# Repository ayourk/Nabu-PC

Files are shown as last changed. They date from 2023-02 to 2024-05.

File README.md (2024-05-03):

# Nabu-PC
PCB Schematics for the Nabu PC

Using KiCAD 6.0.x for this project.  I will accept pull requests against this version only.
Work still needs to be done to route the traces and connect the nets as well as add all of the capacitors, resistors, etc.  The goal of the chip layout in the schematic is to have the chip location to be roughly where it is on the physical board. I've been associating Datasheets and Footprints with all of my Symbols.  For cases of where I need custom symbols, I've been putting them in the local Nabu-PC library.

Please note that the `Docs/Nabu_Computer_Technical_Manual_by_MJP-compressed.pdf` does contain a vague schematic starting on page 18 of the PDF.  The goal of this project is to improve upon that by giving specific IC pin numbers to the the various similar symbols' inputs and outputs.

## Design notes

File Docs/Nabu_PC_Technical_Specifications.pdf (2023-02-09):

u

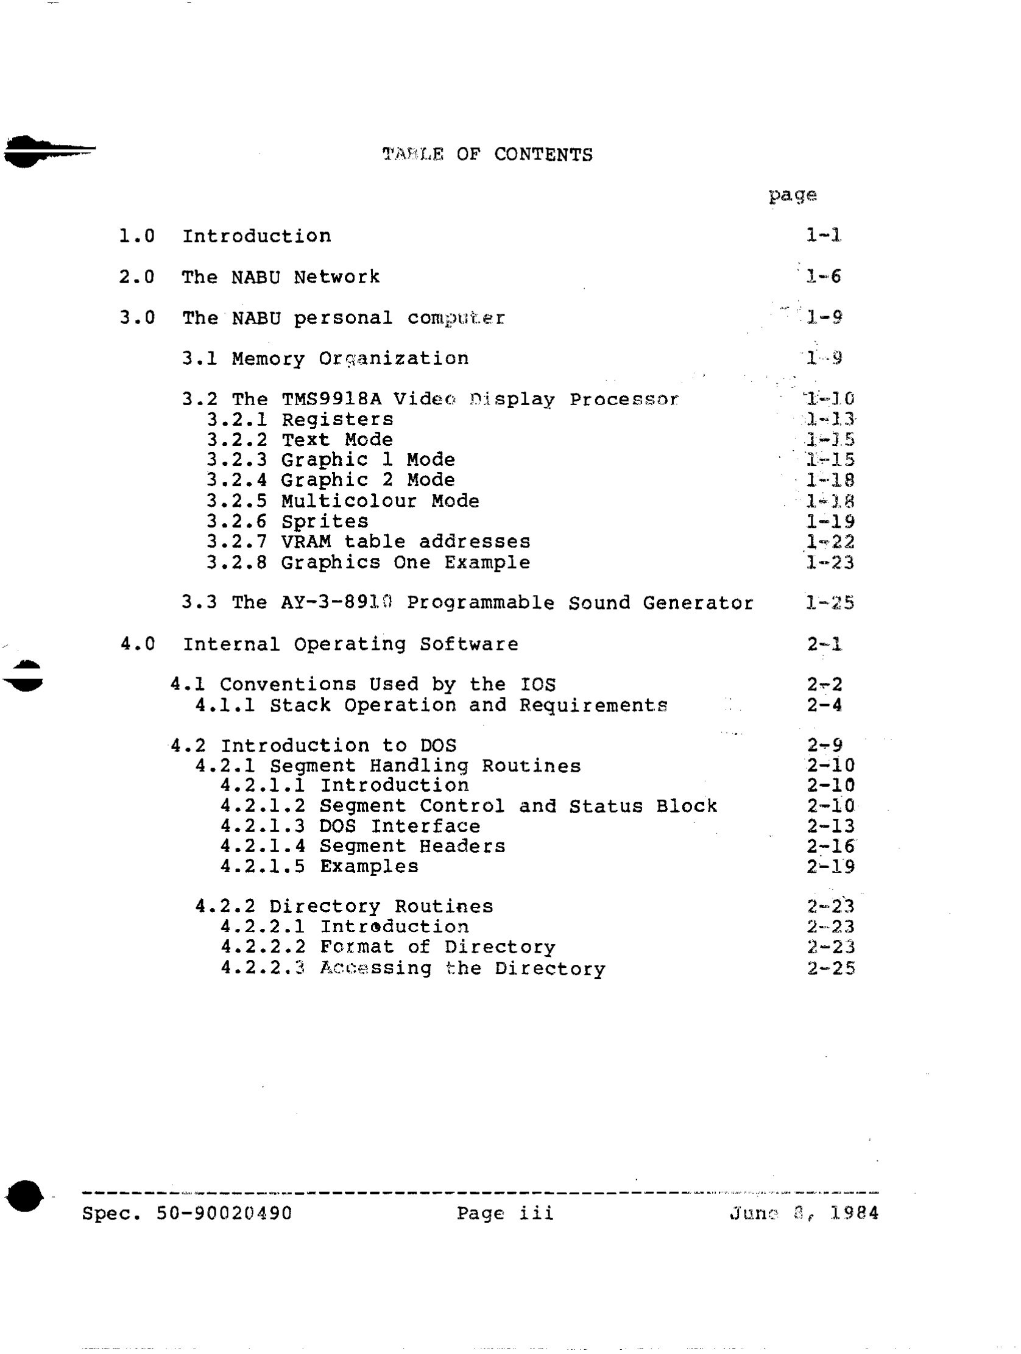
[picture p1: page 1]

n

•

'l'API,E OF CONTENTS

1.0 | Introduction
2.0 | The NABU Network
3.0 | The NABU personal computer:
| 3.1 Memory Orsanization 3.2 The TMS9918A Video n:lsplay Processor· 3.2.1 Registers
3. 2. 2 Text Mode
| 3.2.3 Graphic 1 Mode 3.2.4 Graphic 2 Mode 3.2.5 Multicolour Mode 3.2.6 Sprites 3.2.7 VRAM table addresses 3.2.8 Graphics One Example

page

1-1

l-6

1-9
·1-9

. "1··10
1-J:l
1-15
. 1~15
. 1-·18
1"'18
1-19
.1··22
1··23
3.3 The AY-3-8910 Programmable Sound Generator | 1-25
4.0 | Internal Operating Software
4.1 Conventions Used by the IOS
4.1.1 Stack Operation and Requirements
4.2 Introduction to DOS | 2-9
4.2.1 Segment Handling Routines | 2-10
4.2.1.1 Introduction | 2-10
4.2.1.2 Segment Control and Status Block | 2-10
4.2.1.3 DOS Interface | 2-13
4.2.1.4 Segment Headers | 2-16
4.2.1.5 Examples | 2:...19
4.2.2 Directory Routines | 2-23
4.2.2.1 Intr~duction | 2-23
4.2.2.2 Format of Directory | 2-23
4.2.2.3 Accessing the Directory | 2-25
Spec. 50-90020490 | Page iii | J·unc 8, 1984

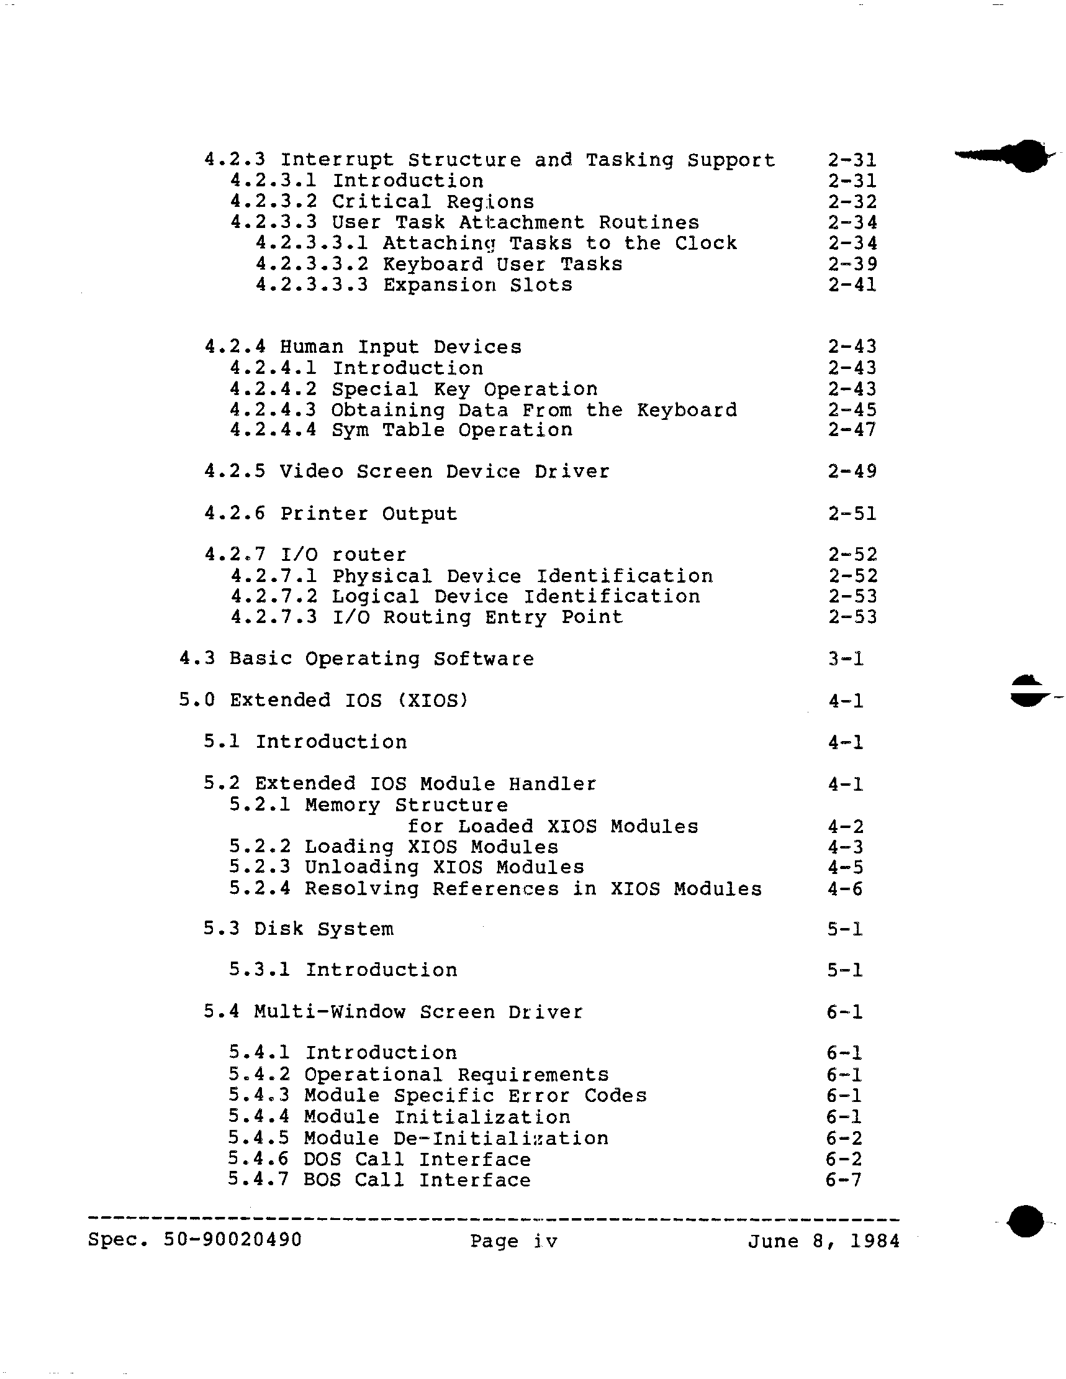
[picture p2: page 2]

4.2.3 Interrupt Structure and Tasking support 4.2.3.1 Introduction
4.2.3.2 Critical Regions
4.2.3.3 User Task Attachment Routines 4.2.3.3.1 Attachin~! Tasks to the Clock 4.2.3.3.2 Keyboard User Tasks 4.2.3.3.3 Expansion Slots

2-31
2-31
2-32
2-34
2-34
2-39
2-41
4.2.4 Human Input Devices | 2-43
4.2.4.1 Introduction | 2-43
4.2.4.2 Special Key Operation | 2-43
4.2.4.3 Obtaining Data From the Keyboard | 2-45
4.2.4.4 Sym Table Operation | 2-47

4.2.5 Video Screen Device Driver

4.2.6 Printer Output
4.2.7 I/O router
4.2.7.1 Physical Device Identification 4.2.7.2 Logical Device Identification 4.2.7.3 I/O Routing Entry Point

4.3 Basic Operating Software

5.0 Extended IOS (XIOSJ

5.1 Introduction

2-49

2-51
2-52
2-52
2-53
2-53

3-1

4-1

4-1
5.2 Extended IOS Module Handler | 4-1
5.2.1 Memory Structure
for Loaded XIOS Modules | 4-2
5. 2. 2 Loading XIOS Modules | 4-3
5.2.3 Unloading XIOS Modules | 4-5
5.2.4 Resolving References in XIOS Modules | 4-6
5.3 Disk System
5.3.1 Introduction

5.4 Multi-Window Screen Driver 5.4.1 Introduction
5.4.2 Operational Requirements 5.4.3 Module Specific Error Codes 5.4.4 Module Initialization
5.4.5 Module De-Initiali:~ation
5.4.6 DOS Call Interface
5.4.7 BOS Call Interface
Spec. 50-90020490 | Page j v

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
June a, 1984 | ••••

•

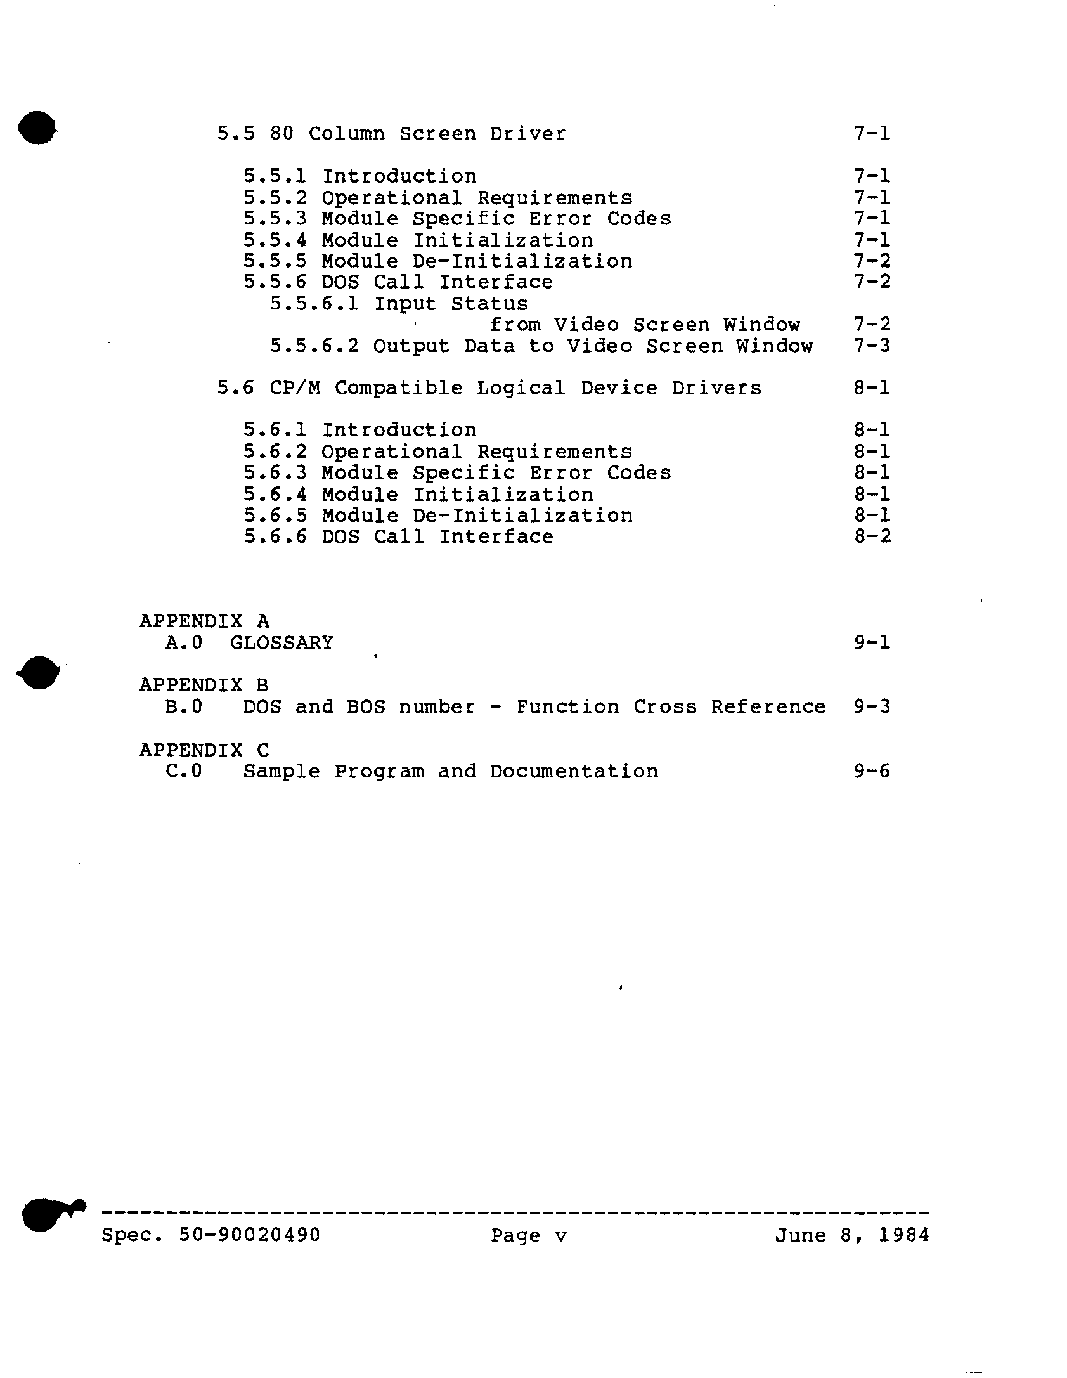
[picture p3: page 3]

•

5.5 80 Column Screen Driver | 7-1
5.5.1 Introduction | 7-1
5.5.2 Operational Requirements | 7-1
5.5.3 Module Specific Error Codes | 7-1
5.5.4 Module Initialization | 7-1
5.5.5 Module De-Initialization | 7-2
5.5.6 DOS Call Interface | 7-2
5.5.6.1 Input Status
from Video Screen Window | 7-2
5.5.6.2 Output Data to Video Screen Window | 7-3
5.6 CP/M Compatible Logical Device Drivers | 8-1
5.6.1 Introduction
5.6.2 Operational Requirements
5.6.3 Module Specific Error Codes
5.6.4 Module Initialization 5.6.5 Module De-Initialization 5.6.6 DOS Call Interface

APPENDIX A
A.O GLOSSARY
APPENDIX B

8-1
8-1
8-1
8-1
8-1
8-2

9-1

B.O DOS and BOS number - Function Cross Reference 9-3 APPENDIX C
C.O | Sample Program and Documentation | 9-6
Spec. 50-90020490 | Page v | June 8, 1984

•

THIS PAGE LEFT INTENTIONALLY BLANK
•
Spec. 50-90020490 | Page vi | June 8, 1984

•

•

INTRODUCTION

1.0 INTRODUCTION
This document is intended to provide the application programmer
the | necessary | information and reference material to write
application programs for the NABU personal computer. | Complete
programm~ng | information on the internal operating software (!OS)
as well as programming information of the Video display processor and the programmable sound generator are included.

One of the aims of this manual was to collect all the information that was previously found in several documents into just one. Although this has yielded a document of some 200 pages, each section discusses a single concept related to the programming
environment | at NABU. | Therefore the programmer need | only
investigate the portions of interest and not have to | read the
entire manual.
In order to put the IOS into perspective, | we include here a
section | from | the | !OS Specification which spells out | the
general functional requirements of IOS. | This will enable you to
judge | what to expect | from | the | Internal Operating System.
DESIGN REQUIREMENTS

Overview

This design | specification defines the | Internal Operating
Software (!OS) for the NABU Personal Computer (NPC), | a | low-
cost, | expandable personal computer. | It is unique because it
is capable of communicating on one-way, | hybrid and two-way
cable systems and telephone networks, as well as operating in a stand-alone mode, depending on which options are selected. When used in association with a CATV network the NABU P.C.'s prime function is to run software downline loaded from the cable head-end.
A versatile set of internal operating system and device handling software is required for the NABU P.C. to run appli-
cations software under control of a user. | For definition and
development purposes this software, | collectively referred to
as the Internal Operating Software (!OS) consists of:

o Applications program interfaces to !OS facilities
o All physical device control and I/0 handlers
o Basic task controlling and interrupt handling software o Communications Software
Spec. 50-90020490 | Page 1 - 1 | June 8, 1984

INTRODUCTION

The internal operating software does NOT include:
o Human Interface for Selection of Applications Programs
o Any ROM Software in the NPC
o Programming languages | (eg. | BASIC is not part of the
operating system.)
o Monitors <ie. examine and change memory, etc., etc. ,etc) o High-level <user oriented) utilities

Operating Environment

The | IOS must interact with four other functional | components
of the NABU P.c •. These are:
o The Basic NABU P.C. hardware
o Optional hardware and peripheral devices
o Communications with external systems,
including the keyboard and NABU Adaptor (NA)
o Applications Software
It | is | the | requirements and functions of these components
which essentially define the requirements for the IOS.

Internal Operating Software Requirements

The | fundamental | requirement of the | Internal | Operating
Software is to create an environment which supports the loading and execution of applications programs in a simple, efficient manner. The NPC hardware, its peripherals, communi-
cations and the IOS are really just necessary evils | required
to present content to an NPC user. | The IOS provides a stable
interface which allows applications access to the other | NPC
components while hiding the messy details of the hardware configuration and communications protocols, which are really of no interest to applications programs.

IOS Flexibility
In order | to be as flexible as possible, | the | IOS | resides
completely in RAM. | A separate program, | the MAIN MENU pro-
gram, | is | loaded in along with the IOS when the NABU P.C. is
"booted". | The MAIN MENU performs all human interface func-
tions required to load in an application.
Spec. 50-90020490 | Page 1 - 2 | June 8, 1984

•

•

•

•

•

INTRODUCTION

A number of expansion options will be offered for | the NPC •
These options may include: | standalone operation through use
of ROM readers and/or floppy disks, additional communications
options though the use of telephone dialers, | two-way | cable
moderns and other devices, | and the support of various other
peripherals via an I/O expansion bus. | The !OS must be | able
to operate in a configuration independent manner. | This
implies:
o The !OS must be able to sense the NPC configuration when "Booted"
o The IOS should protect the applications from becoming "configuration-dependent"
o Standard I/O handling procedures and I/O routing must be included in the !OS
o The IOS may be required to operate using different types of primary storage devices.

Applications Interfacing

As was mentioned earlier the NPC and IOS exist to run appli-
cations. | In this sense applications software is the highest
level of software and it is in control of the IOS. | Different
applications have different | requirements. | Animated video
games and other applications which require rich active human
interfaces will require fast, | efficient, unadorned access to
NPC devices. | At the other end of the scale are many of the
computation type applications which are willing to sacrifice speed for I/O independence and ease of use. Other software such as a screen-oriented word processor lies between the two extremes of support.
This implies:

o Applications must have as much control as possible over the !OS
o Applications should be able to access IOS features at a number of different levels
o | !OS support should be | designed to fit | applications
requirements and not vice versa

Real Time Requirements
Unlike many other microcomputer operating environments, | the
NPC will have time-critical tasks. | The most obvious of these
is communications on the CATV network. | However many of the
applications planned for the NPC have real-time components •
Spec. 50-90020490 | Page 1 - 3 | June 8, 1984

INTRODUCTION

This implies:

o The lower layers of the !OS must be as time-efficient as possible
o Interrupts must be well supported in the !OS
o Applications software has as much control as possible over the enabling of interrupts and the complexity of interrupt handling
o Some simple tasking constructs should be provided
o Attachment | of applications supplied code | to interrupt
handlers should be supported where possible
o Real-time counters {60Hz rate) should be supported by the !OS

Application Time-out Requirement

Due to the T.V. | screen being used for the basic output dev-
ice, | if no | keyboard input is received for long periods of
time {approx. | 20 to 30 minutes), | the T.V. screen will | go
blank {to prevent burning of the TV screen). | This assumes
that the clock interrupt is running, | inorder to do the tim-
ing. | The program execution must continue even though no-
thing is being displayed. | When any key on the keyboard is
activated, | the T.V. | screen will return back to its normal
display. | The keystroke which re-activates the screen is not
passed on to the application program. | {This time-out will
also be active if the NPC is in the "PAUSED" mode.} | ~he eftxy exee~~±eft | ~e | ~±me-e~~ | req~±remeft~ ±e ~he | eaee where ~he
N•P•€• ±e ±ft a ha%~ ⁴ me~e beea~ee ~he P~aSE key hae beeft ae~±va~e~. | ~he P~SSE f~fte~±eft eaHses ~he ~es ~e exee~~e ±ft a
very ~±gh~ %ee~T | Hft~±% P~SSE f~fte~±eft ±e ~eae~±va~ed• | ~h±e
~±gh~ | %ee~ | eeafte ~he keybeard fer ~he | ae~±va~±eft | e£ ~he
P~SSE7 ~~N~6T aftd S¥M keye.

Size Requirements

The total size of the !OS Kernel should not exceed lOK bytes and shall be kept to a minimum. In order to accommodate all the different !OS functions, the !OS will be divided into two
sections. | The first section will be called the Kernel. | This
will form a "bare bones" type !OS. | The remainder of the !OS
will form the second section which is called the Extended !OS
(XIOSl. | As applications require functions which are only
found in the XIOS, | the application will be able to load in
the necessary sections {modules) of the XIOS, | and then use
the functions. | When the functions are no longer necessary,
the XIOS module can be deleted, thus freeing up memory space.
Spec. 50-90020490 | Page 1 - 4 | June 8, 1984

•

•

•

•

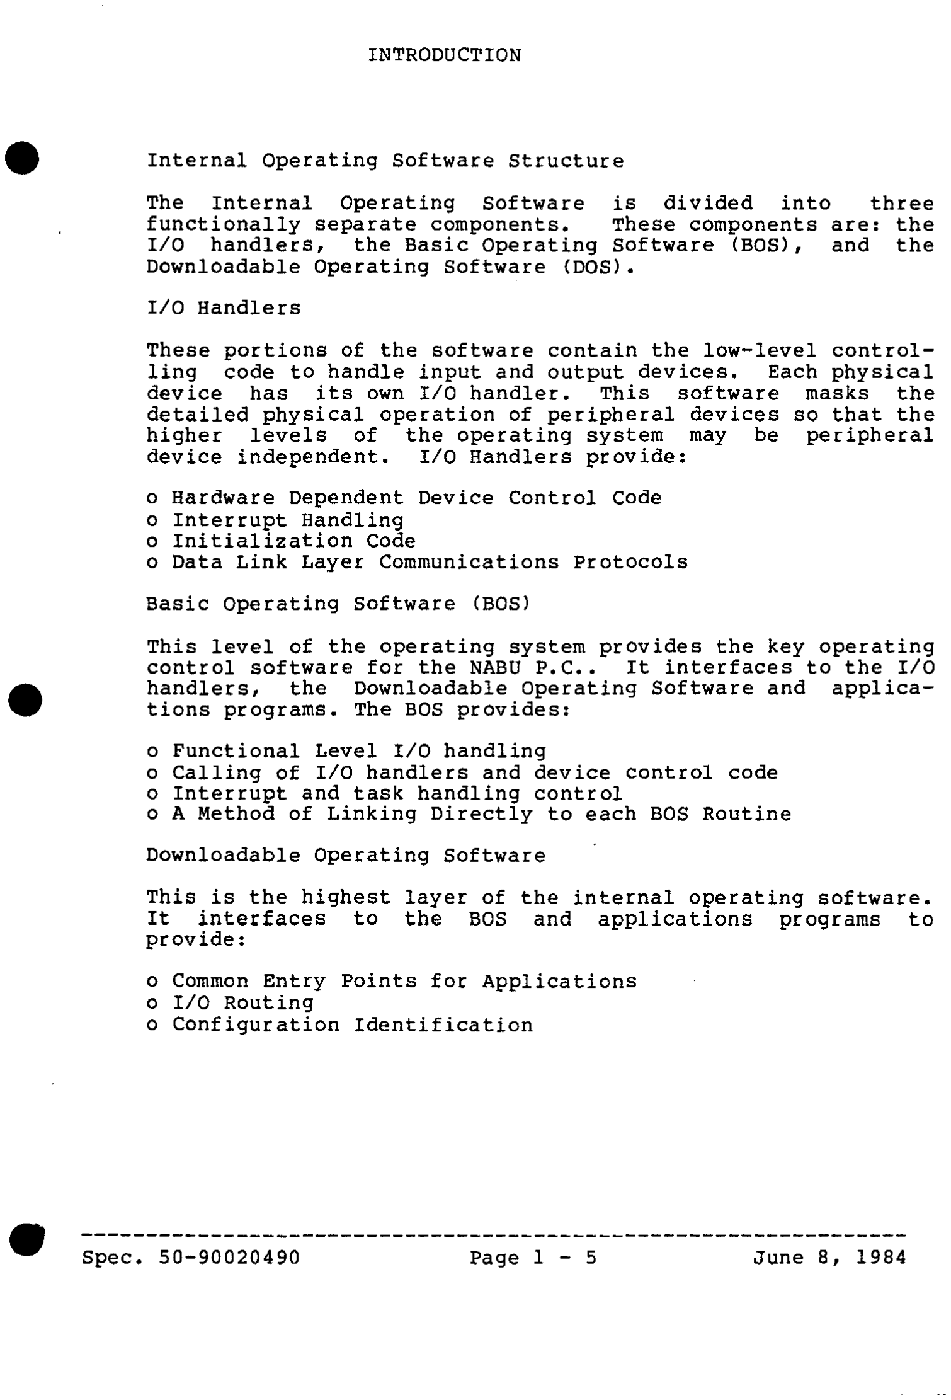
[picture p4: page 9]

•

•

INTRODUCTION

Internal Operating Software Structure

The | Internal Operating Software | is divided into | three
functionally separate components. | These components are: the
IIO handlers, | the Basic Operating Software (BOS), | and the
Downloadable Operating Software (DOS).
I/0 Handlers

These portions of the software contain the low-level control-
ling code to handle input and output devices. | Each physical
device | has | its own I/0 handler. | This | software masks | the
detailed physical operation of peripheral devices so that the
higher | levels of the operating system may be | peripheral
device independent. | I/O Handlers provide:
o Hardware Dependent Device Control Code
o Interrupt Handling
o Initialization Code
o Data Link Layer Communications Protocols
Basic Operating Software (BOSl

This level of the operating system provides the key operating
control software for the NABU P.C •• | It interfaces to the I/0
handlers, | the Downloadable Operating Software and applica-
tions programs. The BOS provides:
o Functional Level I/0 handling
o Calling of I/0 handlers and device control code
o Interrupt and task handling control
o A Method of Linking Directly to each BOS Routine Downloadable Operating Software
This is the highest
It interfaces to
provide:

layer of the internal operating software. the BOS and applications programs to

o Common Entry Points for Applications o IIO Routing
o Configuration Identification
Spec. 50-90020490 | Page 1 - 5 | June 8, 1984

NABU NETWORK

2.0 THE NABU NETWORK

The NABU Network was formed on the idea of linking a
microcomputer | to the cable network. | The union of these two
technologies has paved the way for | the introduction of a
microcomputer | complete with a large base of software into the
homes of the population at large.

This section will describe the various links in the chain of this Network with a view to giving a broad understanding of the pathway followed by an application program from the cable company
to the end user's RAM. | Refer to the diagram for | a pictorial
representation of this data flow.

The Head End

As the name suggests, | this is the originating node | in the
Network. | The Head End is actually a minicomputer and it is here
that all the programs and data to be broadcast on the cable are
found. | The Head End minicomputer is constantly outputing the
information in its database and it does so in a cyclic fashion - when all the information has been sent, | the mini starts at the
beginning and re-sends the database. | This cyclic nature of the
data flow enables one to envision the data as being written on the edge of a wheel which is read as it revolves.
Each | application | on | the | "wheel" | is tagged
identification number. | This number becomes important
other end of the NABU Network to select the proper user tion.

with an
at the
applica-

The Head End
database. Any
with in order to
as these changes

is also responsible for the maintenance of this additions or deletions must be carefully dealt ensure the overall integrity of the information will alter the "diameter" of the "wheel".

The RF Modulator

The information
digital in nature.
data signal must
this function.

Spec. 50-90020490

output by the Head End m~n~ | is of course
Before this can be put onto the cable, | the
be modulated. | The RF modulator will perform
Page 1 - 6 | June 8, 1984

•

•

•

NABU NETWORK

~ The Combiner

•

•

Since there are other services on the cable (eg. | TV, | radio),
there must be another piece of equipment that will merge the NABU programs with that information. The Combiner performs this task. The NABU information is now broadcast on a specific channel and sent into the cable for distribution.

The Adaptor

The Adaptor is a piece of hardware that acts as the interface between the cable coming into the home of the NABU user and the NABU Personal Computer.
Essentially, the Adaptor performs the reverse functions of the
Combiner and the RF Modulator. | It is tuned to listen to the NABU
channel, | de-modulate the signal and convert it into the digital
data that the NABU PC can understand.
On the cable side, the Adaptor is only capable of listening to the information coming down the cable - it cannot send commands
back to the Head End. | However, | on the PC side of the Adaptor
there is two-way communication. | The PC can tell the Adaptor what
it wishes from the cable and the Adaptor can inform the PC when that data is available to be read •
Thus, | when the user requests a particular application, the PC
sends a | Read | command and the identification number of the
application to the Adaptor. | The Adaptor then "listens" | to the
cable until | the appropriately identified data appears. | The
Adaptor fills its internal buffer and then informs the | PC that
the data is ready. | The PC obtains the data from | the Adaptor
putting it into the appropriate location in the RAM of the PC •
Spec. 50-90020490 | Page 1 - 7 | June 8, 1984

•

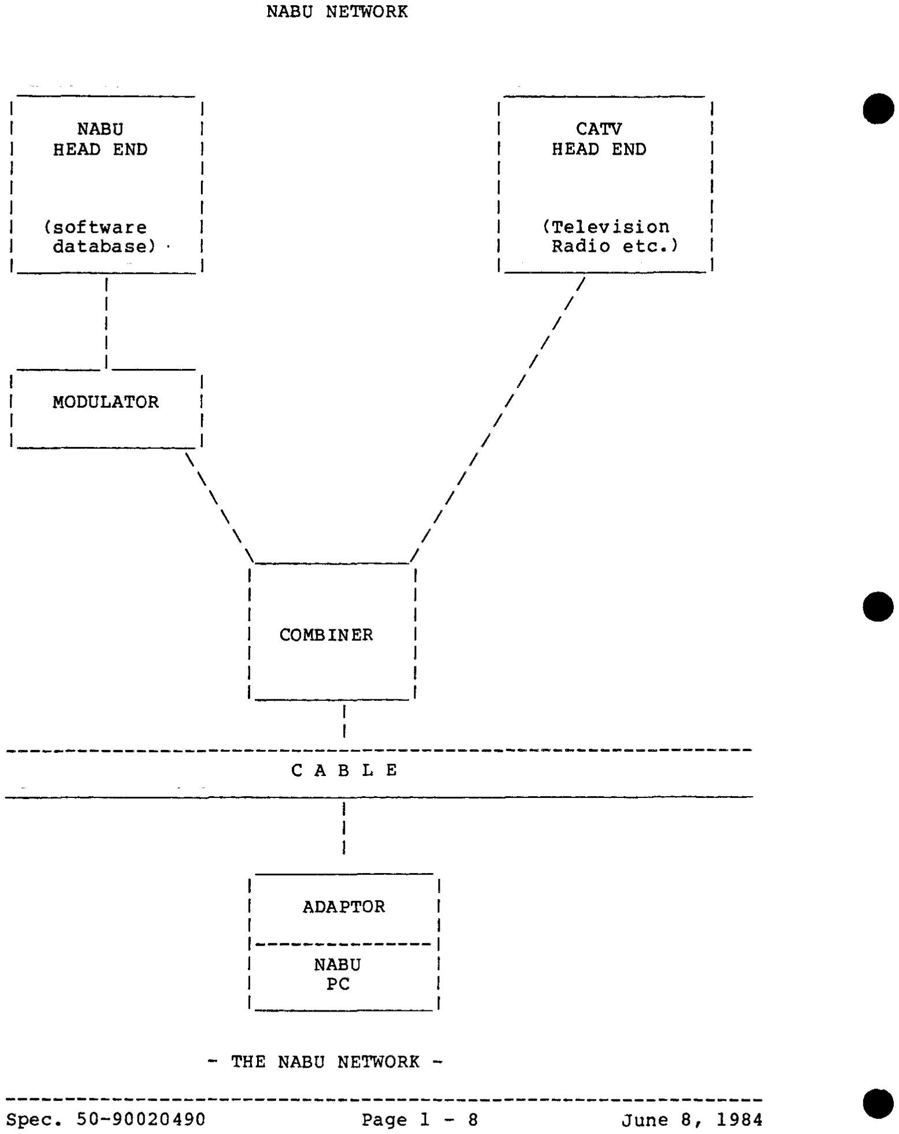
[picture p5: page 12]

NABU
HEAD END

(software
database)

NABU NETWORK

I | I
MODULATOR | I | I
I | I
------:-1 | I \ | I
\ | I
\ | I
\ | I
\ | I , ______ 1
I | I
I | I
I | I
I | COMBINER | I
I | I
I | I
I | I

C A B L E

I
I | ADAPTOR
I | | I 1---------------1
I | NABU | I
I | PC | I
I | | I
- THE NABU NETWORK -
Spec. 50-90020490 | Page 1 - 8

I

CATV
HEAD END

(Television
Radio etc.)

I

I
I
I

June 8, 1984

•

•

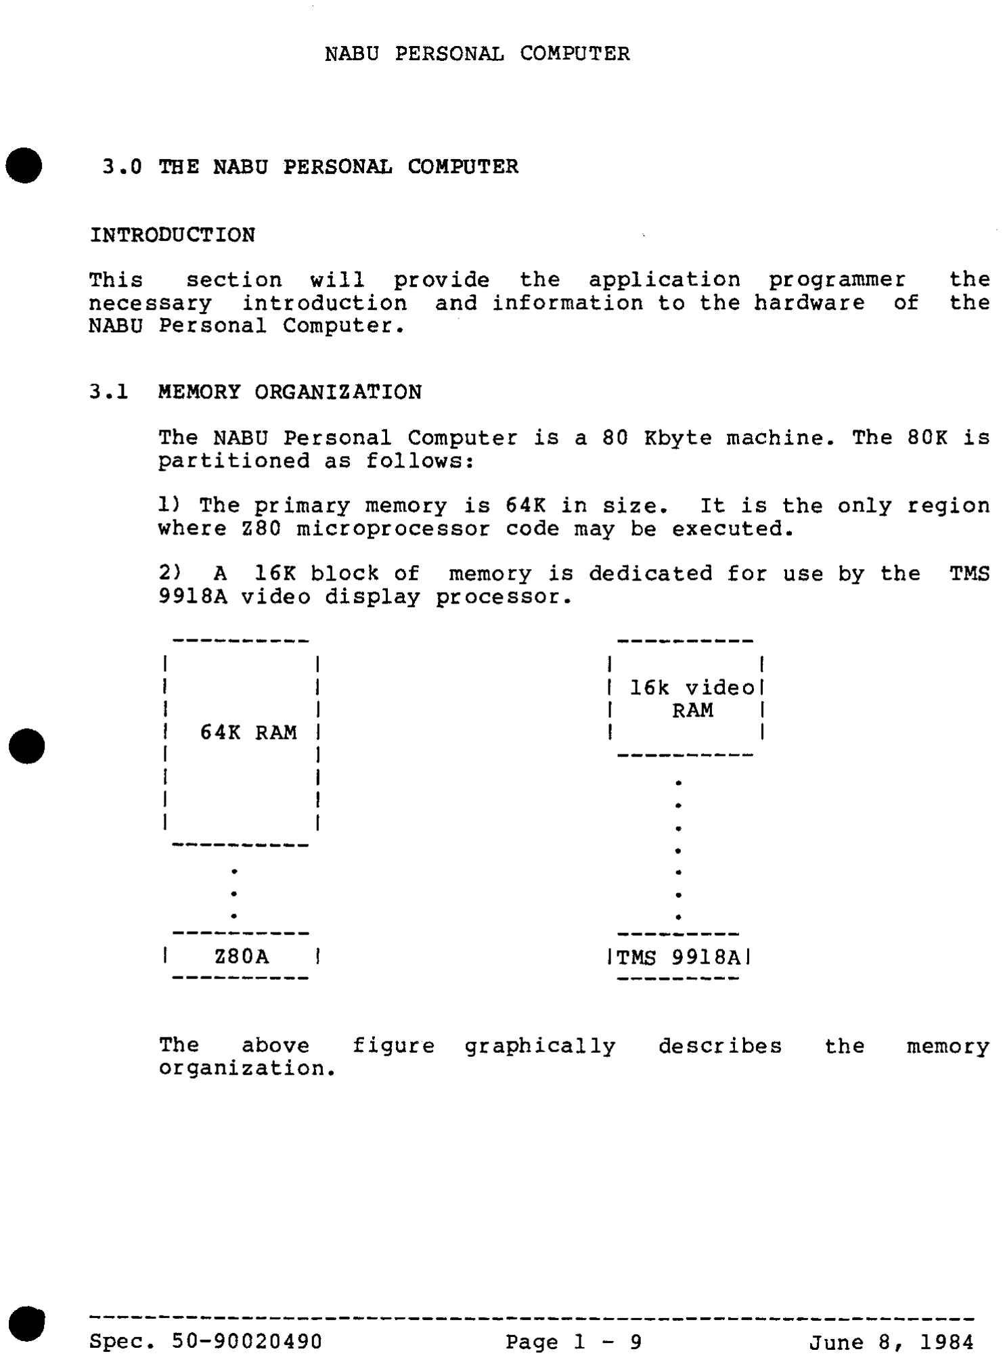
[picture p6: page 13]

NABU PERSONAL COMPUTER

- 3. 0 THE NABU PERSONAL COMPUTER

•

•

INTRODUCTION
This | section will provide | the application programmer | the
necessary | introduction and information to the hardware of | the
NABU Personal Computer.

3.1 MEMORY ORGANIZATION

The NABU Personal Computer is a 80 Kbyte machine. The 80K is
| partitioned as follows:
ll The primary memory is 64K in size. | It is the only region
where Z80 microprocessor code may be executed.

2l A 16K block of memory is dedicated for use by the TMS 9918A video display processor.

64K RAM

I
16k video!
RAM | I I
| Z80A | | ITMS 9918AI
The | above | figure | graphically
organization •
Spec. 50-90020490 | Page 1 - 9
describes | the | memory

June 8, 1984

VIDEO DISPLAY PROCESSOR

3.2 THE TMS 9918A VIDEO DISPLAY PROCESSOR

The TMS 9918A Video Display Processor (VDPJ is | responsible
for all video display for the NABU Personal Computer | (NPCJ.
It provides for text, | graphics | and animation. | Detailed
knowledge | of the control of the VDP is not required since
all functions of the VDP are accessed through | routines
provided | in the Internal Operating System (IOSJ of the NPC.
This section will outline the features of the VDP and the
use of IOS routines to generate T.V. | images for display on
the NPC. | Further | information may be found in the Texas
Instruments 9900 Data Manual | (TMS9918A/TMS9928A/ TMS9929A
Video Display Processors).

The VDP produces a T.V. image that can be envisioned as a series of display planes. Each plane has a display priority.
An image | on a plane of higher priority will overwrite an
overlapping image on a lower priority plane. | The display
planes in order of lowest to highest priority are BACKDROP,
PATTERN, | and SPRITE. Sprites are special animation objects.
The VDP provides 32 sprite planes, | with sprite plane 1
having the highest priority.

The lowest priority plane is the BACKDROP, which consists

•

of a single colour. | It can be set to any one of 15 colours. | •
The area | covered by the backdrop plane is larger that the
other planes, | and can form a border for the pattern plane.
With the T.V. | displays commonly used with the NPC, | the
border effect is generally limited to the top and bottom of the screen, while the side borders are cropped by the T.V. overscan. The colour of the backdrop is determined by write-only register 7 of the VDP (see 3.2.1 REGISTERS).
The image | displayed in the pattern plane is determined by
the contents of 16K of Video RAM (VRAMl provided for | the
VDP. | The | contents of the PATTERN NAME TABLE (Name Table),
PATTERN GENERATOR TABLE (Pattern Table), | and COLOUR TABLE
allocated in VRAM define the pattern plane image. | The mode
of the VDP determines the size and organization of the
tables and hence | the way in which VRAM is mapped to the
screen. | The VDP can operate in any one of four modes, Text,
Graphics I, Graphics II, and Multicolour.

The images displayed in the sprite planes are defined in the SPRITE ATTRIBUTE TABLE and SPRITE PATTERN GENERATOR TABLE.
These tables are also allocated in VRAM, and perform the
sprite equivalents of pattern plane tables.
Spec. 50-90020490 | Page 1 - 10 | June 8, 1984 | •

•

•

•

VIDEO DISPLAY PROCESSOR

The VDP produces a screen image with an absolute resolution of 256 X 192 pixels. The VDP divides the pattern plane into blocks of pixels called patterns. In Text mode, the patterns
are 6 | X 8 pixels, | yielding 40 text pattern per line. | In
Graphics modes the patterns are 8 X 8 pixels | (32 patterns
per line>. | There is a one byte entry in the Name Table for
each pattern position on the | screen. | For | example, | in
Graphics modes, | the Name Table | is 768 bytes long | (32
patterns per row X 24 rows of patterns). | In Text mode, | the
Name Table is 960 bytes long <40 X 24). There is a | one-to-
one mapping of entries in the Name Table and screen pattern
positions (see Figure 1 for example). | The screen origin | is
defined as the top left corner.

+---+---+ - I OJ 11

1---+---+ - I 321 331
1---+---+

1---+---+ - 170417051
1---+---+ - 173617371
+---+---+ -
- - - +---+---+
I 301 311 - - - - - +---+---1 I 621 631 - - - - +---+---1
- +---+---+
173417351 - - - +---+---1
176617671 - - - +---+---+

Fig. 1. Graphics I Name Table Mapping The figure illustrates the pattern positions on a T.V screen with the VDP in Graphics I mode. The number associated with each position maps to the entry
(offset> | within the Name Table. | The Oth entry | in
the Name Table maps to the pattern position occupying the top left corner of the screen.

The Pattern Table determines which pixels will be turned on
within a pattern. | Each entry in the Pattern Table is eight
bytes | long. | The first byte of an entry defines the pixel
arrangement of the top row of a pattern, the second byte the second row and so on. A '1' bit specifies a pixel that is on
and a '0' bit specifies a pixel that is off. | The offset of
an entry | into the Pattern Table (i.e. | the entry number)
forms the 'name' of the pattern. | A pattern can be displayed
on the screen in any pattern position by writing its name
(offset) | to the appropriate entry in the Name Table. | The
number of patterns available in the Pattern Table depends on the mode of the VDP •
Spec. 50-90020490 | Page 1 - 11 | June 8, 1984

VIDEO DISPLAY PROCESSOR

The VDP is | capable of producing fifteen colours | plus
transparent. | The Colour Table determines the colours of the
pixels defined in the Pattern Table. | The high order | nibble
of a byte in the Colour Table defines the colour of the '1'
bits in the associated byte of the Pattern Table. | The low
order | nibble | defines the colour | of the | '0' | bits. | The
resolution of the mapping from Colour Table to ~attern Table is dependent on the mode of the VDP. The colours associated with each 4 bit nibble are shown in Table 1.
The base addresses of the VRAM tables are derived from | the
values contained in the VDP's write-only registers, | and are
subject | to | restrictions dependent on the mode of the VDP.
The | base addresses are defined by calling the specific | IOS
routine for that table, | which will set the correct bits | in
the appropriate VDP register. | This process does not require
a knowledge of the register addressing scheme.

HEX VALUE

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
| 9 A B
c
| D E F

COLOUR
Transparent
Black
Medium Green
Light Green
Dark Blue
Light Blue
Dark Red
Cyan
Medium Red
Light Red
Dark Yellow
Light Yellow
Dark Green
Magenta
Gray
White
Table 1. Colour Assignments
The 4 bit hex values in the first column produce the colour in the second column
Spec. 50-90020490 | Page l - 12 | June 8, 1984

•

•

•

VIDEO DISPLAY PROCESSOR

~ 3.2.1 REGISTERS

~

•

The VDP is equipped with eight write-only registers and a
single read-only status register. | The write-only | registers
are | used to define the mode of the VDP, | table addresses in
VRAM, and the backdrop colour. All access to these registers is by way of calls to routines in the IOS. Descriptions of these routines can be found in the section on BOS calls.
The write-only registers may be loaded with the IOS | routine
VREGWR. | Specialized routines are provided for | specifying
VRAM table addresses. | In the NPC environment a RAM image of
the write-only registers is maintained, allowing examination of register contents. The registers may be 'read' by calling VREGRD, or with specialized routines (see IOS document).

REGISTER 0
REGISTER 1
These | two | registers contain VDP option control | bits. | In
practise, | they are not written to directly with VREGWR, but
rather are accessed through specialized routines. | VSETXT is
called to set the appropriate bits to place the VDP in TEXT
mode. | Other | routines are VSETGl (Graphics I) and | VSETG2
(Graphics II).
The VDP also has a 'vertical blanking' option | (the video
screen is "blacked out"> which is selected in | register 1.
The screen may be blanked with no effect on VRAM by calling the IOS routine VBLKON. The screen is restored with VBLKOFF. Other bits in register 1 determine the size and magnification of sprites (see 3.2.6 SPRITES).
REGISTER 2
Register | 2 defines the base address of the Name Table. | The
address is set by calling VNAMEST.
REGISTER 3

Register 3 defines the base address of the Colour Table. The address is set by calling VCOLRST.
REGISTER 4

Register 4 defines the base address of the Pattern Generator Table. The address is set by calling VPTRNST •
---------------------------------------------------------------- Spec. 50-90020490 | Page 1 - 13 | June 8, 1984

VIDEO DISPLAY PROCESSOR

REGISTER 5 | ~

Register 5 defines the base address of the Sprite Attribute
Table. The address is set by calling VATRIST.

REGISTER 6

Register 6 defines the base address of the Sprite Pattern Generator Table. The address is set by calling VSPRIST. REGISTER 7

The high order 4 bits of register 7 define the colour | code
of | '1' pixels in Text mode. | The low order bits define the
colour | code for '0' pixels in Text mode and the backdrop
colour | in all modes. | Register 7 is | loaded | by calling
VREGWR.

STATUS REGISTER

The status register contains the following flags.
F | - The | Interrupt Flag is set at the end of the raster
scan of the last line of the display. It is reset to 0 after the VDP Status Register is read or the VDP is reset.
c | The | Coincidence | Flag | flag | is
sprites have | '1' bits at the same
(see 3.2.6 SPRITES).
set | whenever | two
screen location.

5S The Fifth Sprite Flag is set whenever more than four sprites are displayed on the same horizontal line. The number of the fifth sprite is also loaded into the VDP status Register. (see 3.2.6 SPRITES).

Spec. 50-90020490 | Page 1 - 14 | June 8, 1984

~

~

VIDEO DISPLAY PROCESSOR

~ 3.2.2 TEXT MODE

~

~

As is | implied by the name, | Text mode | is primarily for
textual applications. | The Name Table and Pattern Table are
used to define the appearance of the screen. | The Colour
Table is not used. | Patterns are 6 X 8 pixels, | which allows
for an increase to 40 characters per line. The Name Table is
960 (40 X 24) bytes. | The Pattern Table contains the library
of text | patterns to be displayed. | It is 2048 bytes long,
consisting of 256 | eight byte entries. | Since each text
position is only 6 pixels wide, | the two least significant
bits of each row of the pattern are ignored. | There can only
be two colours for the entire screen, | one colour for all of
the '1' bits, | and a second colour for all of the '0' | bits.
The colours are defined in VDP register 7 | (see 3.2.1
REGISTERS).

Typically, text patterns are loaded into the Pattern Table, such that the entry number corresponds to the ASCII code for
the letter. | For example, | the ASCII code for the letter 'A'
is 65 <decimal>. | With the eight byte pattern fot tbe letter
'A' | occupying pattern number 65 in the Pattern Table, | the
letter can be written to screen pattern position 3 by writing 65 to the third entry in the Name Table (Figure 2).
Text mode | allows for | 40 characters per line on a | T.V
display. | However, | because of T.V. | overscan, | characters
should not | be written to columns 0,1,38 | or 39. | This
effectively reduces the display to 36 characters per line.

3.2.3 GRAPHICS I MODE

### The VRAM tables that are used to generate the screen imaqa

for Graphics I mode are the PATTERN NAME TABLE (Name Table), PATTERN GENERATOR TABLE (Pattern Table) and COLOUR TABLE. The Name Table determines the screen position for a pattern. T~e Pattern Table determines which pixels within a pattern Wlll be turned on. The Colour Table determines the colour of a pixel.

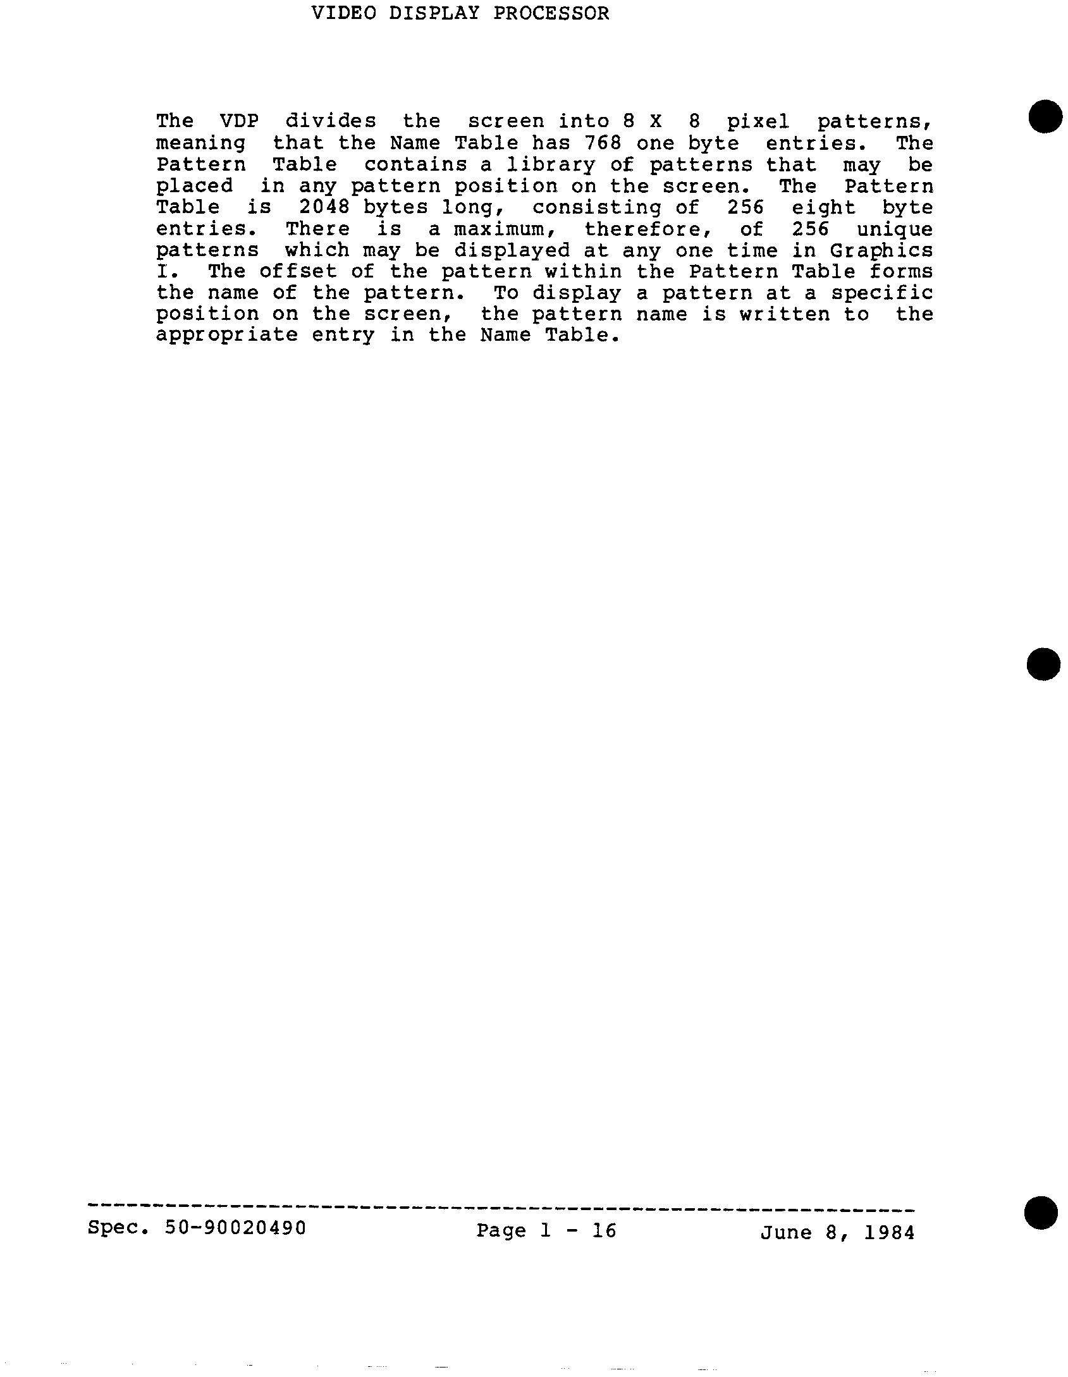
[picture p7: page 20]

VIDEO DISPLAY PROCESSOR

The VDP divides the screen into 8 X 8 pixel patterns, | ~ meaning that the Name Table has 768 one byte entries. | The

Pattern Table contains a library of patterns that may be
placed in any pattern position on the screen. | The | Pattern
Table is 2048 bytes long, | consisting of 256 eight byte
entries. | There is a maximum, | therefore, | of 256 unique
patterns which may be displayed at any one time in Graphics
I. The offset of the pattern within the Pattern Table forms
the name of the pattern. | To display a pattern at a specific
position on the screen, | the pattern name is written to the
appropriate entry in the Name Table.
---------------------------------------------------------------- Spec. 50-90020490 | Page 1 - 16 | June 8, 1984

~

~

•

## +--------+ <-- ENTRY 0

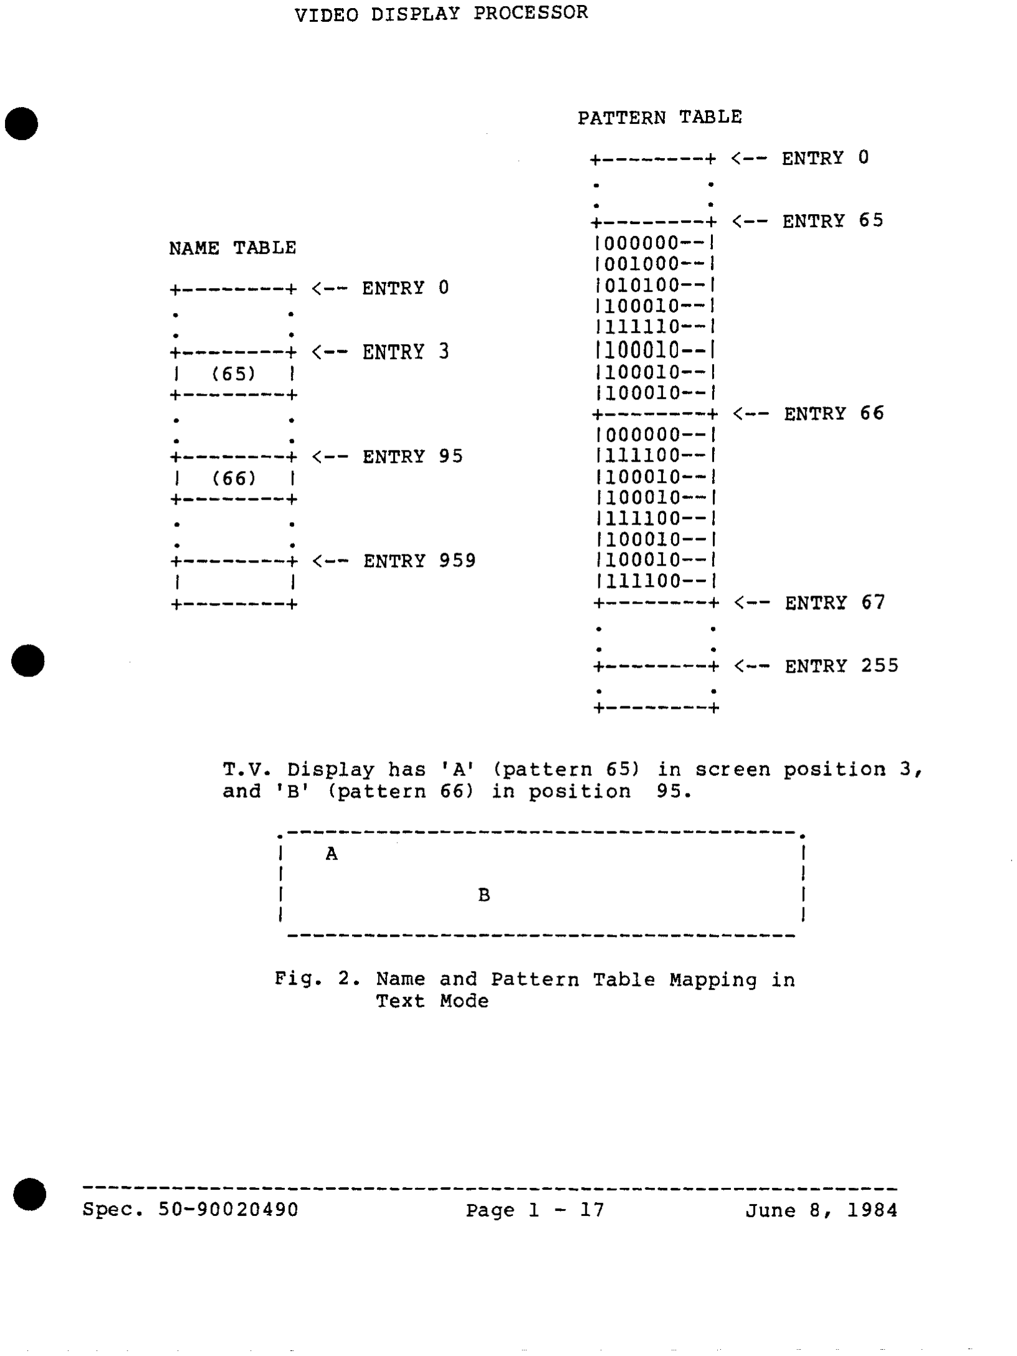
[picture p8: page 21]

•

•

VIDEO DISPLAY PROCESSOR

PATTERN TABLE

NAME TABLE

## +--------+ <-- ENTRY 3

I | < 6 5 l | I
+--------+

## +--------+ <-- ENTRY 95

I | < 66) | I
+--------+

## +--------+ <-- ENTRY 959

I | | I
+--------+

## +--------+ <-- ENTRY 0

## +--------+ <-- ENTRY 65

1000000--1
1001000--1
1010100--1
1100010--1
1111110--1
1100010--1
1100010--1
1100010--1

## +--------+ <-- ENTRY 66

1000000--1
1111100--1
1100010--1
1100010--1
1111100--1
1100010--1
1100010--1
1111100--1

## +--------+ <-- ENTRY 67

## +--------+ <-- ENTRY 255

+--------+

T.V. Display has 'A' (pattern 65) in screen position 3, and 'B' <pattern 66) in position 95.

A

B

Fig. 2. Name and Pattern Table Mapping in Text Mode

Spec. 50-90020490 | Page 1 - 17 | June 8, 1984

VIDEO DISPLAY PROCESSOR

The colours of pixels are specified in the Colour Table. The | •
colour | table contains 32 one byte entries. | Each entry
defines two colours, | the high order nibble of each entry
defines the colour of the '1' bits, and the low order nibble
defines the colour of the '0' bits. | The first entry in the
Colour | Table defines the colours for patterns 0 - 7, | the
second entry for patterns 8 - 15 and so on. | This | scheme
imposes the following colour | restrictions: | 1) | any one
pattern can only display two colours and 2) | changing the
colours for one pattern implies a colour change | for | the
seven other patterns within the colour group.

3.2.4 GRAPHICS II MODE

Graphics II mode is similar to Graphics I mode except that the Pattern and Colour Tables are longer.

The Pattern Table is expanded to 6144 bytes, | allowing | for
768 | unique patterns, | one for each pattern position on the
screen. | Since the one byte entries in the Name Table allow
for | a maximum of 256 unique entries, | Graphics II | segments
the Name Table into three blocks of 256 names each such that the first block maps pattern names to the upper third of the screen. The second and third blocks map pattern names to the
middle | and lower thirds of the screen respectively. | The
Pattern Table is similarily segmented. | Entries in the first
third of the Name Table map to patterns in the first | third
(2048 bytes, 256 patterns) of the Pattern Table.
The Colour Table is also expanded to 6144 bytes. | There are
768 eight byte entries. | Thus, there is one eight byte entry
in the Colour Table for each eight byte entry in the Pattern Table. The high order nibble of each byte defines the colour
of the | '1' bits in the corresponding byte of the Pattern
Table. | The colour | of the '0' bits is defined by the low
order nibble. | Thus in Graphics II mode, | two colours may be
defined for each row (byte) of a pattern. | The Colour | Table
is | segmented into three equal parts in the same manner | as
the Pattern Table.

3.2.5 MULTICOLOUR MODE

The VRAM tables that need to be allocated for Multicolour mode are the Name Table and Pattern Tables. The Colour Table
is not used, | colours are derived from the Pattern Table. As
Multicolour mode is rarely used, | a complete description is
not provided in this document. | Further information may be
found in the Texas Instruments 9900 Data Manual.
---------------------------------------------------------------- Spec. 50-90020490 | Page 1 - 18 | June 8, 1984

•

•

•

•

•

VIDEO DISPLAY PROCESSOR

The pattern plane is divided into blocks of 4 X 4 pixels (64 X 48 blocks). The colour of each block can be any one of the fifteen video display colours plus transparent. The backdrop and sprite planes are active.
The Name Table consists of 768 one byte entries. The name points to an 8 byte segment of VRAM in the Pattern Generator
Table. | The colour | to be displayed is determined by the
information contained in the Pattern Table.

3.2.6 SPRITES
Sprites are special animation patterns. Up to 32 sprites are available, one for each of the sprite planes. Sprites may be used in Multicolour and Graphics modes, but not in Text mode. Each of the sprites can cover an 8 X 8, 16 X 16, or 32
X 32 | pixel area on its plane. | Any part of the plane not
covered by the sprite is automatically transparent. | All or
part of each sprite can also be | transparent. | The highest
priority sprite is 0, | the lowest priority is sprite 31. All
sprites are of higher priority than the pattern and backdrop
planes. | The location of a sprite is defined by | the top
leftcorner of the sprite pattern. | The sprite can be | easily
moved pixel-by-pixel | by redefining the sprite origin | (!OS
call SPMOVE) •

The sprite Attribute Table and the Sprite Generator Table
are | allocated in VRAM. | These tables are the sprite
equivalents of the Pattern Name Table and Pattern Generator
Tables. | Each entry | in the Attribute Table is four | bytes
long, | with one entry for each of the 32 available sprites.
The first byte of an entry defines the vertical position of the sprite from the top of the screen in pixels. Values between -32 and 0 allow a sprite to bleed in from the top
edge of the backdrop. | A value of -1 causes the sprite to be
positioned at the top of the screen, | touching the backdrop
area. The second byte defines the horizontal position of the
sprite from the left edge of the display, A value of 0 positio~s | the spri~e against the left edge of the backdrop.
The th~rd byte ~ef~nes the name of the sprite. | This name
maps to the Spr~te Generator Table in the same way patterns are mapped from the Name Table to the Pattern Table. The low
order four bits of the fourth byte contain the colour | code
for | the | '1' | pixels of | the sprite | ('0' | pixels | are
transparent). The most significant bit of the fourth byte is
the_ Ear~y Cl~ck Bit. | When set to 'l', | the position of the
spr7te ~s sh~ft7d to the left by 32 pixels, | allowing the spr~te to bleed ~n from the left edge of the display •
---------------------------------------------------------------- Spec. 50-90020490 | Page 1 - 19 | June 8, 1984

VIDEO DISPLAY PROCESSOR

The Sprite Generator Table has up to 256 eight byte entries, | ~ for | a maximum of 2048 bytes long, | and is equivalent in
function | to the Pattern Generator Table. | The | lOS | routine
VSETSP | is | used to set the size and magnification of the
sprites. | Sprite size can be either 8 X 8 or 16 X 16 pixels.
With 8 X 8 pixel sprites, | the Generator Table uses eight
bytes to define the sprite. | When 16 X 16 sprites are used,
the Generator Table requires 32 bytes. | A 16 X 16 sprite is
effectively divided in to four equal quadrants, | with the
bytes in the Generator Table being mapped to the screen as
shown in Figure 3. | The sprites can also be magnified one or
two times. | With a magnifaction factor of two, | each bit in
the Generator Table | is mapped into 2 X 2 pixels on the
screen display.
There is a limit of four sprites on any horizontal line. | If
more sprites are positioned to the same line, | the four
highest priority sprites are displayed normally. | The fifth
and subsequent sprites are not displayed on that line. | The
fifth | sprite flag is set and the number of the fifth sprite
is loaded into the VDP Status Register.
A value | of DO Chexl in the vertical position field of an
entry | in the Sprite Generator Table terminates sprite pro-
cessing. This allows programmers to blank part or all of the
sprites. | The lOS routine SPMARK will write DO (hexl to any
sprite, | and marks the end of the active sprites in the
Attribute Table.

Whenever two active sprites have '1' bits at the same screen location, the coincidence flag in the VDP Status register is set.

Spec. 50-90020490 | Page 1 - 20 | June 8, 1984

•

•

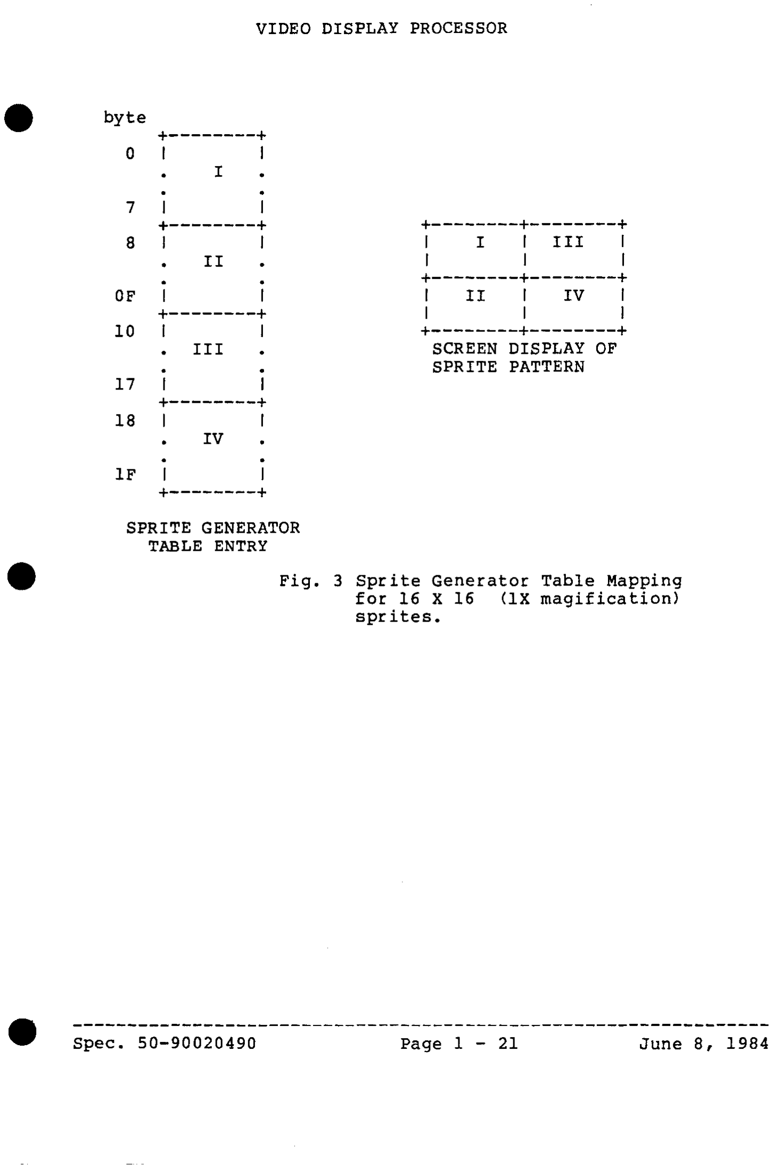
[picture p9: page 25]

•

•

VIDEO DISPLAY PROCESSOR

SPRITE GENERATOR
TABLE ENTRY

Spec. 50-90020490

Fig. 3 Sprite Generator Table Mapping for 16 X 16 (lX magification) sprites •

Page 1 - 21 | June 8, 1984

VIDEO DISPLAY PROCESSOR

3.2.7 VRAM TABLE ADDRESSES
There are certain restrictions on where tables may be
located in VRAM, | dependent on the mode of the VDP. For
example, | in Text mode, the Pattern Table is 2048 bytes
long, and must start on a 2 Kilobyte boundary in VRAM.
VDP MODE | TABLE | LENGTH (max) | VRAM BOUNDARY
Text | Name | 960 | lK
| Pattern | 2048 | 2K
Graphics I | Name | 768 | lK
| Pattern | 2048 | 2K
| Colour | 32 | 64-byte
Sprite Attribute | 128 | 128-byte
Sprite Generator | 2048 | 2K
Graphics II | Name | 768 | lK
| Pattern | 6144 | 8K
| Colour | 6144 | 8K
Sprite Attribute | 128 | 128-byte
Sprite Generator | 2048 | 2K

The conventions for the NPC environment are that the Pattern Table always starts at VRAM address o. The Name
Table is placed at the next available boundary. | In
Graphics II mode, | the Pattern Table is located at VRAM
address O, and the Colour Table at 8192.
Note that in Text and Graphics I modes several screens
may be defined in VRAM with multiple Name Tables. | Each
Name Table starts on a lK boundary. | To display a
particular screen, | the address of the desired Name
Table is written to VDP register 2 with the IOS routine
VNAMEST. | This is particularly useful for setting | up
several screens of text.
---------------------------------------------------------------- Spec. 50-90020490 | Page 1 - 22 | June 8, 1984

•

•

•

VIDEO DISPLAY PROCESSOR

4lt | 3.2.8 GRAPHICS I EXAMPLE

4lt

•

It is desired to place the following pattern at screen pattern position 255 (hex FF) in Graphics I mode using pattern number 8 in the Pattern Table. The pattern is to be black on a grey background.

* | * * | * * * ** | each * represents one pixel on the screen
** * * * | * * | *

PATTERN TABLE
entry 00 --> +--------+
I | | I

entry 08 --> +--------+
I | 81 | I
I | 42 | I
I | 24 | I
I | 18 | I
I | 18 | I
I | 24 | I
I | 42 | I
I | 81 | I
+--------+

NAME TABLE
entry 0 --> +--------+
I | | I
+--------+

entry FF --> +--------+
I | 08 | I
+--------+

(BIT MAP)
(10000001)
(01000010)
(00100100)
(00011000)
(00011000)
(00100100)
(01000010)
(10000001)

COLOUR TABLE
entry 0 --> +--------+
I | I
entry 1 --> +--------+
I | 10 | I
+--------+
---------------------------------------------------------------- Spec. 50-90020490 | Page 1 - 23 | June 8, 1984

•

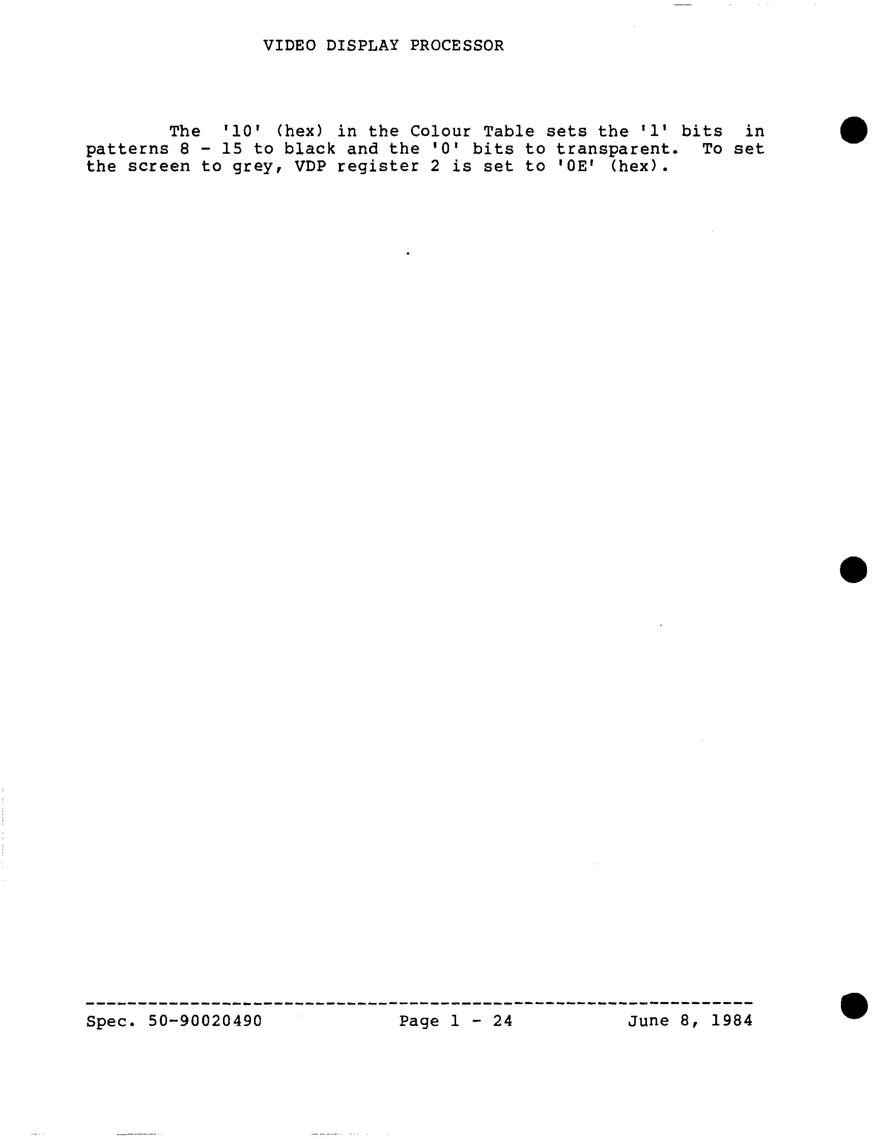
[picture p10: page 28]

VIDEO DISPLAY PROCESSOR

The | '10' (hex) in the Colour Table sets the '1' bits
patterns 8 - 15 to black and the '0' bits to transparent. | To
the screen to grey, VDP register 2 is set to 'OE' (hex).

in
set
Spec. 50-90020490 | Page 1 - 24 | June 8, 1984

•

•

THE SOUND GENERATOR

~ 3.3 The Programmable Sound Generator

•

•

As previously mentioned, | all sounds produced by
under | the control of the AY-3-8910 programmable
erator | (PSG). | This device uses 14 registers to
variety | of complex sounds. | The PSG has | three
channels to produce the sound effects.

the NPC are
sound gen-generate a
individual

Producing sounds using the audio generator may be divided into several sound generating blocks. They are:
1) tone generators
2) noise generator
3) amplitude control
4) envelope control
The | registers of the PSG are used to enable/disable each of
these blocks and to select the parameters of the channel | in
the PSG To read or write to the registers of the sound chip,
the | IOS BOS | routines AUDWR and AUDRD MUST be | used. | See
section 4.3
Register 0 and register 1 provide the period or frequency of
the tone to be produced by channel A of the PSG. | All 8 bits
of register 0 is used but only the lower 4 bits of | register
1 are used. | This provides a tone frequency resolution of 12
bits with register 1 containing the most significant 4 bits
and | register 0 providing the remaining 8 least | significant
bits.
Register 2 and register 3 provide the
the tone to be produced by channel B.
is provided with register 3 providing bits.

period of frequency of
Twelve bit resolution
the most significant 4

Similarily Register 4 and register 5 provide the tone period for channel C with register 4 providing the most significant 4 bits of the twelve bits .

Spec. 50-90020490 | Page 1 - 25 | June 8, 1984

THE SOUND GENERATOR

The following diagram should clarify the above information. coarse reg
I 31 21 11 0 I
reg 1,3,5
I
I

fine reg
I 71 61 51 41 31 21 11 01
reg 0,2,4
I
I
I
I
I
1111101 91 81 71 61 51 41 31 21 11 01 tone value of the channel

There are two formulae that relate output tone frequency to the value in the twelve bit register. They are:

and

Where

f= 223.750
tp

tp= 256ct + ft

f = the frequency of the sound to be generated tp= the tone period to be written to the registers ct= the coarse tune register (registers 1,3,5) ft= the fine tune register (registers 0,2,4)

Register 6
generated.
register 6
frequency.

provides the tone period of the noise to be It uses only the least significant 5 bits of and is the only register controlling the noise

Similarily, | the freqency of the output tone may be | related
to the noise period by the following formula:
f= 223750
np
Where f = the frequency of the noise to be generated np = the noise period to be written to register 6
Spec. 50-90020490 | Page 1 - 26 | June 8, 1984

•

•

•

•

•

•

THE SOUND GENERATOR

Register 7 enables and disables each of the three channels. Register 7 uses inverted logic therefore, a 1 indicates that the channel is disabled.

channel
function
I C | B | A I C | B | A I
I | NOISE | I | TONE | I

I 7 I 6 I 5 I 4 I 3 I 2 I 1 I 0 I -register 7

Bits 7 and 6 are not used for generating sounds.

Register 8, 9 and 10 controls the amplitude for channels A, B, and C respectively as well as the envelope pattern.
If bit 4 is zero then the least significant 4 bits provide the amplitude <volume) of the channel's sound. This provides 16 levels of amplitude with 15 being the greatest and 0 producing no sound.
If | bit 4 is 1 then envelopes
each channel | is determined
defined by the lower four bits

are enabled and amplitude
by the envelope pattern
of the register.

of
as
The | rema1n1ng | registers 11, 12 and 13 provide envelope
control. | There are two ways of controlling envelopes. First
is | to vary the frequency of the envelope using registers 11
and 12, | the | second way is to vary the shape and cycle
pattern of the envelope.
The envelope period may be resolved to 16 bits by combining
registers | 11 and 12. | Register 12 provides the most
significant 8 bits and register 11 provides the least
significant 8 bits. | As before, | 2 formulae may be used to
relate the envelope period to the output envelope frequency. They are:

f= 13984
ep

and
ep= 256ct + ft

Where
f =the desired envelope frequency ep =the envelope period
ct =the coarse tune register (reg 12) ft =the fine tuning register (reg lll
Spec. 50-90020490 | Page 1 - 27 | June 8, 1984

THE SOUND GENERATOR

Register 14 controls the envelope shape or cycle. Only the | 4lt
lower four bits of the register are used. | Each bit has an
individual function.
I 71 61 51 41 31 21 11 01 | register 14

----- hold -------- alternate ----------- attack

-------------- continue ----------------- not used -------------------- not used ----------------------- not used -------------------------- not used

If hold is set to 1 the envelope is limited to one cycle and holds the current state of the envelope counter.
If alternate is set to 1 the envelope reverses the direction after each cycle.
If attack is set to 1, the envelope will count up.
If attack is set to 0, the envelope will count down.
If countinue is set to one the cycle pattern will be defined by the hold bit otherwise the envelope counter will reset to zero and then hold.
---------------------------------------------------------------- Spec. 50-90020490 | Page 1 - 28 | June 8, 1984

4lt

•

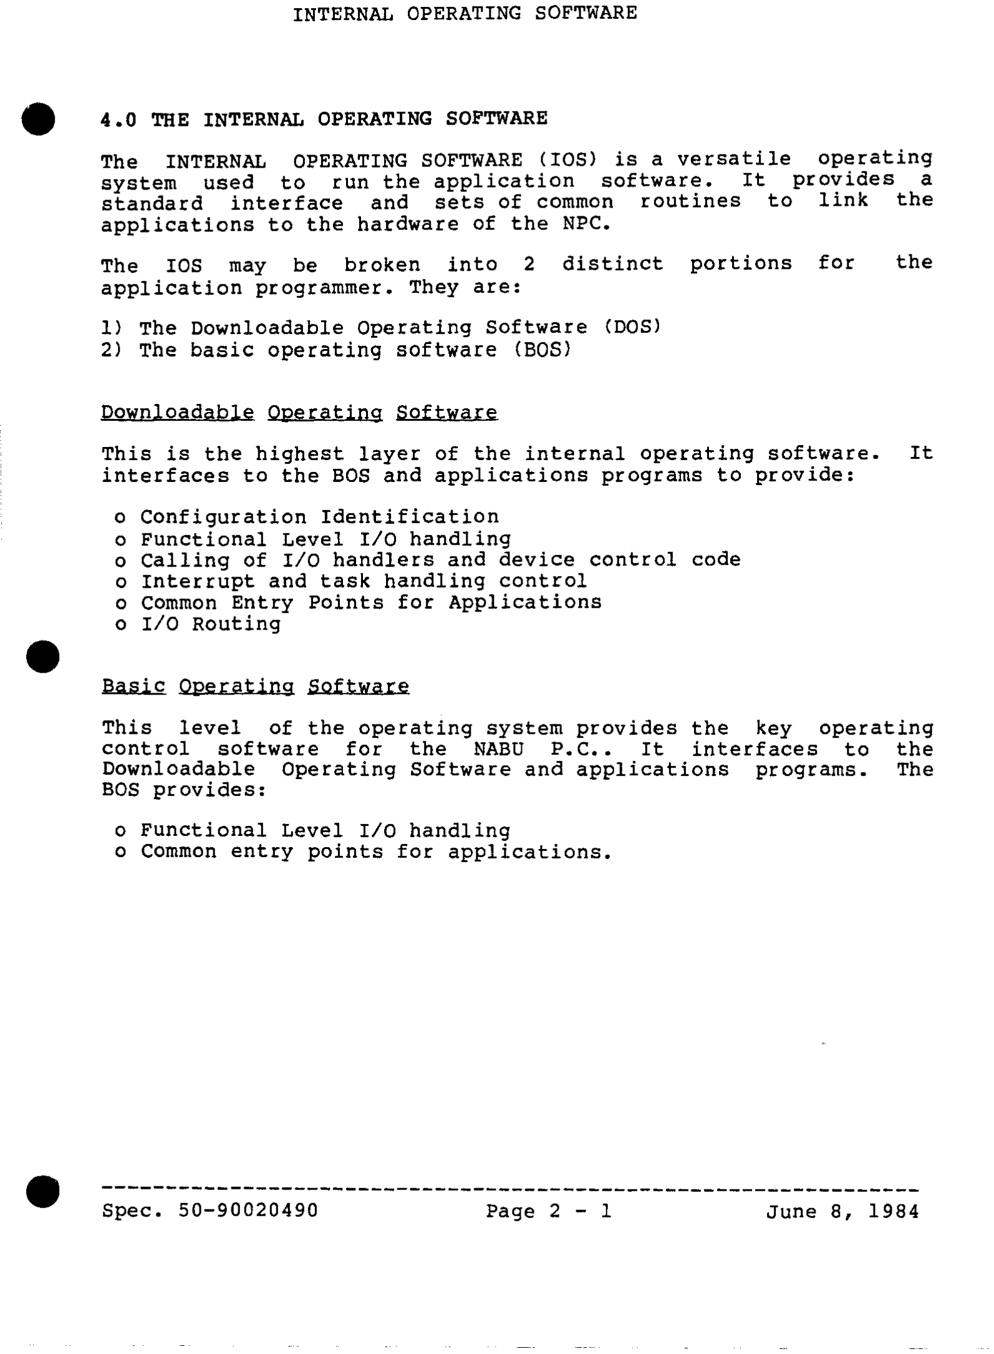
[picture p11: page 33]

INTERNAL OPERATING SOFTWARE

- 4.0 THE INTERNAL OPERATING SOFTWARE

•

•

The | INTERNAL OPERATING SOFTWARE (IOS) is a versatile operating
system used to run the application software. | It provides a
standard interface | and sets of common routines to link | the
applications to the hardware of the NPC.
The | IOS may be | broken into 2 distinct portions for | the
application programmer. They are:
1) The Downloadable Operating Software (DOS)
2) The basic operating software (BOS)

Downloadable Operating Software
This is the highest layer of the internal operating software. It interfaces to the BOS and applications programs to provide:

o Configuration Identification
o Functional Level I/0 handling
o Calling of I/O handlers and device control code
o Interrupt and task handling control
o common Entry Points for Applications
o I/O Routing

Basic Operating Software

This level | of the operating system provides the | key operating
control | software for | the NABU P.C •• | It | interfaces to | the
Downloadable Operating Software and applications programs. | The
BOS provides:
o Functional Level I/O handling
o Common entry points for applications •
---------------------------------------------------------------- Spec. 50-90020490 | Page 2 - 1 | June 8, 1984

CONVENTIONS

4.1 CONVENTIONS USED BY THE INTERNAL OPERATING SOFTWARE
The | IOS memory map structure is similar | to that of Digital
Research's CP/M operating system. | Thus, | any CP/M system may be
used as a development system for the NABU P.C. | Programs written
in a high level language compatable with CP/M will run under the
IOS. | However there are differences between CP/M and IOS. Not all
CP/M calls are implemented in the basic | IOS and the | stack
requirements are different.
The memory map below IOS is layed out as follows:

BASE to FFFFH

BASE-l
0100 hex:

DOFF hex:
OOOB hex:

OOOA hex:
0008 hex:
0007 hex:
0005 hex:

0004 hex:
0003 hex:
0002 hex:
0000 hex:
reserved for | IOS | I ---------------------------1
Applications Program | I
Area+ StackCsl | I ---------------------------1
Reserved Area for IOS | I
I ---------------------------1

I
Jump to DOS IOS calls | I ---------------------------1
Jump to BASE | I

# I (the jump to DOS CPM calls) I 1---------------------------1

I | reserved for IOS | I
I | I 1---------------------------1
I Jump to IOS warm start | I
(Note that there is a data area within IOS that is reserved for | I
the use of applications. | This area is unique in that the memory
contents remain intact across resets and warm starts. | This can
be | useful | for "chaining" programs. | This area is at locations
FF80 (HEX) through FFDF (HEX) inclusive.)
Applications programs | interface to the IOS through three entry
points only. | These are locations OOOOH, | 0005H and 0008H. | A
discussion of each | location now follows. | (Note also that
applications may also enter IOS routines through BOS calls. | See
section on BOS Calls elsewhere in this manual.)
Spec. 50-90020490 | Page 2 - 2 | June 8, 1984

•

•

•

CONVENTIONS

- ~ .t.Q LOCATION .Q.QQQ. ~

•

J
•

An application program that CALLs or JUMPs to location 0 will
cause a warm start of the IOS. | This CALL is | used when an
application program is finished running and wishes to return to
whatever | human interface program invoked it. | In order to be
compatable with CP/M, | this entry point jumps to the WARMBOOT
entry in a jump table which is identical to CP/M's BIOS Jump
Table. | It is | recommended that applications programmers avoid
attempting to use the BIOS Jump Table. The IOS is structured this way to be compatable with CP/M applications programs and to provide support expansion to the IOS.

~ .t.Q Location 0005 IWI_

Location 0005 Hex is the same as the standard CP/M entry point. Details on this entry point are found in the section on CP/M
Compatible Calls. | Note that locations 6 and 7 contain a pointer
to BASE, | the first location used by the IOS. This allows applic-
ations programs to determine how much memory is available. | BASE
may vary between different versions of the !OS •

.cALL_ .t.Q Location m lim~.

Location 0008 Hex | is the entry point into the DOS | IOS Calls.
These calls are detailed in the section on DOS Calls. | This entry
point has the same calling conventions as the entry point at
location 0005, | except it is used for non-CP/M compatable operat-
ing system calls. | Note that locations 9 and A do NOT point to
BASE.

When the MAIN MENU starts executing it will find the following initial conditions have been set:

o The Stack Pointer is set to BASE
(the first PUSH will write to BASE-l and BASE-2) o All other Z-80 registers are undefined

o All clock processing turned on
-Flashing Cursors Enabled
-Clock User Task Handling Enabled -Real Time Clock Incrementing Enabled o The Video Chip is set to text mode •
---------------------------------------------------------------- Spec. 50-90020490 | Page 2 - 3 | June 8, 1984

I

CONVENTIONS

o Logical to Physical I/O Routing Set up to emulate Standard CP/M assignments:
-Video Device Location 1 set to:
38 wide by 24 deep window with underline flashing cursor
-Console Output Routed to Video
Device Location 1 (see window above) -Console Input Routed to Human Interface Device Location 1 (Keyboard}
-List Routed to Printer
-Reader Routed to Human Interface Device Location 1 (Keyboard}
-Punch Routed to Video
Device Location 1 (see window above}

After the MAIN MENU program gains control, it has the ability to alter the initial conditions for the application program which is
to be loaded. | For a complete list of the initial conditions as
set up by the MAIN MENU program, | please consult the Master
Directory and Main Menu Specification 02-90020480.

### 4.1.1 Stack Operation and Requirements

The | !OS only supports a single stack which is used by both the
!OS and applications programs. | This is different from CP/M which
has two or more stacks, | one or more used by CP/M and one for the
application. | Note that the !OS initializes the stack pointer | to
BASE so the | stack will start at the highest available memory
location and build down. The number of bytes of stack required by
!OS depends on the number of peripheral devices attached. | For
the basic | IOS, | up to 64 bytes may be used | by the operating
software. | This means an application program must be | sure to
allow for a stack size 64 bytes larger than what the application requires. The addition of peripherals to the NPC may increase the minimum stack requirement.
Spec. 50-90020490 | Page 2 - 4 | June 8, 1984

•

•

•

•

CP/M COMPATIBLE CALLS

~he ~es e~~~ef~S a nHmeef ef ee~~e wh±eh &fe e±m±~ar ~e e~endard €PfM nen-die~ ~e ea~~e~ Ne die~ erien~ed ea~~e are e~~~er~ed~ ~he €PfM eem~a~ib~e ea~~e ~he~ ere ~revieee ere £er reee~~±n~ ~he

eye~em7 end fer ~er£erm±n~ %9 rrem ~he iegieel eeviees €9NS9nE7
RE~BBR7 PSN€H end n~s~~
~he ~es ees €PfM eem~a~ee~e ~fe feei~i~iee eeai eniy wi~h ~egieai
deviees7 ~e~g~ €8NS8nE7 nfS~7 RE~BER7 PSN€H~~ | ~he ~eS ~fe
Hend~ere epere~e wi~h s~eeifie ~hye~eai devieee~ | f~be f9S ne~~aeheen | ~he | ~e~ieai deviees ~e ~he | ~hys~ea~ | deviees~ | Per e~am~~e7 ~his a~~ews an ~S€ff eharaeeer ~e be sen~ ~e ~he iegiea~

deviee end i~ ends ~P a~ ~he ~hysiea! eeviee~f

~he £e~~ewing ~e~iea! deviees ere defined~

RE¥B9AAB~
S€REEN~
:o~s~~
RE~BBR~
PSN€H~

~inp~~ per~±en ef €9NS9f>E~ ~e~~~~~ ~er~ien ef €9NS9nB~ ~e~ep~~~
~in~~~ deviee~
~e~~p~~ deviee~

HeM~ ~N~ERP~€E - RB¥P~B-:

if9¥S~f€R ~-:
if9¥S~~€R i!-:-
S€RBEN WfNBeW f~-:
PRfN~ER~

H ~inp~H
9i! Hn~~H
93 Hn~~H
~i ~e~~p~e~
i!~ ~e~~~~H

e
i
~
3
4
~se±~nmen~s | ef physieai eeviees ~e ~egieai eev±ees are perfermee
ey Hein~ | ehe ~~9 ReHeer Enery Peine~ | When a ~regram | begins e~eeHeien ebe fei~ewing ~egiea~ ee ~hysiea~ eeeeebmen~s ere made~

n9EH€~
RB¥B9AAB
SERE EN flfS~

RE~BBR
P6N€H

PH¥Sf€~
RE¥B9AAB
S€RBEN WfNB9W fi
S€REEN WfNB9W fi
S€RBEN WfNB9W fi
S€REEN W~NB9W f~
Ne~e | ehe~ | S€REEN WfNB9W fi is defined by ~he | eye~em | end is evei~eeie | ~e ~be e~p%iea~ien when ie s~ar~s~
~he | €PfM eem~e~ie%e ee~%e ~revieee in ~he ~es ~hreHgh ~eea~ien 5
!ire ee £eiiewe~

# ---------------------------------------------------------------- Spee~ 59-9992!9499

CP/M COMPATIBLE CALLS

S¥S~SM=RSSS~ | ~e~ii ft~mee~ 88H~
-~e~£e~ms some £~fte~~eft es e j~m~ ~e ~eee~~eft 8888 Hex

-eft~~y ~~~eme~e~s~
€ Reg~s~e~~ SS Hex
-±s ftO~ ~e-eft~~eft~
€6NS6bB-~NP5~ . | ~e~i~ ft~mee~ SiH~
-~;ads ~he fte~~ ehe~eeee~ £~em ~he ~egie~~ eeftee~e wi~h eehe ~he e~ii does fte~ ~e~~~ft ~"~*~ e ehe~ee~e~ ~s ~eedy~
i~h~e | e~%% | w±%~ | eftry eeee~~ | €PfM eem~ee~ere | ~se~~
ehe~ee~e~s~ | ~£ ~he »¥ssn ~ey is hi~T e »¥» ±e ~e~~~fted~ ~£
~he »Ne» ~ey ie hi~ e »N» ie ~e~~~fted~ | ~rr ethe~ ~ey eedes
eeeve ~PH e~e igfte~ed~+
-eft~~y ~~~emete~e~
€ Regie~e~~ S~ He~
-Re~~~fted V~r~es~
~ Reg~ste~~ €hereeee~ ~"~~~
-ie fte~ ~e-efterefte
eeNSens=ee~Pe~ | ~e~r~ "~eer S2H~
-e~~~~~e e ehe~eeee~ ~e ~he ~eg±ee% eefteere
tS±ftee the de£a~r~ ~hye~e~r eefteere d~iver ~e aes e~ir e~2 eftd S~3 eefts~%~ ~he s~ee±£ie~~~eft £er BaS eeir ~3H £e~ eeft~rer eharaeee~ ifteer~~eea~~eH~+
-eft~~y ~~~emete~s~
€ Reg~ste~~ S2 He~
B Regisee~~ €ha~ee~e~ ee ee e~ep~e
RB~BSR=~NPB~ | ~e~rr ft~meer 83H~
-ge~ | e ey~e £~em ~he reg±e~r ~~PE
ftee ~e~~~" te ~he e~rriftg ~~eg~em

reede~ eeft~rer wi~r
~Heir ehe eharaeee~
hee eeeft ~eed~
t~hie | e~ir | w~r~ | eftiy ehe~ae~e~s~ | ~£ ehe »¥esn
ehe »Ne» ~ey ie hi~ e nN»
eeeve ~PH e~e ignored~+
-en~ry ~~~ame~e~e~
€ Reg±e~e~~ S3 He~
-~e~~~fted v~r~e~
| | | aeee~~ | €PfM ~ey is hie, e

±e ~e~~~ned~

~ Reg±e~e~~ eha~ae~e~ reed -ie ftee re-en~~afte

P8N€H=68~P8~ | ~e~rr ft~mbe~ S4H+ -e~~~~e e ey~e ee ehe regie~% ~~PE ~~neh
eem~a~iere | ~S€%~
»¥n ±s ~e~~rned~ ~£
~ir e~he~ ~ey eedes

tS±ftee ehe de£e~re ~hys±e~r eenseie drive~ is aes e~ir e~2 eftd S~3 eefts~re ehe s~ee±£±e~e±eft £er aes e~r~ ~3H £e~ een~~er eharaeee~ ±nee~~~e~aeieH•+
-en~ry ~~~eme~e~e~
€ Reg±s~er~ S4 He~
B Reg±e~e~~ ehe~ae~e~ ee ee e~e~~~
S~ee~ 5S-98S2S49S | P~ge 2 - 6

•

•

•

•

•

•

CP/M COMPATIBLE CALLS

MS'l'=91:f'l'Pl:J'i' | -feaH nt1111Bet' 95Ht
-eu~~t:l~ a ehat'ae~et' ~e ~he ie~iea% iie~ de~±ee
-en~t'Y ~arame~ers~
€ Re~ie~er~ 95 He~
£ Re~ie~er~ eharae~er ~e be eu~~t:l~

BfRE€'l'-€9NS9nB-f9 .fea:l:i nt1111ber 95Ht
-~re~±des- unadorned fr9 £t'e111f~e ~he :l:eg±ea% eense:l:e
l:J~en en~t'Y7 ~he B re~±s~er e±~her een~a±ns an 9PP He~7 dene~±ng a eenseie ±n~t:l~ requee~7 or a eharae~er ee be
eu~~u~~ f£ | ~he | ±n~ue | vart:le ±£ 9PP He~; | ~hen | ~he
£t:lnee±ens re~urne w±~h ~he A reg±s~er ee~ ee 99 ±£ ne
eharae~er ±e ready a~ ~he ie~±eai | e~herw±ee | ~he | A
re~±e~er ±e se~ ~e ~he eharae~er vart:le ±n~t:l~ £re111 | ~he
:l:e~±ea% eense:l:e~
i'l'h±e | ea%:1: | w±:l:i en:l:y eeee~~ | €PrM eel!l~a~±b:l:e | AS€ff eheree~ere~ | f£ ~he ~¥BS~ ~ey ±e h±~7 a ~¥⁴ ±s re~t:lrned~ f£
ehe ~Ne~ ~ey ±e h±~ a ~N~ ±e re~urned~ | A:l:i e~her ~ey eedee
abe~e ~PH ere ±~nered~t
iS±nee ehe de£at:1%e ~hye±ear eense:l:e driver ±e ees ear%
9A% and 9A3 eensHre ~he e~ee±£±ea~±en £er ees eeri A3H
£er een~rer ehareeeer ±n~erpre~e~±en~t
-en~ry ~arallle~ere~
€ Regie~er~ 95 He~
£ Reg±s~er~ PP He~ f±n~u~t er
eharaeeer ~e be et:l~~u~
-re~Hrned va:l:t:le~
A Re~ie~er~ eharee~er e£ 99 He~ f±n~t:l~t ne~h±ng ±£ et:l~~t:l~
-±e ne~ re-en~ren~
PRfN'l'=S'l'RfN6 | fear% nt:lmber 99Ht
-~r±n~ a e~r±ng ~e ~he reg±ea% eensere 'l'he eharae~er s~r±n~ eeered ±n memery ~ein~ed ~e by ~he BB reg±e~er ±e sen~ eense%e~ A ~.~ ±e Heed ee a de%±111±~er
e~r±ng~

## frem a

ee ehe
ee ehe
ee end

### bt1tfer

:l:eea~ien
re~±ea%
ehe ~rin~
iSinee ~he de£et:1re physiea% eense:l:e driver ±s ees ea%:1: 9A% and 9A3 eenst:lre ehe s~ee±£±eae±en £er ess ear% A3H £er een~re% eheraeeer ±n~er~reee~ien~t
-en~ry ~era111e~ers~
€ Regie~er~ 99 He~
BB Reg±eeer~ ~ein~er ~e serin~
S~ee~ 59-99929499

CP/M COMPATIBLE CALLS

R£~B-€9NS9bB-B6PPBR ~ee%% n~mbef SAM~
--feed a-fine ef ed±~±ed xeg±eei eonsoxe ±n~~~ ~e d b~ffer
~he inp~~ is s~ofed in ~he memefy bttffef pein~ef ~e by ~he BE fe~is~ef~ ~f ~he b~ffef eveffrews eense%e ±np~~

ie ~efmine~ed~ ~he £ofma~ e£ ~he bttffef is~

MME=BBP=S'H!£~ | B¥'1'£-:- N6MB£R=9P=€H~RA€~BRS=RB~B~ ·B¥~E-t
€H~R~€~ER=EBPPER~ | ~RR~¥f%~~MA*=BBP=S~SEf B¥~E7

~he 4694 ~ey ~SB Hex~ ef €N~Rn ~ ~a~ Hex~ w±ii ~efmina~e
~he inp~~ r±ne~ | ~he BEnE~£ ~ey w±xi fieie~e ~he | ~Pe¥±es%1
~yped ehafae~ef~
f~h±s | ear% | w±ii en%y ehafae~efe• | ~£ ~he 4¥BS4
~he 4N94 ~ey ±e hi~ e 4N4
above ~PH afe i~nefed~f
-en~ry pafame~efs~
€ Re~is~ef~ 9~ Hex

eeee~~ €PfM

### ~ey ±!! h±h e

ie fe~ttrnech

eempa~ibie ~S€tt
4¥4 ±s peeHPftee• ~~
~xi o~nef ~ey eedes

BE Re~is~ef~ Pein~er ~e M~*=EBP=S~SE ~MA*=BBP=S~SE mtts~ be se~ as we%%~ -re~~rned ve%~es~
€onsofe €hafaeeefe ±n Btt££ef N6MBER=9P=€HAR~€~£RS=R£~B ee~

-±s no~ fe-en~fan~

6£~=€9NS9nE=S~~~BS ~eeri nttmbef 9BH~
-ehee~ ~o !!lee i£ eheree~ef has been ~ypee a~ ie~iear eeneere -en~fY pefeme~ers~

€ Re~ie~ef~ 9B Hex -re~ttrned va%tte~

~ Re~is~ef~ 99 Hex -Ne ehafee~er feady
PP Hex -€hafae~ef is feedy and wei~in~ -±e no~ fe-en~ran~
~fe=Ree~ER~ ~~~~eH | ~eeri nttmber 8AH~
-e~~aehee e per~ie~%ar phys±ee% deviee ~o a io~±ee% dev±ee -en~ry pereme~ers~

e Regie~er~ 811 Hex
£ Regie~er~ PH¥Sf€t'tb=BEV~€E
B Re~is~er• b96f€i'lb-BEV%€E
Whe:e b96f€t'lb=BEVf€E is ~he by~e veitte o£ a io~iee% dev~ee | ee | ±den~i£ied *" ~he eee~ien | above | and PH~Sf€Ab=BEV~€E is ~he by~e ve%~e o£ e phys±ee% ceviee~ :h~~ ee%% wir% eettse a%% ettbseqtten~ ff9 ~o ~he rogiee%

~:::ee ~;e.be pe:termee.by ~he phys±eei ceviee a~~eehee~ eexr ~8 eve~iebie ~n ~he Bes~

Spe~~-~~=;~~2~~;~----------------------------------------------- Page 2 - a | June 8, 1984

•

•

•

## ros for

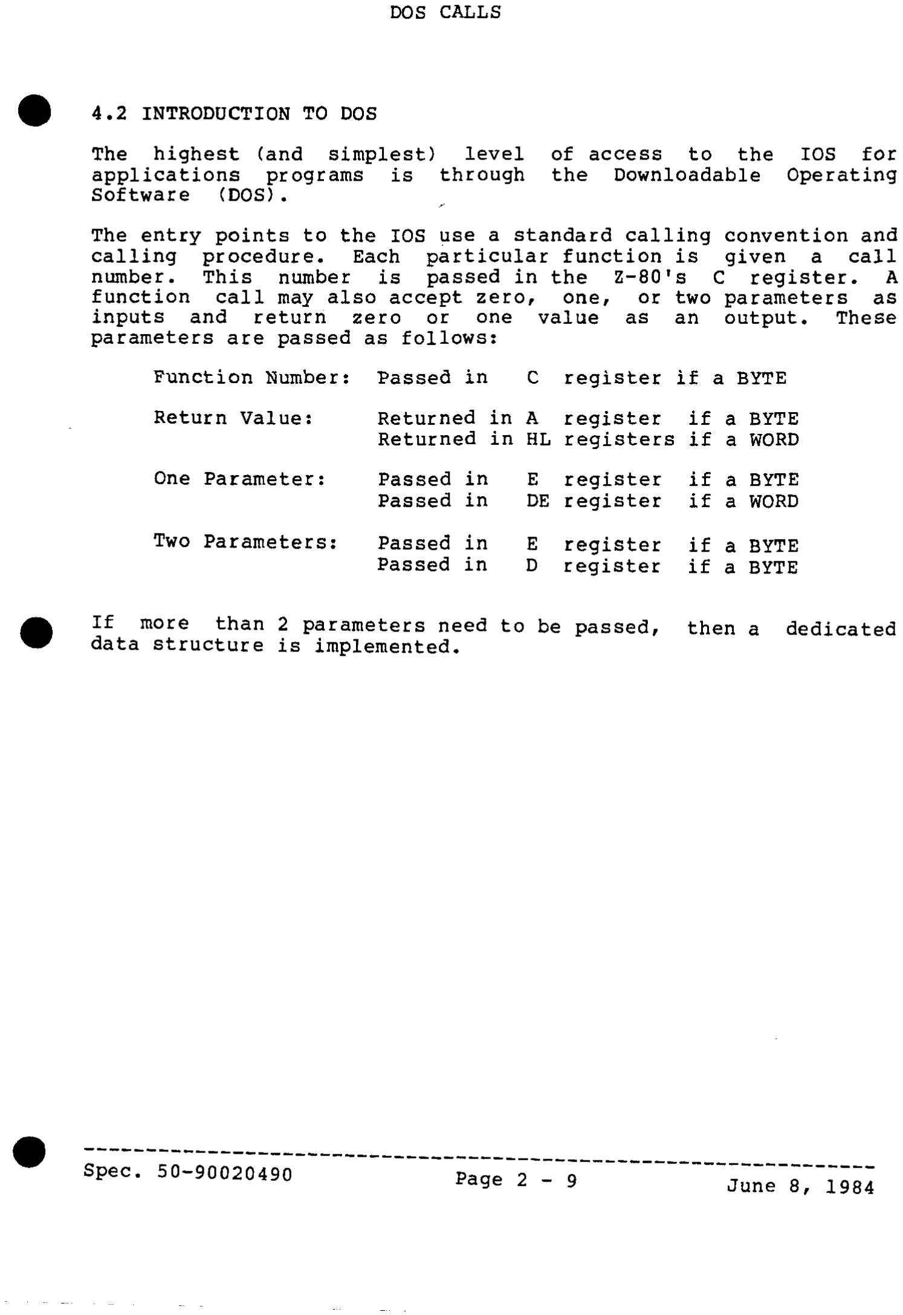
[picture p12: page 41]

DOS CALLS

~ 4.2 INTRODUCTION TO DOS

~

~

The highest (and simplest) | level
applications programs | is through
Software | (DOS).

of access to the
the Downloadable

Operating

The entry points to the IOS use a standard calling convention and
calling procedure. | Each particular function is given a | call
number. | This number | is passed in the | Z-80's | C register. | A
function call may also accept zero, | one, | or two parameters as
inputs and return zero or | one value as an output. | These
parameters are passed as follows:
Function Number: | Passed in | c register if a BYTE
Return Value: | Returned in A | register if a BYTE
Returned in HL registers if a WORD
One Parameter: | Passed in | E register | if a BYTE
Passed in | DE register if a WORD
Two Parameters: | Passed in | E register | if a BYTE
Passed in | D register | if a BYTE
If | more than 2 parameters need to be passed, | then a | dedicated
data structure is implemented.

4.2.1

4.2.1.1

DOS CALLS - SEGMENT HANDLING

SEGMENT HANDLING ROUTINES

INTRODUCTION

The | IOS provides the mechanism for interfacing with the data and
programs that are found on the broadcast cycle. | All data or code
(program> which can be loaded at one time forms what is called a
segment. | Segment loads can be of varying size ~rom a few bytes
up to the NPC's available free RAM space. | (By usLng segment load
offsets, | the | application can manipulate data segments of much
larger size.>
The | interface | that IOS provides is composed of two components.
The | first | is | that we provide DOS entry points which perform
different segment handling functions. | The second is that the IOS
contains a | data | structure called the segment | control/status
block. | This block of data is the place where data is passed to
the | segment handler and where data is received from the segment
handler.
The | following section will describe the theory or | specification
that | the segment handler obeys. | Following that are examples of
how a programmer could use the segment handling functions.
4.2.1.2 | SEGMENT CONTROL AND STATUS BLOCK
The | IOS contains a data structure called segment | control/status
block. | This | block is used to pass information to and from | the
segment handler. | This block resides inside the IOS and not in
the application work space.

The programmer gains access to address of this block using DOS call 87H. By using a template of the control block as described below, the block can be modified as needed.

---------------------------------------------------------------- Spec. 50-90020490 | Page 2 - 10 | June 8, 1984

•

•

•

•

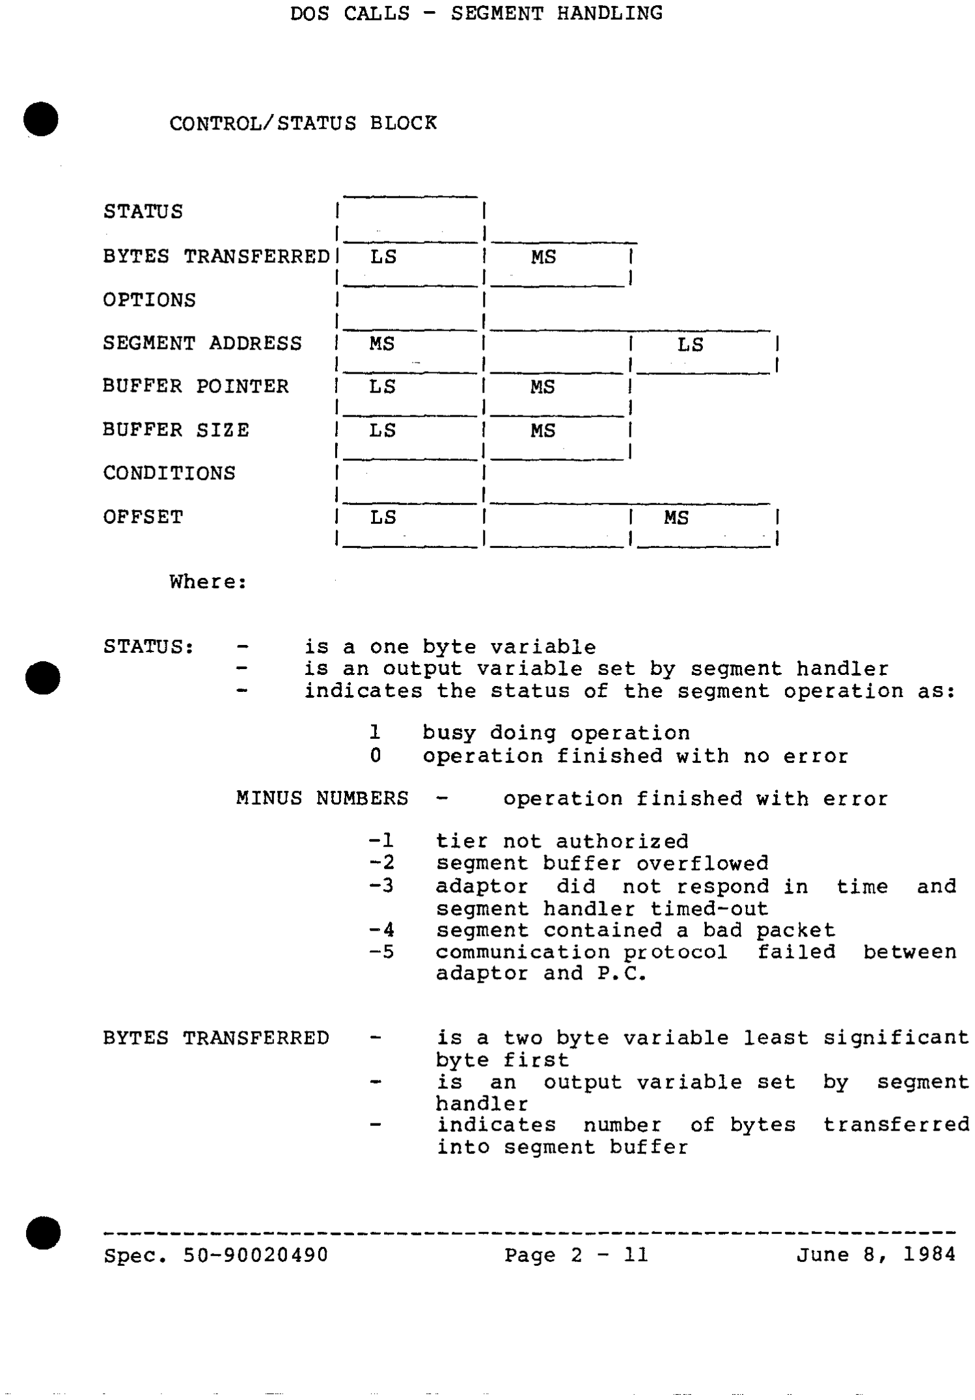
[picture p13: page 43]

•

•

DOS CALLS - SEGMENT HANDLING

CONTROL/STATUS BLOCK

STATUS | I '---------- BYTES TRANSFERRED! | LS | MS

I
OPTIONS | ~------
1 SEGMENT ADDRESS | 1-~M~S----- ---------~--L-S ____ __
I ________ --------- ------ BUFFER POINTER | I LS | MS
I ______ ------
BUFFER SIZE | I LS | MS
I _________ ------
CONDITIONS | I
I ________ -------~~~---- OFFSET | I | LS | MS | I

Where:

STATUS:

| I | | | · I

is a one byte variable
is an output variable set by segment handler indicates the status of the segment operation as:
1 | busy doing operation
0 | operation finished with no error
MINUS NUMBERS | operation finished with error

BYTES TRANSFERRED

Spec. 50-90020490

-1 | tier not authorized
-2 | segment buffer overflowed
-3 | adaptor | did not respond in | time | and
segment handler timed-out
-4 | segment contained a bad packet
-5 | communication protocol | failed | between
adaptor and P.C.

is a two byte variable least significant byte first
is an output variable set by segment
| handler
indicates number | of bytes transferred
into segment buffer
Page 2 - 11 | June 8, 1984

•

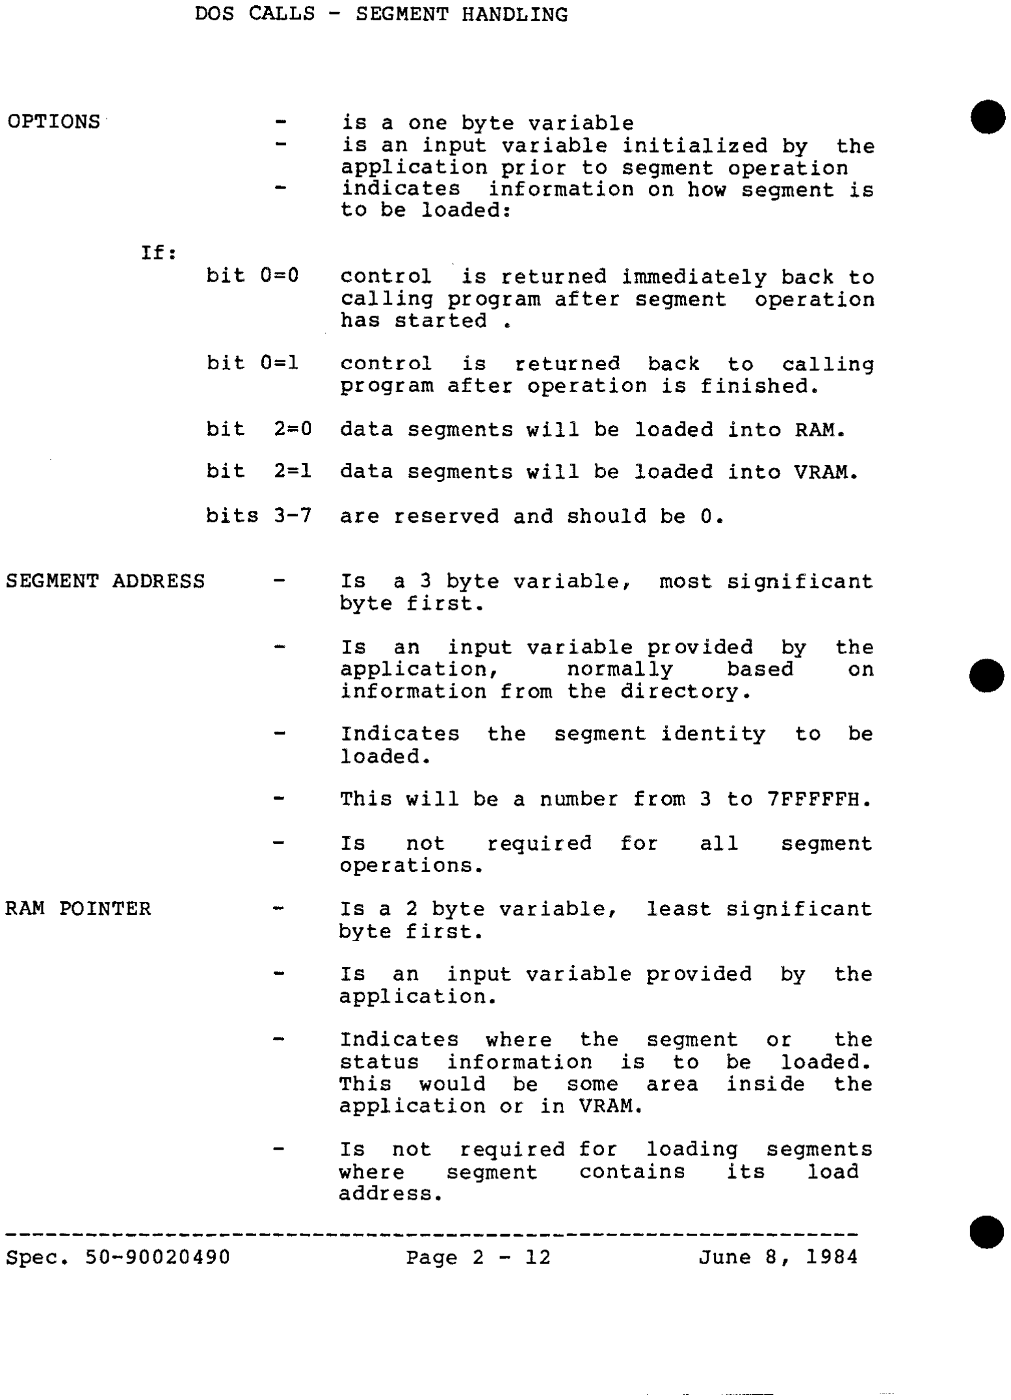
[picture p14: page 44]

DOS CALLS - SEGMENT HANDLING

OPTIONS

If:

SEGMENT ADDRESS

RAM POINTER

bit 0=0

bit 0=1

bit | 2=0
bit | 2=1

bits 3-7

Spec. 50-90020490

is a one byte variable
is an input variable initialized by the application prior to segment operation indicates information on how segment is to be loaded:

control is returned immediately back to calling program after segment operation has started •
control | is | returned back to calling
program after operation is finished.

data segments will be loaded into RAM. data segments will be loaded into VRAM.

are reserved and should be 0.

Is a 3 byte variable, most significant
byte first.

Is an input variable provided by the
application, | normally | based | on | •
information from the directory.
Indicates the segment identity to be loaded.
This will be a number from 3 to 7FFFFFH.
Is | not | required | for
operations.
all | segment
Is a 2 byte variable, | least significant
byte first.
Is an input variable provided by the application.
Indicates where the segment or | the
status | information is to be | loaded.
This would be | some area inside | the
application or in VRAM.
Is not | required for | loading segments
where | segment | contains | its | load
address.
Page 2 - 12 | June 8, 1984 | •

•

•

•

RAM SIZE

CONDITIONS

DOS CALLS - SEGMENT HANDLING

Is a 2 byte variable, least significant byte first.
Is an input variable provided by the application.
Indicates size of buffer in | bytes: | as
pointed to by buffer pointer.
Only required if buffer pointer is required.
Returned. | Can be ignored.
OFFSET | This value (3 bytes) represents the num-
ber of bytes, from the besinnins of the data segment, to ignore when loading the segment <an offset to the first loadable byte). Ensure that this is zeroed if you do not wish an offset.)
4.2.1.3 | DOS INTERFACE
The | segment handler performs operations
control block being correctly initialized, to a DOS entry point.

based on the segment
and a call being made
*** NOTE *** In order for the segment loader IOS | to properly
interface with the Adaptor, | the application
program must NOT be within an interrupt protected area of code when making segment handler requests. Interrupts must be enabled and this implies that the call to the segment handler does not occur inside of a CRBEG - CREND code block.
C See "Interrupt Structure and Tasking Support"
for | more | information on CRBEG, | CREND and
"Critical Regions". J
Spec. 50-90020490 | Page 2 - 13 | June 8, 1984

DOS CALLS - SEGMENT HANDLING

The DOS call is made by initializing
location s. | The following | calls
applications.

register C and "calling"
will be the ones used

IF
| REG c = SOH | Segment handler is reset
| REG c = 84H | Segment is loaded and
| | interpreted if necessary
| REG c = S7H | Base address of control

### block is read

All parameters passed and returned are made through SEGCST.

SEGMENT HANDLER IS RESET | Call Number SOH

to
by

When this operation is invoked, any pending segment operation is ignored and the adaptor is reset to a known state. The segment control/status block does not have to be initialized because it is not used by this operation.
SEGMENT IS LOADED AND INTERPRETED IF NECESSARY. | Call Number S4H
This operation attempts to load in a segment as | indicated | by

•

segment address in the control block. | If the segment is loaded, | •
the | segment header may be interpreted to help with the | load
address and the location where execution of code is to begin or
continue. | If the load is unsuccessful, | error information is
returned in the status byte.
LOADING A DIRECTORY-ONLY SEGMENT

The control block requires that:
Options = 01 or 00
Segment address contains the number of a directory segment Ram pointer and Ram size are not used
The | segment will be loaded into the directory area inside | IOS.
The previous | directory will be overwritten and the IOS will | be
notified that a new directory is present. | The code-to-load field
in the segment header will have been 000000 indicating that | this
directory has no code associated with it. | After the directory
has been loaded in, control is returned to the calling program.
Spec. 50-90020490 | Page 2 - 14 | June S, 19S4 | •

DOS CALLS - SEGMENT HANDLING

... LOADING A CODE SEGMENT:
I

•

•

The control block requires that:
Options = 01 {or 00}
Segment address contains the number code sesment
Buffer pointer and buffer size are not used
The | segment is loaded. | The segment header contains the load
address where | the code is to be loaded. | It also contains the
start address where execution begins in the code after | it has
successfully loaded. | Just prior to execution beginning | in the
newly loaded code, | initialization occurs. | The stack pointer is
set to just below IOS, | all attached tasks are removed, | and the
keyboard and clock interrupts are enabled.

LOADING A DIRECTORY WITH CODE-TQ-LOAD
The control block requires that
Options = 01
Segment address contains the number of the directory segment Ram pointer and Ram size are not used
The directory portion of the segment is loaded into the | IOS
directory area. | Then the code-to-load field in the | segment
header is checked. | If the value is FFFFFFH, then a code segment
complete with header will immediately follow the directory | in
this same segment. | If the value is not 0 and not FFFFFFH, | then
the code segment specified by the value is loaded in.

LOADING IN A DATA SEGMENT

The control block requires that:
Options = 01 or 00
Segment address contains the number of the data segment Ram pointer contains the pointer to the area where the data is to be written
Ram size contains the size of the area where data is to be written
Offset is set to the number of bytes to ignore in the segment before loading (usually OJ.

The data is loaded into the buffer as specified. After the data has been loaded control is passed to the calling program .

Spec. 50-90020490 | Page 2 - 15 | June 8, 1984

I

DOS CALLS - SEGMENT HANDLING

LOADING IN A OVERLAY SEGMENT:

The control block requires that:
Options = 1 or 00
Segment address contains the number of the overlay segment Ram pointer and Ram size are not used

The overlay is loaded in at the load address specified by the
segment header. | After the segment has been loaded, | control is
returned to the calling program.

BASE ADDRESS OF SEGMENT CONTROL/STATUS BLOCK IS READ.
Call Number 87H
The application is returned to the base address of the control block in the HL register pair. This will allow the programmer to place a template of the control block at that address in order to initialize the block as required.
4.2.1.4 | SEGMENT HEADERS
Each | segment requires some overhead to describe what the segment

•

contains. The extra data is called a segment header. | •
Segment headers have differing lengths. | The minimum size of a
header is 2 bytes long and the maximum size is 255 bytes.

The first byte of each header always contains the length of the header (2-255) in number of bytes.

The second byte of each header always contains the segment type. Four types of segments are currently defined:
Type 0
Type 1
Type 2
Type 3

= Directory segment with or without = Code segment
= Data segment
= overlay segment

code-to-load

---------------------------------------------------------------- Spec. 50-90020490 | Page 2 - 16 | June 8, 1984 | •

•

•

•

DOS CALLS - SEGMENT HANDLING

DIRECTORY SEGMENT HEADER

LENGTH | I

I
TYPE | 00 | I

I
ENTRY WIDTH | I

I
NUMBER OF ENTRIES | I

I
CODE-TO-LOAD | MS | I | LS

I
NAAE LENGTH | I
. I
NAME | I

I

Entry width | is the width of the directory entries. | Each
directory entry has the same width. | The width has a minimum size
of 10 and maximum size of 255. | (See section on directory calls.)
Number of Entries is the number of directory entries. | This value
could have a minimum of one and maximum of 255. | However | since
the maximum directory is 1000 bytes, | the product of entry width
and number of entries must not exceed 1000.
Code-to-load is the field which indicates if code | is to be
loaded, | and where this code can be found. | If this value | is
FFFFFFH, | then code follows the directory. | All other values
indicate the segment number of the code segment.
Name length | is the number of characters in the name of this
directory segment. | The minimum is 1 byte and maximum is
255 bytes.

Name is the actual ASCII name of this directory segment •

---------------------------------------------------------------- Spec. 50-90020490 | Page 2 - 17 | June 8, 1984

•

DOS CALLS - SEGMENT HANDLING

CODE SEGMENT HEADER

LENGTH | 8
TYPE | 1
LOAD ADDRESS | MS | LS
START ADDRESS | MS | LS
Load Address is a 3 byte variable, | most significant byte first,
which tells the segment handler where to place | the code.
currently the first byte is always 0.

Start Address is a 3 byte variable, most significant byte first, which indicates where execution begins. Currently the first byte is always 0.

DATA SEGMENT HEADER

LENGTH | 2
TYPE | 2
This header is the shortest one. | Its purpose is to notify the
segment loader that it is a data segment.

OVERLAY SEGMENT HEADER

LENGTH | 5
TYPE | 3
LOAD ADDRESS | MS | LS

Load Address is the address at which this overlay is to be
loaded. | It is a 3 byte variable, | most significant byte first.
Currently the first byte is always 0.
Spec. 50-90020490 | Page 2 - 18 | June 8, 1984

•

•

•

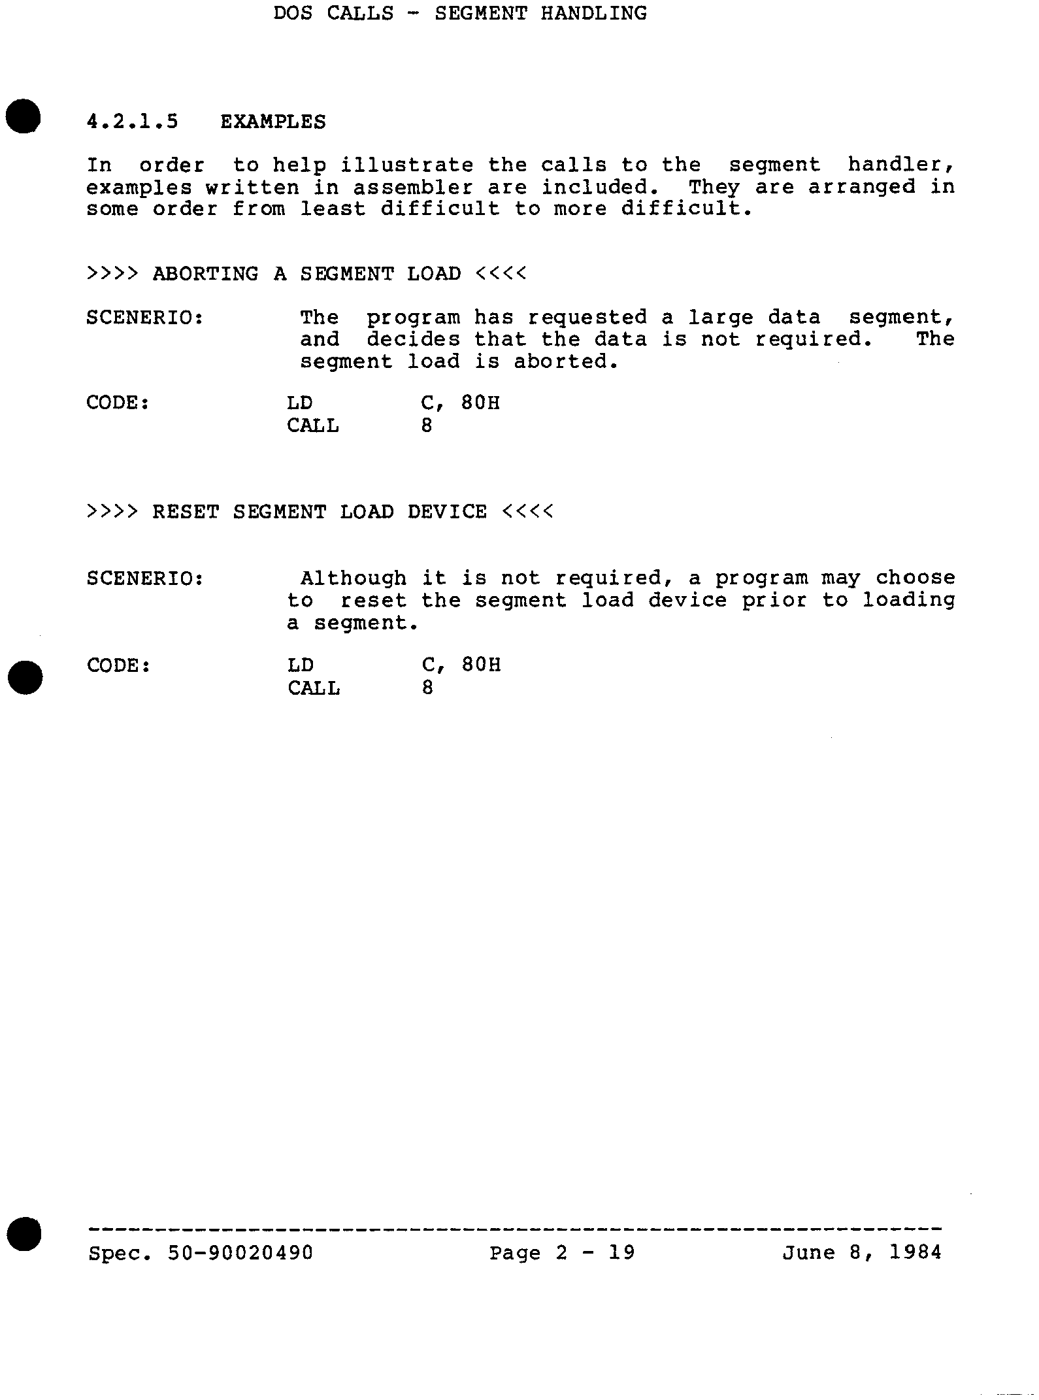
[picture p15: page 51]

•

•

DOS CALLS - SEGMENT HANDLING

4.2.1.5 | EXAMPLES
In order | to help illustrate the calls to the | segment handler,
examples written in assembler are included. | They are arranged in
some order from least difficult to more difficult.

>>>> ABORTING A SEGMENT LOAD <<<<

SCENERIO:

CODE:

The program has requested a large data | segment,
and decides that the data is not required. | The
| segment load is aborted. LD CALL C, SOH

s

>>>> RESET SEGMENT LOAD DEVICE <<<<

SCENERIO:

CODE:

Although it is not required, a program may choose to reset the segment load device prior to loading a segment.
LD CALL | C, SOH
s
Spec. 50-90020490 | Page 2 - 19 | June S, 19S4

•

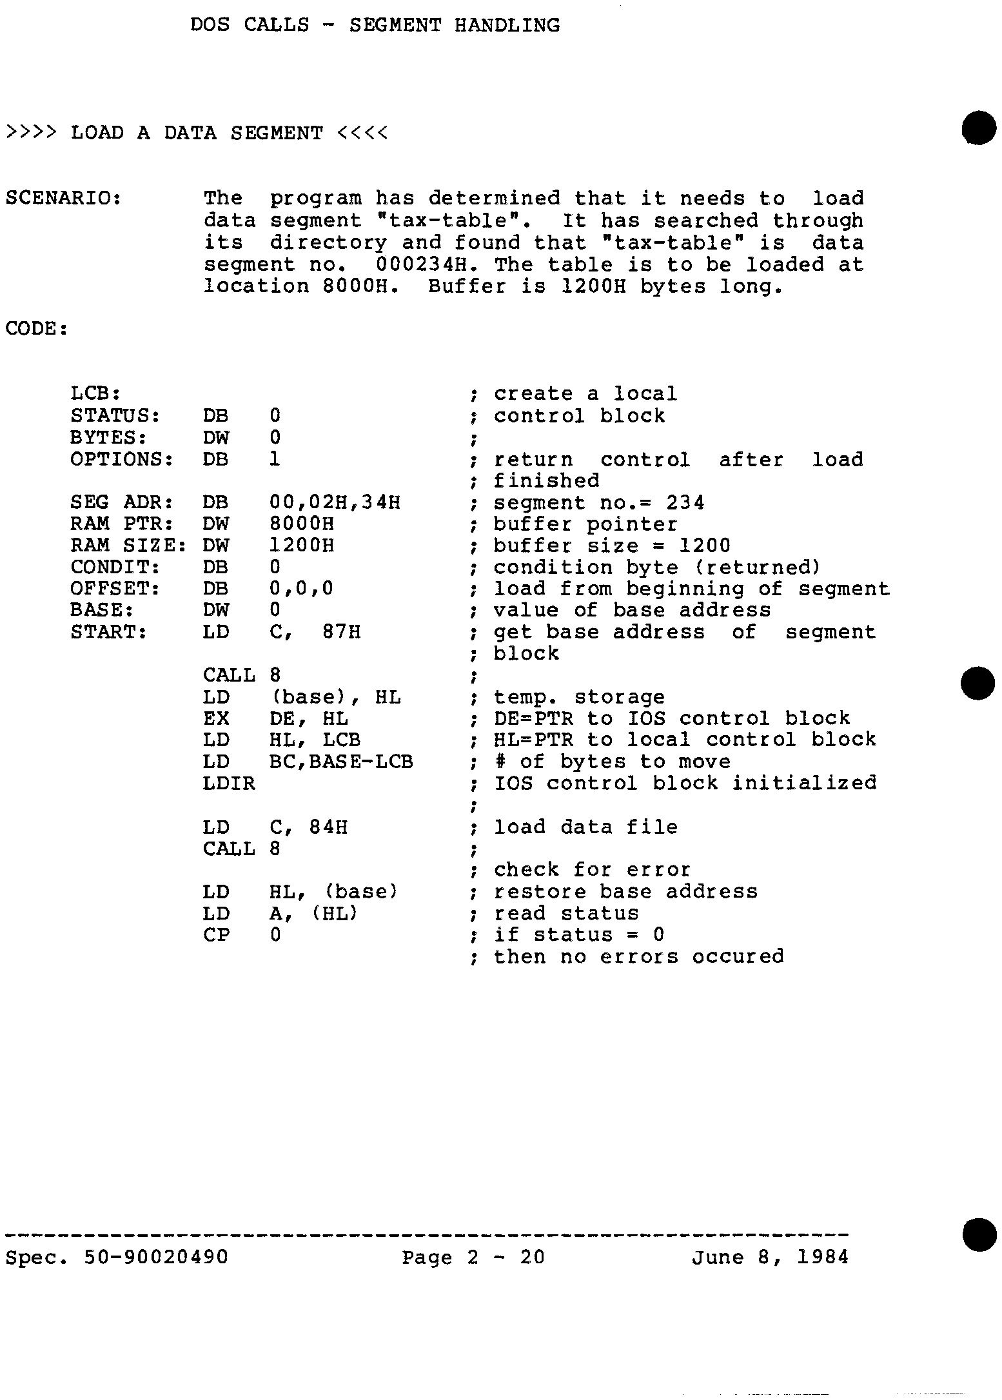
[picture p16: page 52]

DOS CALLS - SEGMENT HANDLING

>>>> LOAD A DATA SEGMENT <<<<

SCENARIO:

CODE:

LCB:
STATUS:
BYTES:
OPTIONS:
SEG ADR:
RAM PTR:
RAM SIZE:
CONDIT:
OFFSET:
BASE:
START:
The program has determined that it needs to | load
data segment "tax-table". | It has searched through
its directory and found that "tax-table" is data
segment no. | 000234H. The table is to be loaded at
location 8000H. | Buffer is 1200H bytes long.
DB | 0
ow 0
DB | 1
DB | 00,02H,34H
ow 8000H
ow 1200H
DB | 0
DB | 0,0,0
ow 0
LD | C, | 87H

CALL 8
LD | (basel, HL
EX | DE, HL
LD | HL, LCB
LD | BC,BASE-LCB
LDIR
LD c, 84H
CALL 8
LD | HL, (basel
LD | A, (HL)
CP | 0

create a local
control block
; return control | after | load
; finished
segment no.= 234
; buffer pointer
buffer size = 1200
; condition byte (returned) load from beginning of segment value of base address
; get base address of segment block

temp. storage
DE=PTR to IOS control block HL=PTR to local control block ; t of bytes to move
,

. IOS control block initialized

load data file
check for error
restore base address
read status
if status = 0
then no errors occured
Spec. 50-90020490 | Page 2 - 20 | June 8, 1984

•

•

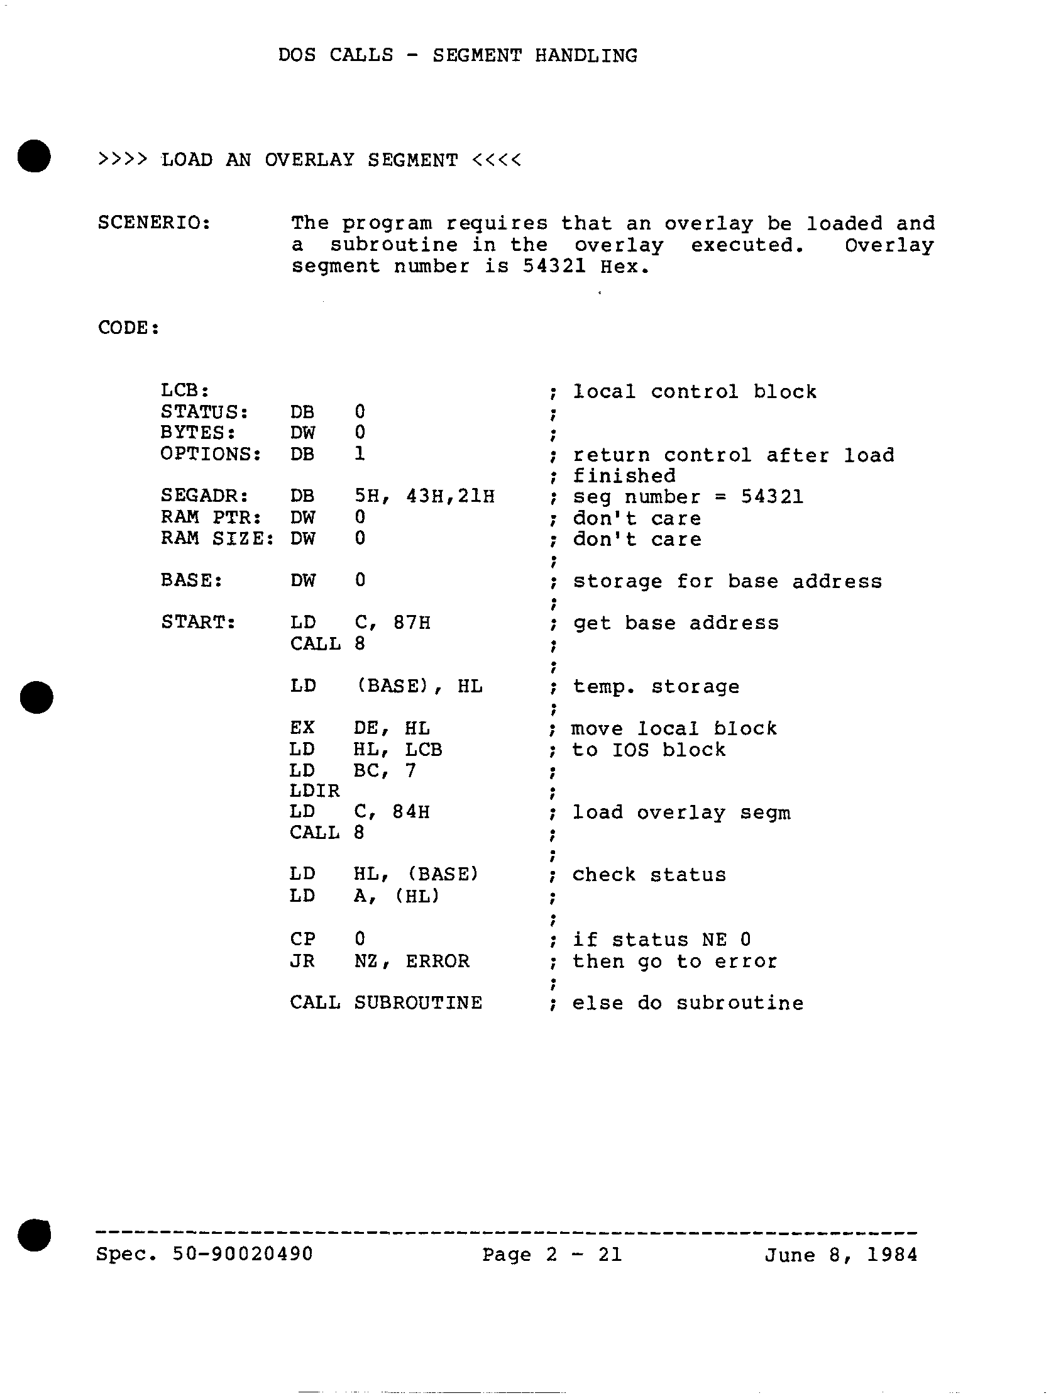
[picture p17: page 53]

DOS CALLS - SEGMENT HANDLING

- »» LOAD AN OVERLAY SEGMENT <«<

•

•

SCENERIO:

CODE:

LCB:
STATUS:
BYTES:
OPTIONS:
SEGADR:
RAM PTR:
RAM SIZE:
BASE:

START:

The program requires that an overlay be loaded and
a | subroutine in the | overlay executed. | Overlay
segment number is 54321 Hex.

local control block
DB | 0
DW | 0
DB | 1 | return control after load
| | finished
DB | 5H, 43H,21H | seg number = 54321
DW | 0 | ; don't care
DW | 0 | ; don't care
DW | 0 | storage for base address
LD | C, 87H | . get base address ' CALL 8
LD | (BASEl, HL | ; temp • storage
EX | DE, HL | ; move local block
LD | HL, LCB | to IOS block
LD | BC, 7
LDIR
LD | c, 84H | ; load overlay segm
CALL 8
LD | HL, (BASEl | check status
LD | A, (HL)
CP | 0 | if status NE 0
JR | NZ, ERROR | then go to error
CALL SUBROUTINE | else do subroutine
Spec. 50-90020490 | Page 2 - 21 | June 8, 1984

•

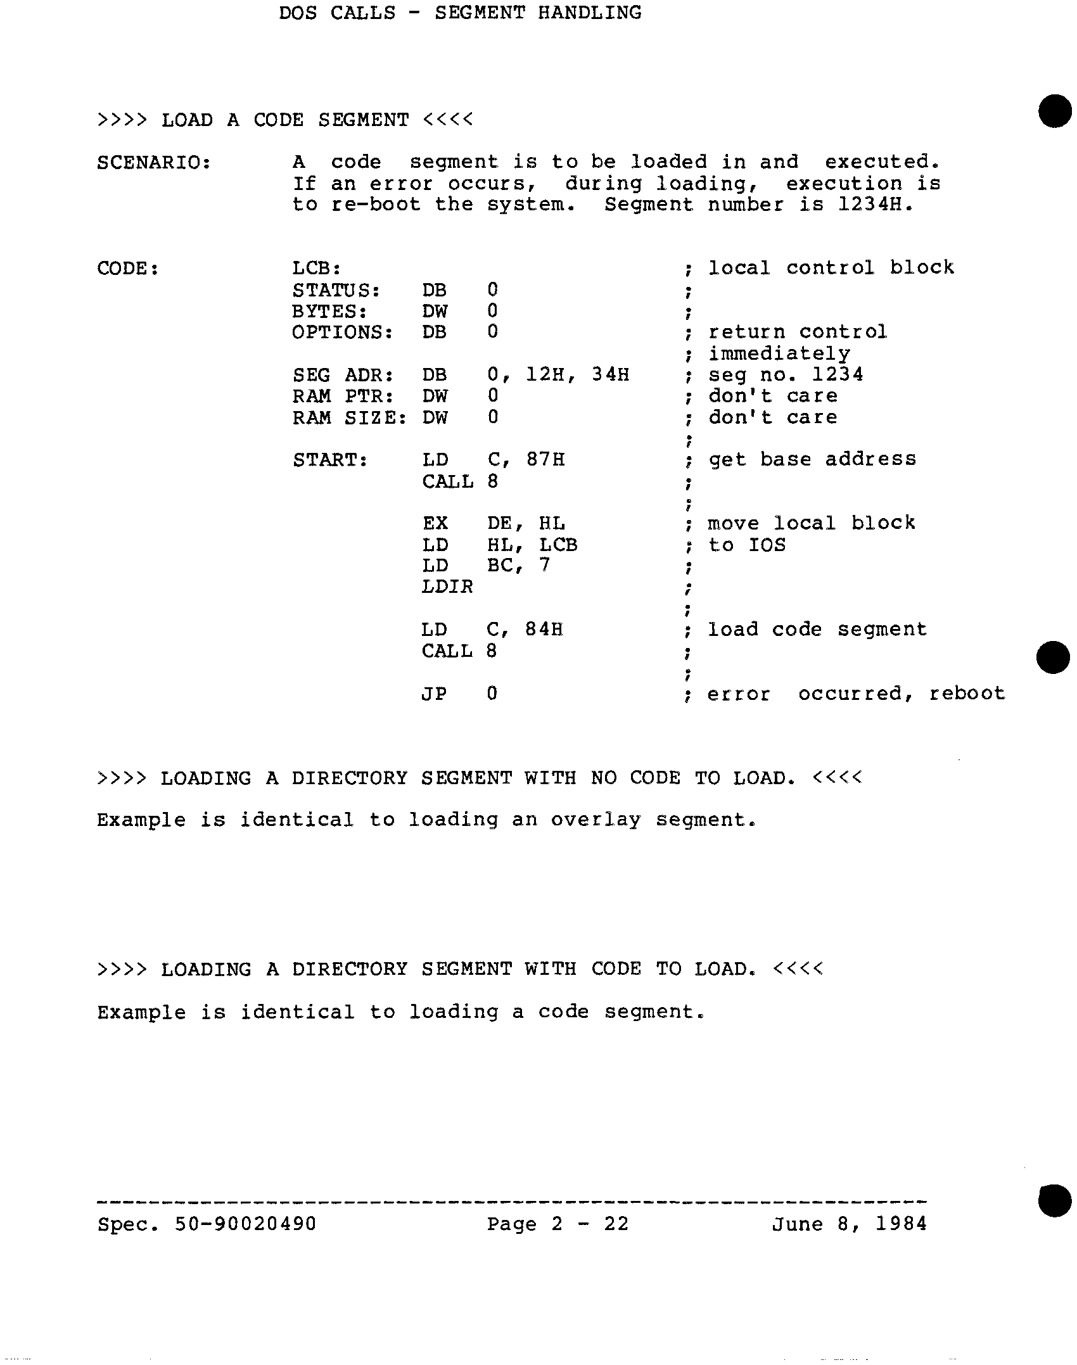
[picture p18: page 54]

DOS CALLS - SEGMENT HANDLING

>>>> LOAD A CODE SEGMENT <<<<

SCENARIO: | A code | segment is to be loaded in and executed.
If an error occurs, | during loading, | execution is
to re-boot the system. | Segment number is 1234H.
CODE: | LCB: | local control block
STATUS: | DB | 0
BYTES: | DW | 0
OPTIONS: | DB | 0 | return control
immediately
SEG ADR: | DB | 0, 12H, 34H | seg no. 1234
RAM PTR: | DW | 0 | don't care
RAM SIZE: DW | 0 | don't care
START: | LD | c, 87H | ; get base address
CALL 8
EX | DE, HL | move local block
LD | HL, LCB | to IOS
LD | BC, 7
LDIR | ;
LD | C, 84H | load code segment
CALL 8
JP | 0 | ; error | occurred, reboot

>>>> LOADING A DIRECTORY SEGMENT WITH NO CODE TO LOAD. <<<<

Example is identical to loading an overlay segment.

>>>> LOADING A DIRECTORY SEGMENT WITH CODE TO LOAD. <<<<

Example is identical to loading a code segment.

Spec. 50-90020490 | Page 2 - 22 | June 8, 1984

•

•

•

•

•

4.2.2

4.2.2.1

DOS CALLS - DIRECTORY ROUTINES

DIRECTORY ROUTINES

INTRODUCTION
Each application which requires segments off the cable will have
a | segment directory loaded into memory. | The segment directory
will be stored as a lK buffer as part of the IOS. | Each entry of
the directory will contain information about one segment being transmitted on the cable.
This section describes the format of the directory in memory, and the method that applications use to access information in the directory.
4.2.2.2 | FORMAT OF DIRECTORY
The segment directory is stored in a lK buffer in the IOS. | The
format of the information in the buffer is as follows:

I
DIRECTORY | I
SEGMENT | I
I | HEADER | I 1---------------1
I | ENTRY 1 | I 1---------------1
I | ENTRY 2 | I 1------------- I

1---------------1
I | ENTRY n | I
The DIRECTORY SEGMENT HEADER is the standard segment header | as
described in section 4.2.1.2.3. | Following the header, | are a
number of entries, one entry per segment in the directory •
Spec. 50-90020490 | Page 2 - 23 | June 8, 1984

DOS CALLS - DIRECTORY ROUTINES

Each directory entry has the following format:
I | TIPE 1-------------------
1 | ~NU 1-------------------
r

I
I

TIER LEVEL

SEGMENT ADDRESS

NAME
1-------------------

1
I RESERVED
I I ________________ _

1 BYTE

1 BYTE

4 BYTES

3 BYTES

18 BYTES

4 BYTES

TYPE and OWNER are each one byte values that are currently
undefined in the NABU NETWORK. | TIER LEVEL is a four byte value
which gives the tier access information of the segment, | each bit
corresponding to a different tier level. | The SEGMENT ADDRESS is
a | three byte value which gives the address number of the segment
on the cable. | This three byte value is the number that must be
put | into the SEGMENT ADDRESS of the SEGMENT CONTROL AND STATUS
BLOCK when a request is made to load the segment off the cable (see section 4.2.1).

The NAME of the segment is given by the applications programmer
when submitting the | segment to the APS. | It can be up to 18
characters long. | In the directory entry the name | is | left
justified and right padded with blanks. | In most cases the
application will know the name of the segment to be loaded, | and
search through the directory to find the segment address in order to request the segment off the cable.
The last four | bytes of each directory entry are | reserved for
system use and should not be used by the application.
Spec. 50-90020490 | Page 2 - 24 | June 8, 1984

•

•

•

•

•

•

DOS CALLS - DIRECTORY ROUTINES

4.2.2.3 ACCESSING THE DIRECTORY

Multi-Segment applications require a means of loading overlays or
data. | The segment loader | requires that a segment number or
address be present in the segment control | block. | The user
directory contains the information which links the segment name
with the segment address. | This directory is loaded into an IOS
directory area. | This is an internal lK buffer.
An application has one DOS calls available | for | accessing the
directory: | the | routine to search through the directory for | a
particular entry.

DIRECTORY SEARCH
PURPOSE: To search
PARAMETERS PASSED:
| | DOS CALL 88H for a particular entry in the directory. c Register - 88H DE Register - Address of a Directory Search Block (see below).

PARAMETERS RETURNED: All information returned is done so in the Directory Search Block as described
| | below.
DATA STRUCTURES: | The Directory Search Block is a | data
structure declared by the application and passed to the IOS when the directory search call is made. the Directory search Block has the following format:
---------------------------------------------------------------- Spec. 50-90020490 | Page 2 - 25 | June 8, 1984

I MATCH PATTERN | I 1 BYTE 1-----------------1
(-----------------( TYPE | I 1 BYTE -----------------1

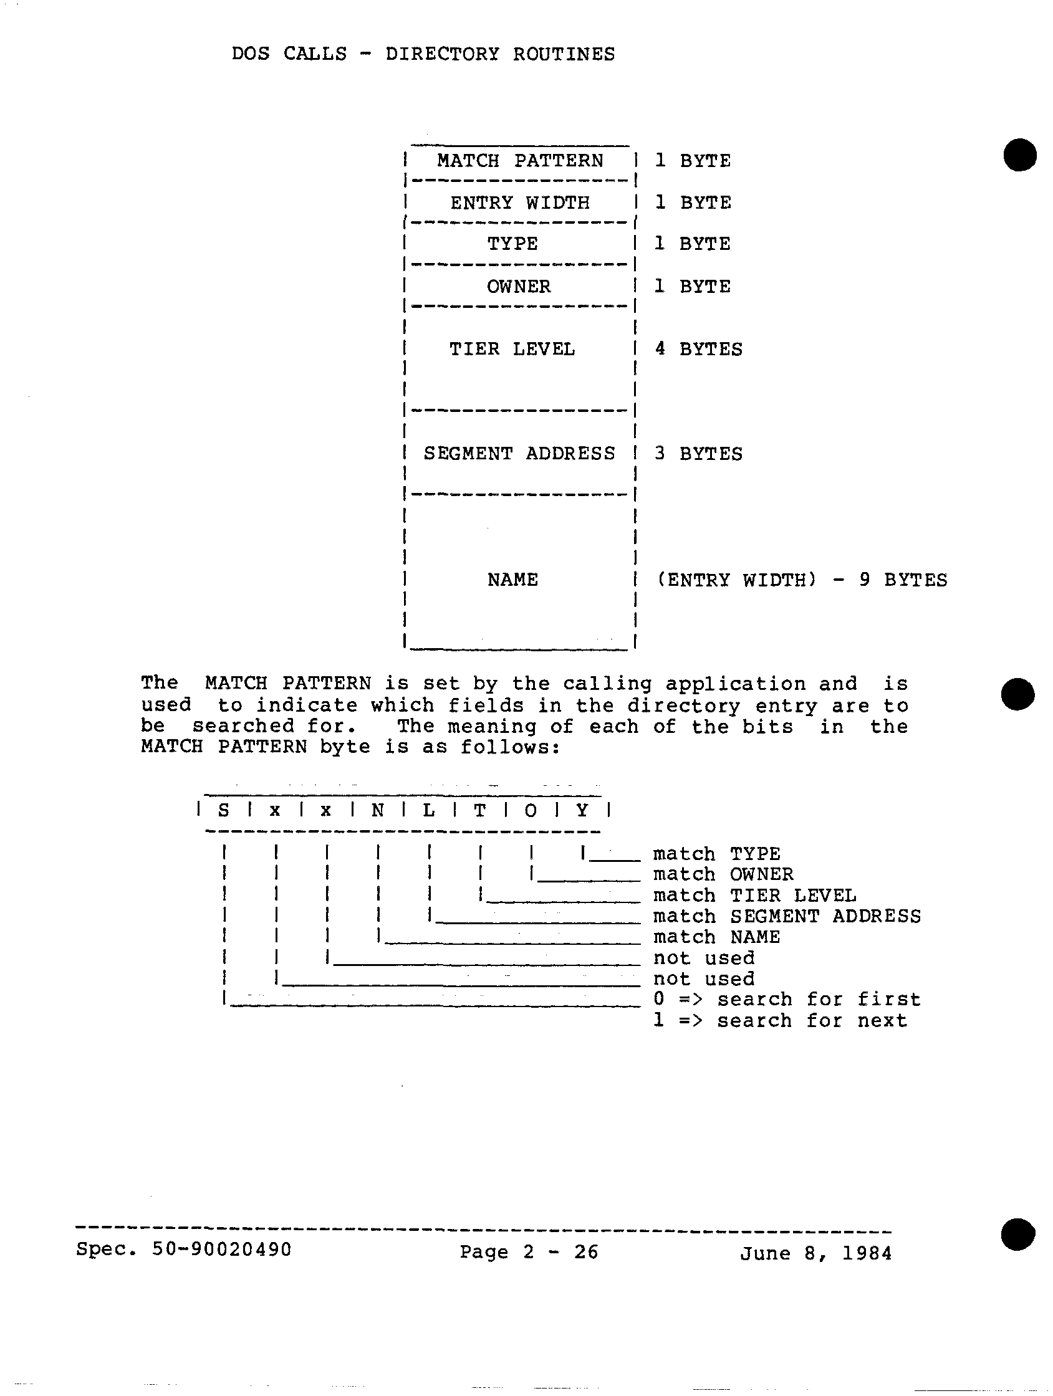
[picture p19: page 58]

DOS CALLS - DIRECTORY ROUTINES
I | ENTRY WIDTH | I 1 BYTE | •
OWNER | I 1 BYTE
----------------- TIER LEVEL | 4 BYTES
SEGMENT ADDRESS | 3 BYTES
NAME | (ENTRY WIDTH) - 9 BYTES
The MATCH PATTERN is set by the calling application and is | •
used to indicate which fields in the directory entry are to
be | searched for. | The meaning of each of the bits in the
MATCH PATTERN byte is as follows:

### S I x I x I N I L I T I 0 I Y I

| | I __ match TYPE match OWNER match TIER LEVEL match SEGMENT ADDRESS match NAME not used not used 0 => search for first 1 => search for next

Spec. 50-90020490 | Page 2 - 26 | June 8, 1984 | •

•

•

•

DOS CALLS - DIRECTORY ROUTINES

If the N, | L, | T, | 0 or Y bits are set in the SEARCH BLOCK,
this | indicates that the corresponding fields of the search
block are to be matched with the directory | entry. | For
example, | if the application wished to search for a segment
with the name COSMOS, | it would set the N bit, and reset the
L, | T, | o, | and Y bits. | If the application wished to search
for | a segment with the name COSMOS ang with owner 33, | it
would set the N and 0 bits, and reset the L, T, and Y bits.
The S bit of the match pattern indicates whether to | search
for | the first directory entry which matches, | or the next
directory entry after the last search.
The ENTRY WIDTH gives the number of bytes in
block following the ENTRY WIDTH byte. It is
compute the number of characters in the NAME.

the search
required to
The fields TYPE, | OWNER, | TIER LEVEL, and NAME correspond to
the fields in the directory entry. | The application will set
these fields | if it wishes to search the directory | for a
corresponding entry. | For example, if the application wished
to search for a segment with owner 33, it would set OWNER to 33; if it wished to search for a segment called NEUTRON BOMB it would set NAME to 'NEUTRON BOMB'.
When matching on NAME the application can use | "wildcard"
features. | A '?' with the high bit set (i.e., | OBFHl | will
match any single character in the corresponding position. For example if NAME is two bytes long and is set to 41H, OBFH, the directory search routine will match Al, A2, AN, or
any other segment whose name starts with A. | A '*' with the
high bit set (i.e., | OAAHl will match any string in the
corresponding position. | For example if NAME is two bytes
long and is set to 41H, | OAAH, | the directory search routine
will match on A, | AA, | Al, | Al2, | Al23, | AAASSSDDD, | or any
segment name beginning with 'A'.

The matching of the tier level fields is done in the same
manner as the tier authorization match in the Adaptor. | That
is the two fields are ANDed together. | If the result is non-
zero then there is a match •
Spec. 50-90020490 | Page 2 - 27 | June 8, 1984

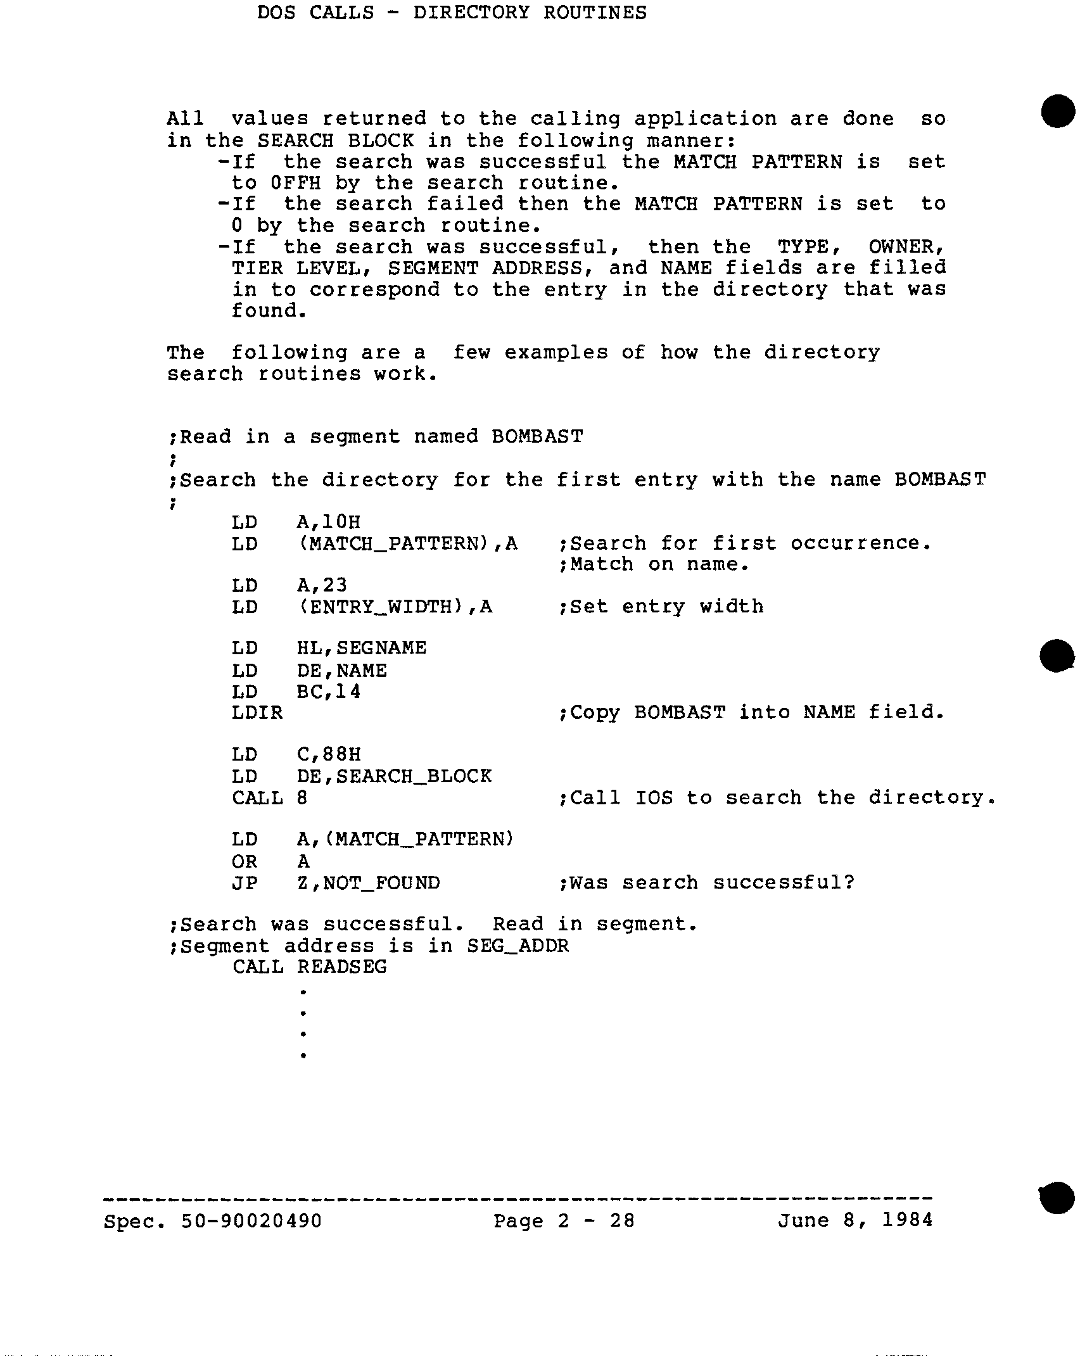
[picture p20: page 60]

DOS CALLS - DIRECTORY ROUTINES

All values returned to the calling application are done | so | ...
in the SEARCH BLOCK in the following manner:
-If the search was successful the MATCH PATTERN is set
to OFFH by the search routine.
-If the search failed then the MATCH PATTERN is set to 0 by the search routine.
-If the search was successful, | then the TYPE, | OWNER,
TIER LEVEL, SEGMENT ADDRESS, and NAME fields are filled in to correspond to the entry in the directory that was found.
The following are a few examples of how the directory search routines work.

:Read in a segment named BOMBAST
:
;Search the directory for the first entry with the name BOMBAST
LD | A,lOH
LD | (MATCH_PATTERNJ,A
LD | A,23
LD | (ENTRY_WIDTH) ,A
LD | HL,SEGNAME
LD | DE,NAME
LD | BC,l4
LDIR
LD | C,88H
LD | DE,SEARCH_BLOCK
CALL 8
LD | A,(MATCH_PATTERN)
OR | A
JP | Z,NOT_FOUND

:Search for first occurrence. :Match on name.
:Set entry width

:Copy BOMBAST into NAME field.

;Call IOS to search the directory.

:was search successful?
:Search was successful. Read in segment. :segment address is in SEG_ADDR
CALL READSEG
Spec. 50-90020490 | Page 2 - 28 | June 8, 1984

•

•

•

•

•

DOS CALLS - DIRECTORY ROUTINES

;Read in second segment in directory which begins with the ;letter 'A' and is owned by 69. This will require doing two ;directory searches; one for the first occurence; and one ;for the next occurence.
LD | A,l2H
LD | (MATCH_PATTERN),A
LD | A,23
LD | (ENTRY_WIDTH) ,A
LD | A, I A'
LD | (NAME) , A
LD | A, OAAH
LD | (NAME + 1) ,A
LD | B,l2
LD | A, I | I
LD | HL,NAME + 2

BLANK: LD (HL) , A
INC HL
DJNZ BLANK
LD | C,88H
LD | DE,SEARCH_BLOCK
CALL 8

;Find first occurence.
;NAME and OWNER.

;Set ENTRY_WIDTH to 23

Match on

;First character of NAME is 'A'.

;Wildcard feature

;Blank out remainder of NAME

;Call directory search

;Search for first is done. | If successful then search for next.
LD | A,(MATCH_PATTERN)
CP | 0
JR | z,NOT_FOUND | ;Was search successful
LD
LD

LD
LD
LD
LD
LD

A,92H
(MATCH_PATTERN),A

A,OAAH
(NAME + 1) ,A

B,l2
A, I I
HL,NAME + 2

;Search for next occurence of ;NAME and OWNER

;Wildcard feature

---------------------------------------------------------------- Spec. 50-90020490 | Page 2 - 29 | June 8, 1984

•

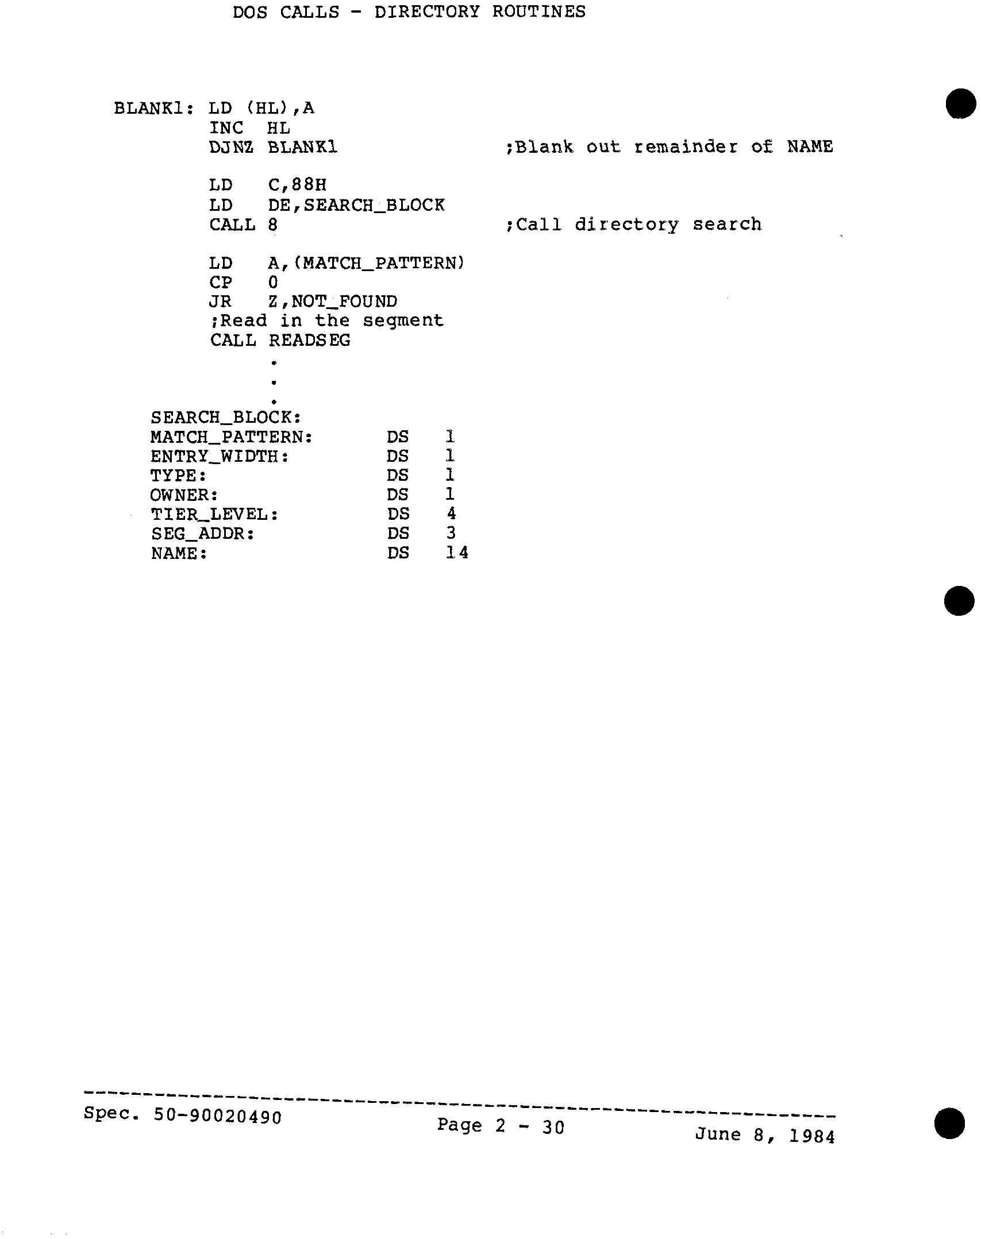
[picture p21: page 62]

DOS CALLS - DIRECTORY ROUTINES

BLANKl: LD (HLl,A
INC HL
DJNZ BLANKl
LD | C,88H
LD | DE,SEARCH_BLOCK
CALL 8
LD | A,(MATCH_PATTERNl
CP | 0
JR | Z,NOT_FOUND
;Read in the segment
CALL READSEG

SEARCH_BLOCK:
MATCH_PATTERN:
ENTRY_WIDTH:
TYPE:
OWNER:
TIER_LEVEL:
SEG_ADDR:
NAME:
| DS
| DS
| DS
| DS
| DS
| OS
| OS
| 1
| 1
| 1
| 1
| 4
| 3
| 14

;Blank out remainder of NAME

;Call directory search

------------ Spec. 50-900;~~;~----------------------------------------------- Page 2 - 30 | June 8, 1984

•

•

•

•

•

DOS CALLS - INTERRUPTS AND TASKING

4.2.3 The Interrupt Structure and Tasking Support

4.2.3.1 Introduction
Because of the Real-Time requirements of the NABU P.C., some sort of real time operating support is required. Because of the overhead involved in context switching and maintaining
task | descriptors | and | the | questionable | utility | to
applications programs, | full multi-tasking is not supported.
Instead, a modified forground/background tasking approach is
used. | The application program runs as the foreground task,
and is | in complete control of the NPC. | The application
program may also call | IOS routines which | run | in the
foreground, | and may also start other tasks running in the
background. | The application program may also use | IOS
routines | to start applications tasks | running in | the
background.

The background tasks are always started by the occurance of
interrupts and must "run to completion". | The NPC supports
eight vectored, | maskable, | nestable, | priority interrupts.
Each interrupt has an interrupt service routine or | "system
task" | associated with it. | Some of the interrupts may also
have one or more "user tasks" associated with it. | These
"user tasks" will start after the system task for the given
interrupt has completed. | The NPC interrupts in order | of
priority are:
1. NNI Receive
-activated when a character is received from
| the NNI
-system task for packet/segment reception handling attached to this interrupt
-No user tasks may be attached
2. NNI Send
-activated when a character has been sent from the NPC to the NNI (Transmitter Buffer Empty) -System task for packet/segment reception handling attached to this interrupt
-No user tasks may be attached
3. Human Interface Input
-activated when a character has been received from the remote keyboard
---------------------------------------------------------------- Spec. 50-90020490 | Page 2 - 31 | June 8, 1984

4.

s.
6.
7.
a.

DOS CALLS - INTERRUPTS AND TASKING

Video Frame Sync (60 Hz Clock)
-activated every 1/60 sec by start of
vertical retrace on the TMS 9918A Video Disp~ay -System task to: flash cursors, update real t~me
clock, etc. etc attached to this interrupt
-System task to timeout on NNI response attached to this interrupt
-Any number of user tasks may be attached.

Option card Interrupt from Slot No. 0
Option Card Interrupt from Slot No. 1 Option Card Interrupt from Slot No. 2 Option Card Interrupt from Slot No. 3

Option card Interrupts
-activated by option cards
-one system task per card may be attached as required
-one user task per card may be attached

4.2.3.2 Critical Regions
For the purposes of the IOS, a critical region is defined as
a section of executable code, or data structure which may be

•

accessed by only one concurrently executing task at a | time. | •
Critical | regions are bound to exist in any system which
supports more than one concurrently executing task.
Two IOS BOS calls are used to protect critical regions in
the | IOS and in applications programs. | When entring a
critical region, | an application task must call the | routine
"CRITICAL REGION BEGIN". | This | is call number 02 in the IOS
BOS and Its assembly language name is CRBEG. | It takes no
parameters. | When leaving the critical region the | routine
"CRITICAL_REGION_END" must be called. This is call number 03
in the !OS BOS and its assembly language name is | CREND. | No
registers are destroyed by these calls.
Critical regions are nested by CRBEG and CREND. This nesting
is analogous to opening a left bracket for each CRBEG | that
is performed and closing the critical region with a | ri~ht
bracket ~ach ~ime a CREND is performed. | In this way it is
easy ~o.v~sual~~e that one may have a critical region within
a | cr~t1ca~ reg1~n and that interrupts will only be | enabled
whe~ the f1na1 r1ght bracket (CRENDl is reached. | It is also
obv1ous. that there must be as many CRENDs as there are CRBEGs 1n order to keep the interrupt control in order.
•

•

## *** NOTE ***

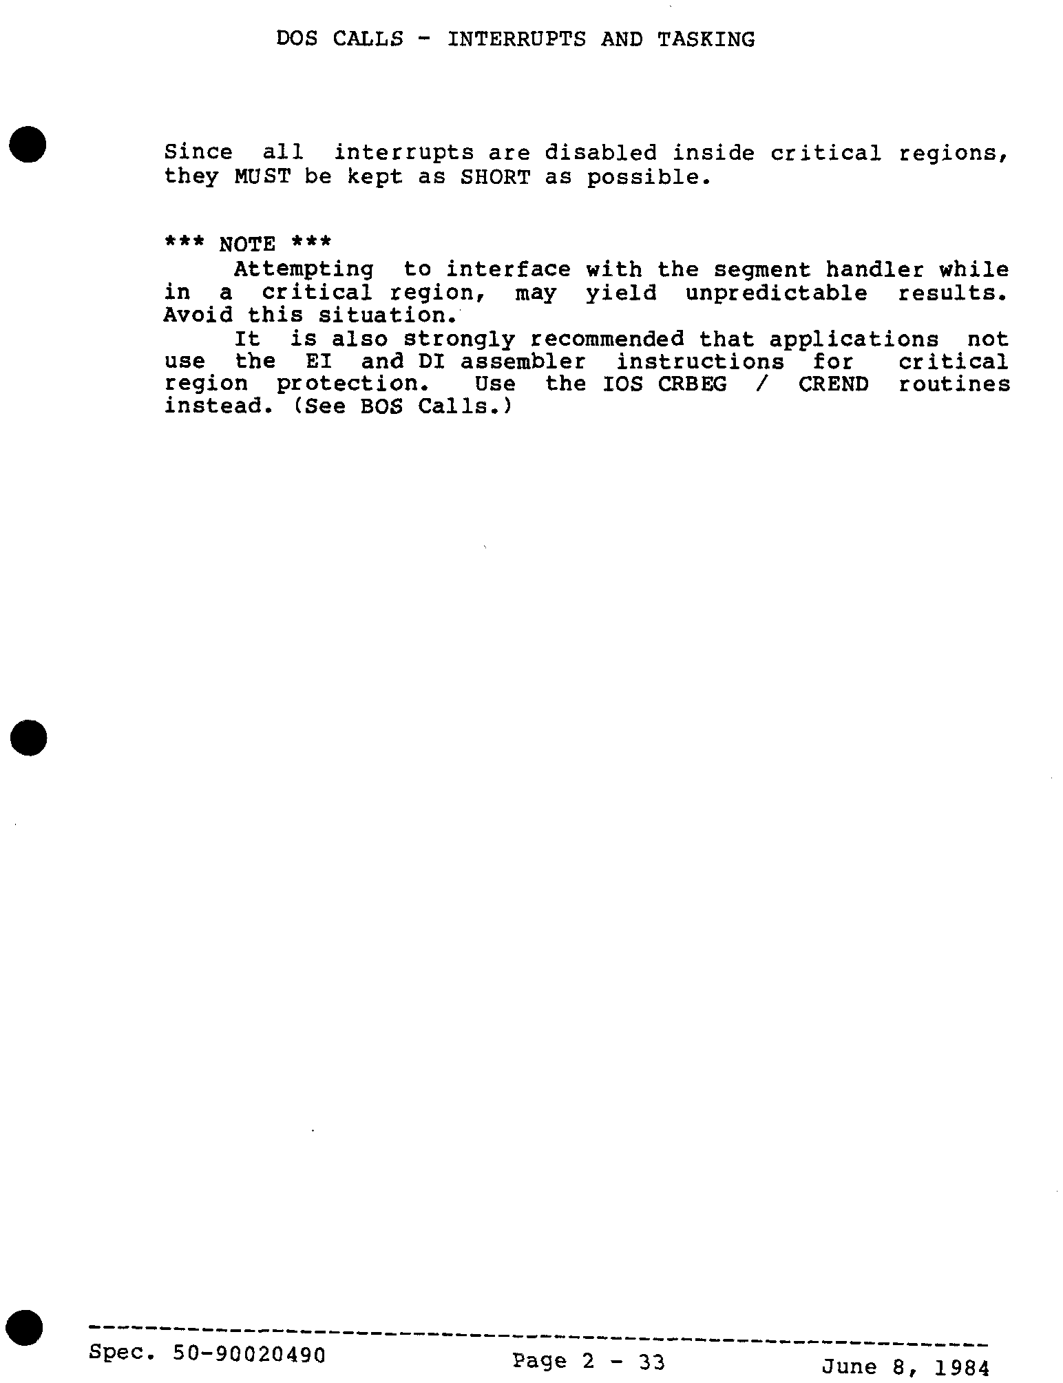
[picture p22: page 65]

•

•

DOS CALLS - INTERRUPTS AND TASKING

Since all interrupts are disabled inside critical regions, they MUST be kept as SHORT as possible.

Attempting to interface with the segment handler while in a critical region, may yield unpredictable results. Avoid this situation.
It is also strongly recommended that applications not
use the EI and DI assembler instructions for | critical
region protection. | Use the IOS CRBEG I | CREND routines
instead. (See BOS Calls. l

DOS CALLS - INTERRUPTS & TASKING - CLOCK

4.2.3.3 user Task Attachment Routines

4.2.3.3.1 Attaching Tasks to the Clock

VAR

An application program may attach tasks to the TMS-9918A VDP
frame | interrupt. | As many tasks as desired may be attached.
Tasks may be attached and removed from the clock by both the
main application program and by other tasks. | In fact a | task
may remove itself from the clock. It is also possible to have multiple invocations of the same piece of code as separate tasks.
BEFORE CLOCK-ATTACHED TASKS ARE EXECUTED, | ALL REGISTERS
ARE SAVED, | AND THEY ARE RESTORED AFTER THE COMPLETION OF
THE TASK.
A data structure called a TASK_CONTROL_BLOCK (TCB) is used to keep track of the relevent parameters of a task which is attached to the clock. The TCB has the following structure:

TASK_CONTROL_BLOCK: RECORD OF
BEGIN
NEXT_BLOCK
RESET_INTERVAL
CURRENT_ INTERVAL
TASK_ADDRESS
PARAMETER_BLOCK

WORD
BYTE
BYTE
WORD
USER_DEFINITION l
The NEXT_BLOCK word is used by the operating system to place the TCB on a linked list with other TCB's. This word should not be altered by applications tasks at any time.

The CURRENT_INTERVAL byte counts the number of ticks that
have gone by since the last time the task was activated | It
is ~cce~sed by the IOS but may | also be accessed by
appl1cat1ons tasks. | The IOS algorithm in which this byte is
used is as follows:
---------------------------------------------------------------- Spec. 50-90020490 | Page 2 - 34 | June 8, 1984

•

•

•

•

•

•

DOS CALLS - INTERRUPTS & TASKING - CLOCK

ON EACH CLOCK INTERRUPT DO
BEGIN
FOR EACH TASK_CONTROL~BLOCK DO
BEGIN

END.

CURRENT_INTERVAL = CURRENT_INTERVAL - 1; IF CURRENT_INTERVAL = 0 THEN DO
BEGIN

END
END

CURRENT_INTERVAL := RESET_INTERVAL; RUN_THIS_TASK( TASK_ADDRESS);

The byte CURRENT_INTERVAL is | decremented every clock | tick
until it equals zero. When CURRENT_INTERVAL = 0, the task is executed. Therefore an INTITIAL DELAY may be issued before the task is dispatched by initializing CURRENT_INTERVAL to a
value | greater | than one. | Before execution of | the task,
CURRENT_INTERVAL | is | reset to the value of RESET_INTERVAL.
CURRENT~INTERVAL is measured in clock ticks which are approx 1/60 of a second long. For example a value of 5 means the task will every 5/60 of a second and a value of 1 means the task will run every 1/60 of a second or 16 milliseconds.
NOTE: | That | initializing CURRENT_INTERVAL to zero will
cause the task to be delayed for 256 clock ticks (approx 4 seconds) before it is executed a first time.

The CURRENT_INTERVAL byte can be used to determine when a task has last run or when a task will next run. It will also determine when a newly created task will next run.

The RESET INTERVAL byte | is the value to which | the byte
CURRENT_INTERVAL | is initialized to after RESET_INTERVAL has
been decremented to zero. | This byte is never changed by the
operating system, | but | can be | changed for | purposes of
changing the re-execution time of an active task.
The TASK_ADDRESS word contains a pointer to the start o! tn~
~ask or | user | s~broutine. | When control is given to | the
~nterrupt subrout~ne, | the pointer to the TASK CONTROL BLOCK
(TCBl is in the.BC register so that the user may access any
of the | bytes ~n the TCB and modify them if he so desires.
NOTE also that this pointer is useful for | accessing vari-
ables | (bytes or words) | immediatly below the 6 | byte TASK_CONTROL_BLOCK •

DOS CALLS - INTERRUPTS & TASKING - CLOCK

Also note that an interrupt subroutine or task should always end with a RETURN (RET) statement in order to return control to the application's mainline and never jump out of a user task otherwise interrupts will remain permantly disabled.
Interrupt subroutines should also always be as | short | as
possible and never take longer than 16 milliseconds (1 CLOCK
TICK) to execute. | If it should be neccessary to run a | task
that | takes longer than 16 miliseconds, | it should be broken
up into two tasks which execute on alternate interrupts. | To
do this start one task immediatly and delay the second
task | one | clock | tick | by | setting | CURRENT_INTERVAL
initially to two.
The | PARAMETER_BLOCK is an optional data structure which may
be accessed by an applications task. | When a task is started
the address of the TASK_CONTROL~BLOCK (ie a pointer to the
NEXT_BLOCK word) is passed in the BC Register. | This | gives
the task access to its own TCB. Using the parameter block to
keep | all | of | the task's data | will | allow | several
instantiations of the same code as separate tasks without resorting to keeping data on stack frames.
There are a few important calls which should be mentioned at
this point, because tasks may not run if they are not done.

•

A call must be done at the start of every program to link in | •
the BOS routines so that calls to CRBEG and CREND will work.
(See section on BOS Calls for information on linking BOS routines using DOS call 90H.l

ex:
MAIN::
LD C,90H
LD DE,LNKTB##

CALL DOS

;DOS CALL 90H
;ADDRESS OF
;LINK TABLE
;CALL SYSTEM
A call must be done to CLKPRM (BOS CALL #37) should be done to enable user task dispatching when the user is ready to have the tasks dispatched.
ex: | LD C,4 | ;CONSIDER CLOCK
;TASK
;DISPATHING BIT
LD E,4 | ;SET BIT #2 | TO
;TURN ENABLE
;TASK DISPATCHING

## CALL CLKPRM## :NOW TASKS WILL

;RUN IF INTERRUPTS
;ARE ENABLED
---------------------------------------------------------------- Spec. 50-90020490 | Page 2 - 36 | June 8, 1984 | •

•

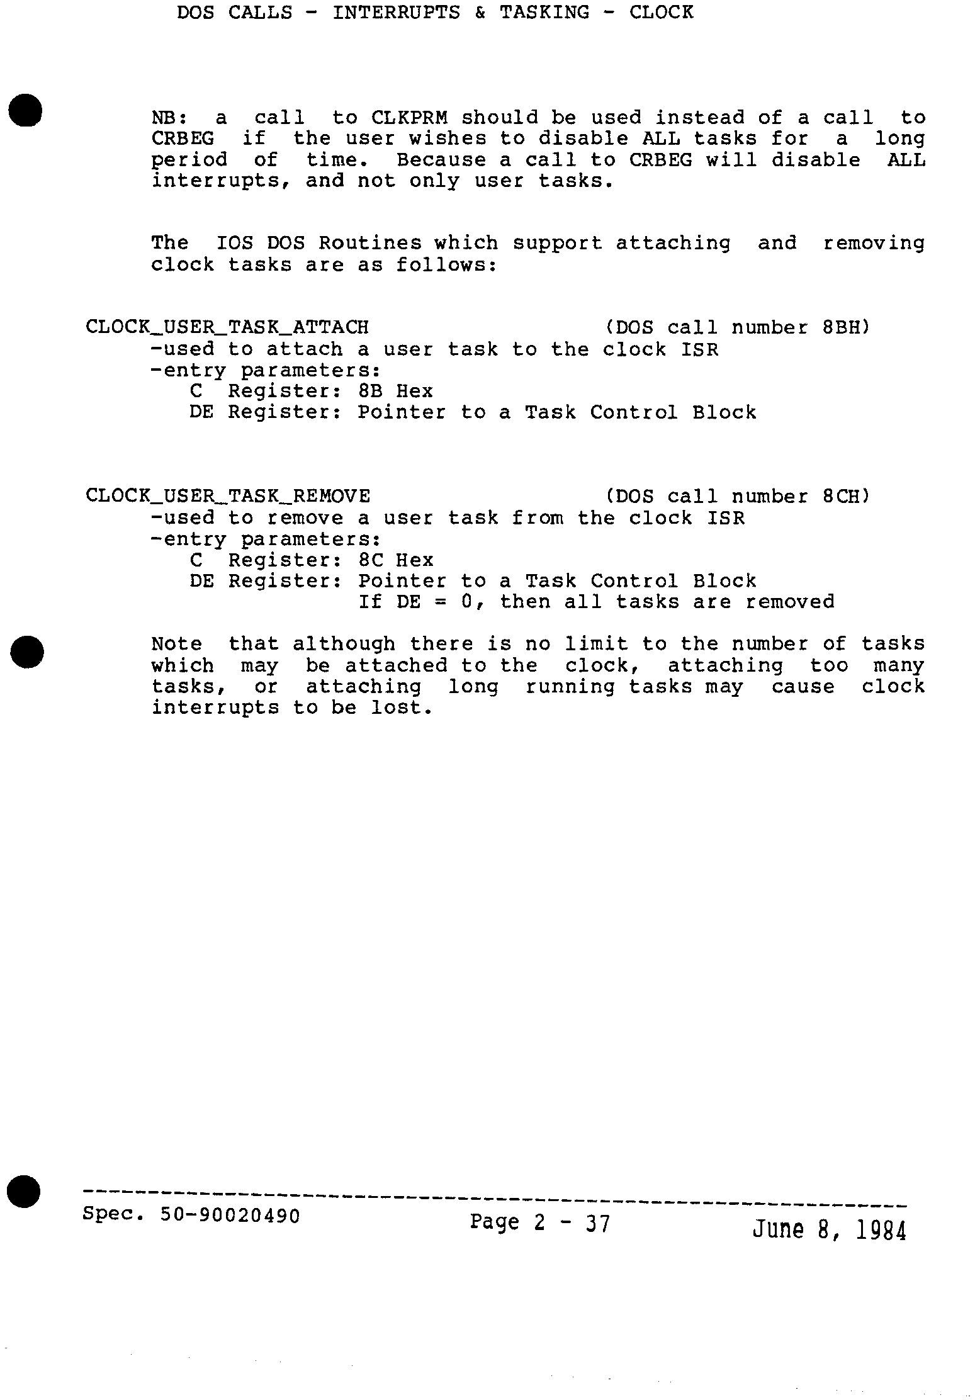
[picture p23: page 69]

•

•

DOS CALLS - INTERRUPTS & TASKING - CLOCK

NB: | a | call to CLKPRM should be used instead of a call to
CRBEG | if the user wishes to disable ALL tasks for | a | long
period of time. | Because a call to CRBEG will disable ALL
interrupts, and not only user tasks.

The IOS DOS Routines which support attaching and removing clock tasks are as follows:

CLOCK_USER_TASK_ATTACH | (DOS call number 8BH)
-used to attach a user task to the clock ISR
-entry parameters:
C Register: 8B Hex
DE Register: Pointer to a Task Control Block
CLOCK_USER_TASK_REMOVE | (DOS call number 8CH)
-used to remove a user task from the clock ISR
-entry parameters:
C Register: 8C Hex
DE Register: Pointer to a Task Control Block

Note that
which may
tasks, or
interrupts
| If DE = 0, then all tasks are removed
although there is no limit to the number of tasks
be attached to the | clock, | attaching too many
attaching long running tasks may cause clock
| to be lost •

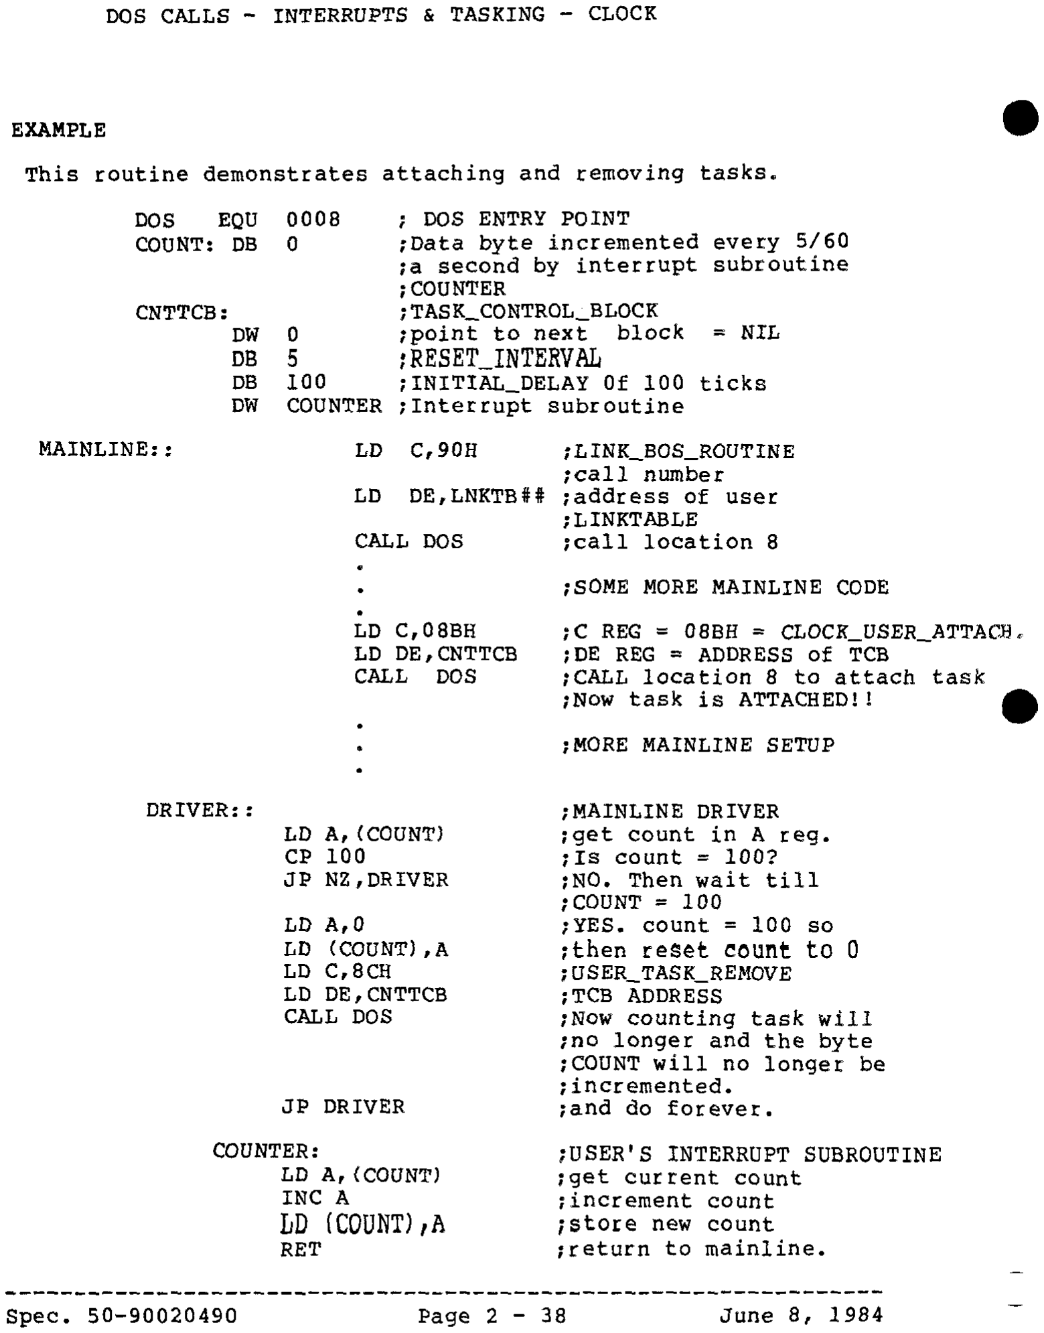
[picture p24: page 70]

DOS CALLS - INTERRUPTS & TASKING - CLOCK

EXAMPLE

This routine demonstrates attaching and removing tasks. | •
DOS | EQU
COUNT: DB

CNTTCB:
| DW
DB
| DB DW

MAINLINE::

DRIVER::

0008 | ; DOS ENTRY POINT
0 | ;Data byte incremented every 5/60
;a second by interrupt subroutine ;COUNTER
;TASK_CONTROL_BLOCK
0 | ;point to next block = NIL
5 | :RESET_INTERVAL
100 | ;INITIAL_DELAY Of 100 ticks
COUNTER ;Interrupt subroutine
LD C,90H | ;LINK_BOS_ROUTINE
;call number
LD DE,LNKTB#i ;address of user ;LINKTABLE
CALL DOS | ;call location 8

LD C,08BH
LD DE, CNTTCB
CALL DOS

LD A, {COUNT)
CP 100
JP NZ,DRIVER
LD A,O
LD {COUNT),A
LD C,8CH
LD DE,CNTTCB
CALL DOS

JP DRIVER

;SOME MORE MAINLINE CODE
;C REG = 08BH = CLOCK_USER_ATTACB, ;DE REG = ADDRESS of TCB
;CALL location 8 to attach task
;Now task is ATTACHED!! | •
;MORE MAINLINE SETUP

;MAINLINE DRIVER
;get count in A reg.
;Is count = 100?
;NO. Then wait till
;COUNT = 100
;YES. count = 100 so
;then res~t count to 0
;USER_TASK_REMOVE
;TCB ADDRESS
;Now counting task will
;no longer and the byte
;COUNT will no longer be
;incremented.
;and do forever.
COUNTER: | ;USER'S INTERRUPT SUBROUTINE
;get current count
;increment count

Spec. 50-90020490

LD A, {COUNT)
INC A
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

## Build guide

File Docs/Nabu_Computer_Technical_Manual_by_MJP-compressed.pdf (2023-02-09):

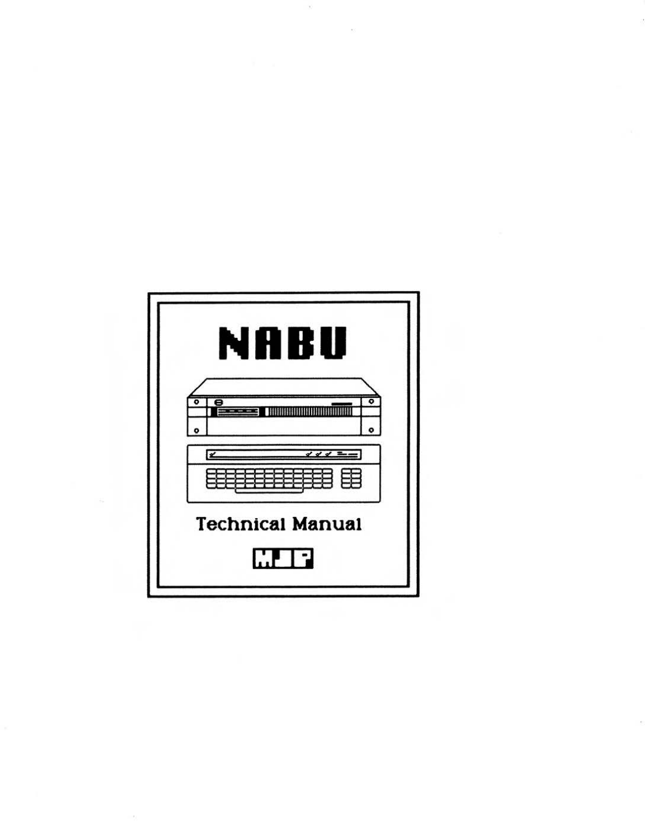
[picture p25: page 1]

# NHBU

/

## Technical Manual

# I.'.P I -~

NABU TECHNICAL MANUAL

HARDWARE INFORMATION

General Description

The Home Cable Computer (HCC) processor board is a general purpose single board computer. Based on a Z80A microprocessor it has 64K of on board dynamic RAM. The HCC is designed to operate in a home setting, using the standard color or monochrome television set as a display and sound output device.
The processor board is approximately 9.626" by 12". It provides interfaces to the Home Cable Computer Adapter (HCCA), the four option card slots, and the detachable keyboard.
The processor board is mounted just above, and parallel to, the bottom of the HCC basic package. A steel bulkhead plate is mounted across the back edge of the board in the vertical plane. This bulkhead has all external interface connectors mounted on it, providing for RF shielding and strain relief. When the processor board is installed in the HCC basic package, the bulkhead is screwed to the inside back surface with the connectors protruding through rectangular slots in the rear of the package. Thus, the bulkhead is electrically part of the steel package and effectively eliminates RF radiation to the outside.

Clocks
The processor board is designed to operate in a television environment requiring specific clock frequencies. The processor board has a I 0.738635 megahertz.!. 50 ppm fundamental frequency, parallel-mode crystal. This is directly connected to the video processor. The video processor divides the clock frequency by three resulting in a 3.579545 (referred to hereafter as 3.58) megahertz basic clock rate. This 3.58 megahertz clock is used to drive the Z80A microprocessor.

ZOOAMicroprocessor
The processor board contains a Z80A microprocessor. In addition to application software, it controlls the overall HCC system and has inherent dynamic RAM refresh capabllity.

ROM
A 4K byte ROM (Read Only Memory) contains the bootstrap software. Upon reset, this software performs a minimal self test on the processor board and initializes the system. It also contains software which can communicate with the HC.CA or a floppy disk to allow for bootstrapping.
The ROM may be selected or deselected under software control. When selected, any memory read request to addresses 0000 - OFFF hex will be directed to the ROM; write requests to these addresses will go to RAM.

RAM
The processor board contains 641< bytes of RAM (Random Access Memory), available to the CPU. The memory consists of eight 641< x I dynamic RAM chips, refreshed automatically by the Z80A.

Address Decoder
This logic provides all memory mapping and 1/0 address decoding.

Video Processor
The HCC processor board uses the TMS9918A video display processor chip. This processor generates NTSC compatible color video signal.
The video processor is connected to the Z80A data bus and resides in 1/ 0 space. The video processor controls its own 16K x 8 dynamic RAM refresh memory which is not connected to the Z80A data bus. The Z80A issues commands to the video processor to control it and can read or write the refresh RAM through the video processor.
The output of the video processor is connected to the RF modulator for display on the television set. This output is also available on another connector as NTSC compatible video signal, which can drive a video monitor.
For more details, refer to the TMS9918A Video Processor Data Manual.

Audio Processor
The HCC processor board contains an AY-3-891 0 programmable sound generator chip. This chip produces three channels of sound used in applications such as sound effects, music synthesis, alarms, and FSK modems.
The sound generator is programmed by the Z80A to produce the desired audio waveforms. For more detail, see the AY-3- 891 0/ 8912 Programmable Sound Generator Data Manual.
In order to use the speaker of the television set, the output of the sound generator is connected to the RF modulator. In addi tion, the audio output is available on a connector for transmission to an external ampl if ier.
The AY-3-891 0 contains two 8-bit bi-directional parallel ports. One is used to output the interrupt masks; the other, to read the status flags.

RF Modulator
The RF modulator combines the NTSC compatible video signal from the video processor with the sound generator output. The resulting signal can be received on channel 3 or 4 of a standard home television set. The selection of channel 3 or 4 is made by an internal switch mounted on the processor board.
The RF output Impedance is 75 ohms. For connection to 300 ohm television antenna input terminals, an external impedance matching balum must be used.

RF Switch
Since the HCC is usually functioning in a CATV environment, provisions must be made to accommodate a cable converter signal as well as the RF output from the HCC.
To accompl ish this, the HCC processor board has an external RF input connector. Either the external signal or the processor signal may be selected by a video switch and transmitted to the RF output connector. This output is connected to the antenna input of the TV set. The computer can switch between the two RF sources under program control. If the HCC power is off, the external input is selected automatically.
Note: The RF switch cannot carry a raw CATV signal due to bandwidth limitations; the switch is designed to carry channel 3 or 4 only.

Keyboard Interface
This interface supplies unregulated + 10 volt DC power to the detachable keyboard and receives serial data from the keyboard. The keyboard contains a single chip microprocessor which performs keyboard encoding and games control. The keyboard output is received by the HCC 8251 programmable communications interface. The data rate is 6992 baud using EIA RS422 transmission over twisted pair cable with overall shield.

Printer Interface
The printer interface is capable of driving a subset of the standard Centronics parallel printer.
The printer is accessed through a parallei port with 8 data lines. It is connected to the HCC via a 15 pin, female, D-type connector.

HCCA Interface
The HCCA interface consists of a full duplex, 111 kilobit per second serial interface using EIA RS422 transmission. The processor can send commands to the HCCA, requesting data or programs from the device connected.

Option Card Interface
This interface provides bi-directional data, address and control signals to up to four opt ton cards, wh1ch can be installed in the basic HCC package. Each card Is assigned 16 consecutive 1/0 addresses as follows:
a) slot 0- addresses CO to CF
b) slot 1 -addresses DO to OF
c) slot 2- addresses EO to EF
d) slot 3- addresses FO to FF

The buffered signal bus is brought to four sets of pins at the front edge of the processor board. Each option card is connected to one set of pins by a flexible cable with an in line female connector.

Interrupt Logic
The processor board permi ts eight levels of maskable, vectored-priority interrupts. The interrupts are vectored using Z80 mode 2. Each interrupt level is masked by a bit in the sound processor port A. They are listed in order of decreasing priority as follows:
0) HCCA Receive
I) HCCA Send
2) Detachable Keyboard
3) Video Frame Sync
4) Option Card 0
5) Option Card I
6) Option Card 2
7) Option Card 3

Reset Switch
A momentary contact pushbutton switch is mounted on the front of the chassis to provide for a system reset.

Control Register
A register is provided to permit software control of the following devices:
a) 3 LED's mounted on the front panel
b) ROM enable
c) RF switch
d) Printer data strobe

Status Byte
A status byte can be read by the Z80 via the sound processor port B. The status flags are listed in PROGRAI"t11NG INFORMATION, Sound Generator.

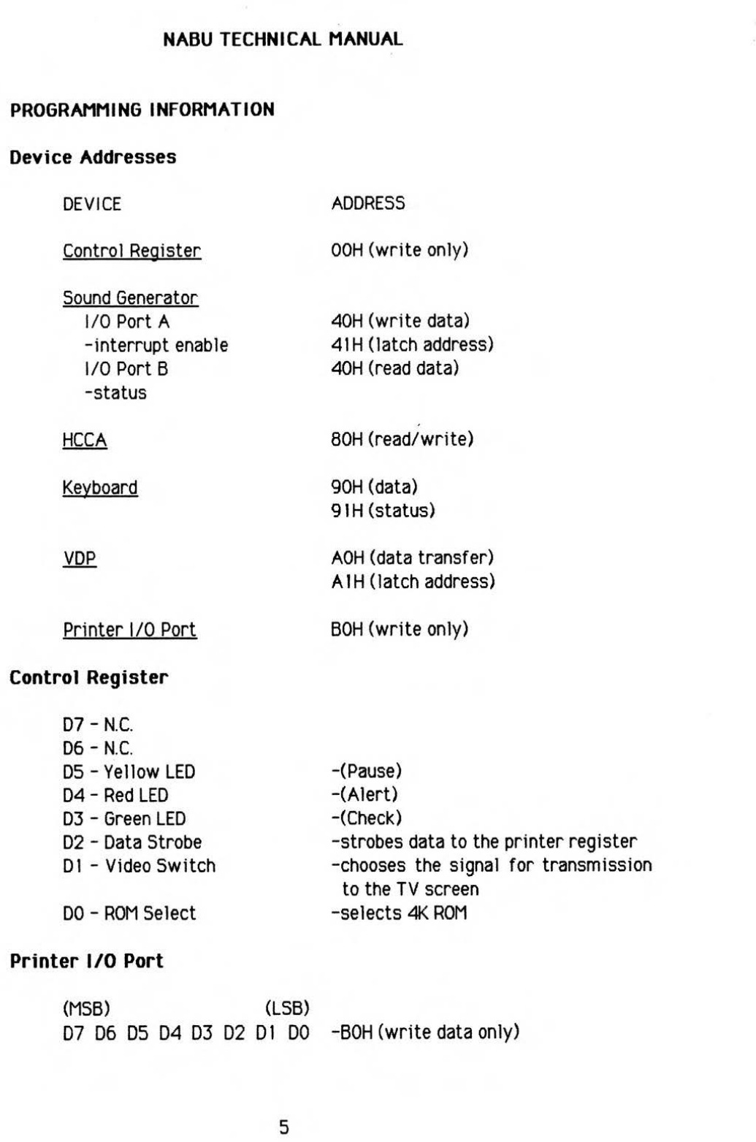
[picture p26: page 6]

PROGRAMMING INFORMATION

Device Addresses

DEVICE

Contro 1 Register

Sound Generator
1/0 Port A
-interrupt enable
1/0 Port B
-status

Keyboard

Printer I /0 Port

Control Register

D7- N.C.
D6- N.C.
D5- Yellow LED
D4- Red LED
D3 - Green LED
D2 -Data Strobe
D I - Video Switch

DO- ROM Select

Printer 1/0 Port

(MSB) | (LSB)

ADDRESS

OOH (write only)

40H (write data)
41 H (latch address)
40H (read data)

80H (read/write)

90H (data)
91 H (status)

AOH (data transfer)
A 1 H (latch address)

BOH (write only)

-(Pause)
-(Alert)
-(Check)
-strobes data to the printer register -chooses the signal for transmission to the TV screen
-selects 4K ROM

07 06 05 04 03 02 D 1 DO -BOH (write data only)

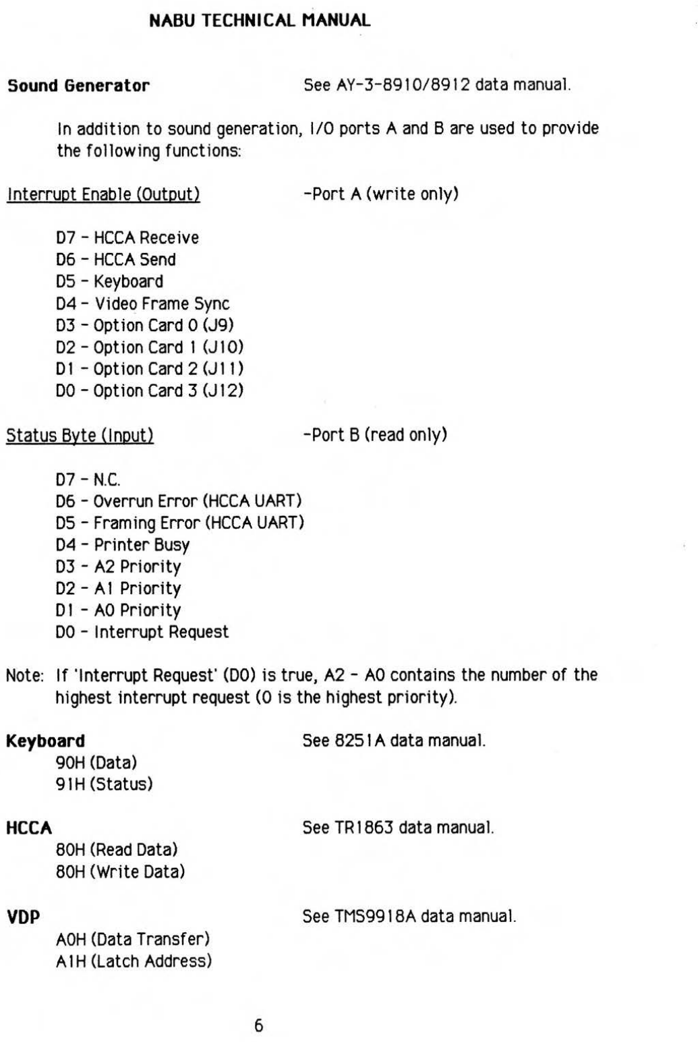
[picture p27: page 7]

Sound Generator | See AY-3-8910/8912 data manual.

In addition to sound generation, 1/0 ports A and B are used to provide the following functions:

Interrupt Enable (Output) | -Port A (write only)

07 - HCCA Receive
06 - HCCA Send
05 - Keyboard
04- Videq Frame Sync
03 -Option Card 0 (J9)
02 - Option Card 1 (J 1 0)
01 -Option Card 2 (J11)
DO- Option Card 3 (J 12)
Status Byte (Input) | -Port B (read only)

D7- N.C.
D6 - Overrun Error (HCCA UART)
D5- Framing Error (HCCA UART)
04 - Printer Busy
D3 - A2 Priority
D2 - A 1 Priority
01 - AO Priority
DO- Interrupt Request

Note: If 'Interrupt Request' (DO) is true, A2 - AO contains the number of the highest interrupt request (0 is the highest priority).

Keyboard

HCCA

VDP

90H (Data)
91 H (Status)

80H (Read Data)
80H (Write Data)

AOH (Data Transfer)
A 1 H (Latch Address)

See 825 1 A data manua 1.

See TR 1863 data manua 1.

See TMS9918A data manua 1.

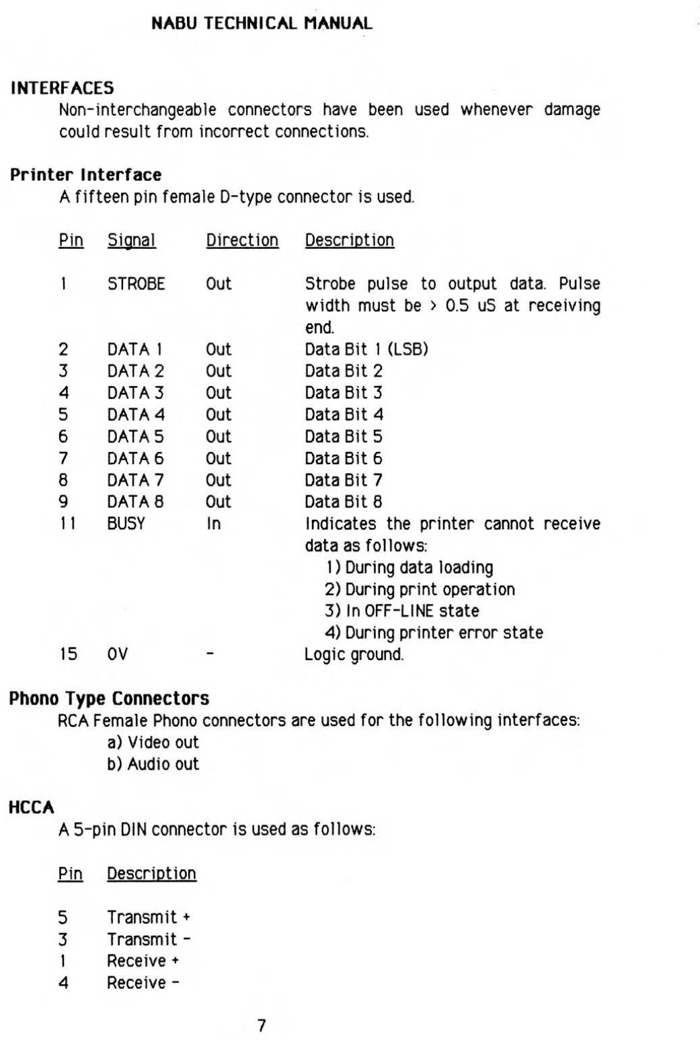
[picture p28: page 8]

INTERFACES
Non-interchangeable connectors have been used whenever damage could result from incorrect connections.

Printer Interface
A fifteen pin female D-type connector is used.
Pin | Signal | Direction | Description
| STROBE | Out | Strobe pulse to output data. Pulse width must be > 0.5 uS at receiving
| | | end.
2 | DATA 1 | Out | Data Bit 1 (LSB)
3 | DATA2 | Out | Data Bit 2
4 | DATA3 | Out | Data Bit 3
5 | DATA4 | Out | Data Bit 4
6 | DATA5 | Out | Data Blt 5
7 | DATA6 | Out | Data Bit 6
8 | DATA 7 | Out | Data Bit 7
9 | DATA8 | Out | Data Bit 8
1 1 | BUSY | In | Indicates the printer cannot receive
| | | data as follows:
1) During data loading
2) During print operation
3) In OFF-LINE state
4) During printer error state
15 | ov | | Logic ground.

Phono Type Connectors
RCA Female Phono connectors are used for the following interfaces:
a) Video out
b) Audio out

HCCA
A S-pin DIN connector is used as follows:
Pin | Description
5 | Transmit+
3 | Transmit-
1 | Receive+
4 | Receive-

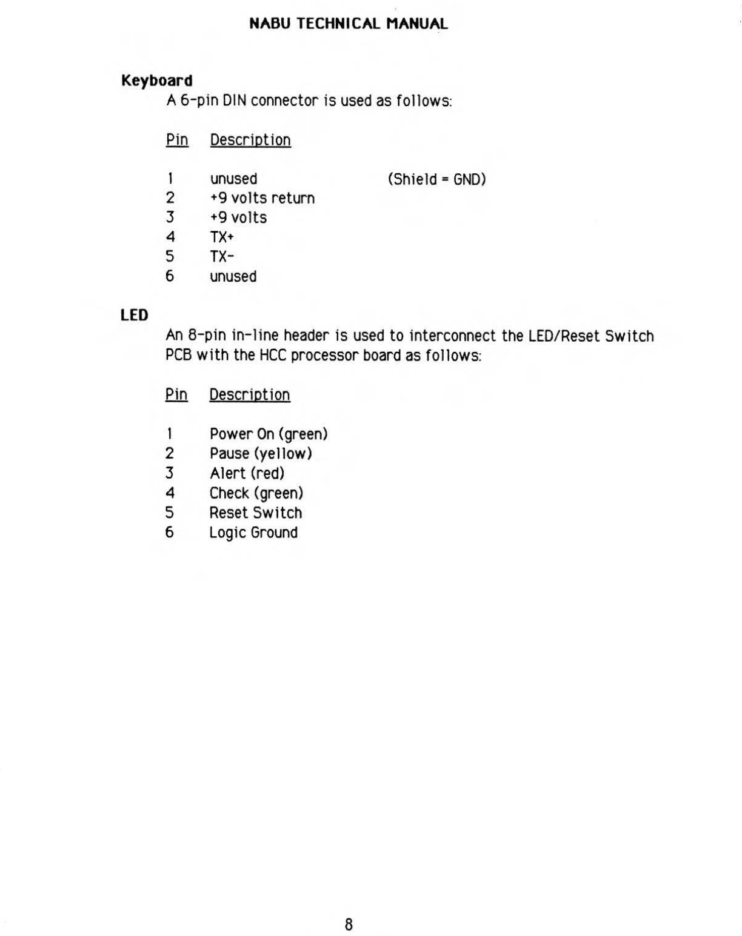
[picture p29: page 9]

Keyboard

LED

A 6-pin DIN connector is used as follows:

Pin | Description
1 | unused | (Shield= GND)
2 | +9 volts return
3 | +9 volts
4 | TX+
5 | TX-
6 | unused

An 8-pin in-line header is used to interconnect the LED/ Reset Switch PCB with the HCC processor board as follows:

Pin | Description
1 | Power On (green)
2 | Pause (yellow)
3 | Alert (red)
4 | Checl< (green)
5 | Reset Switch
6 | Logic Ground

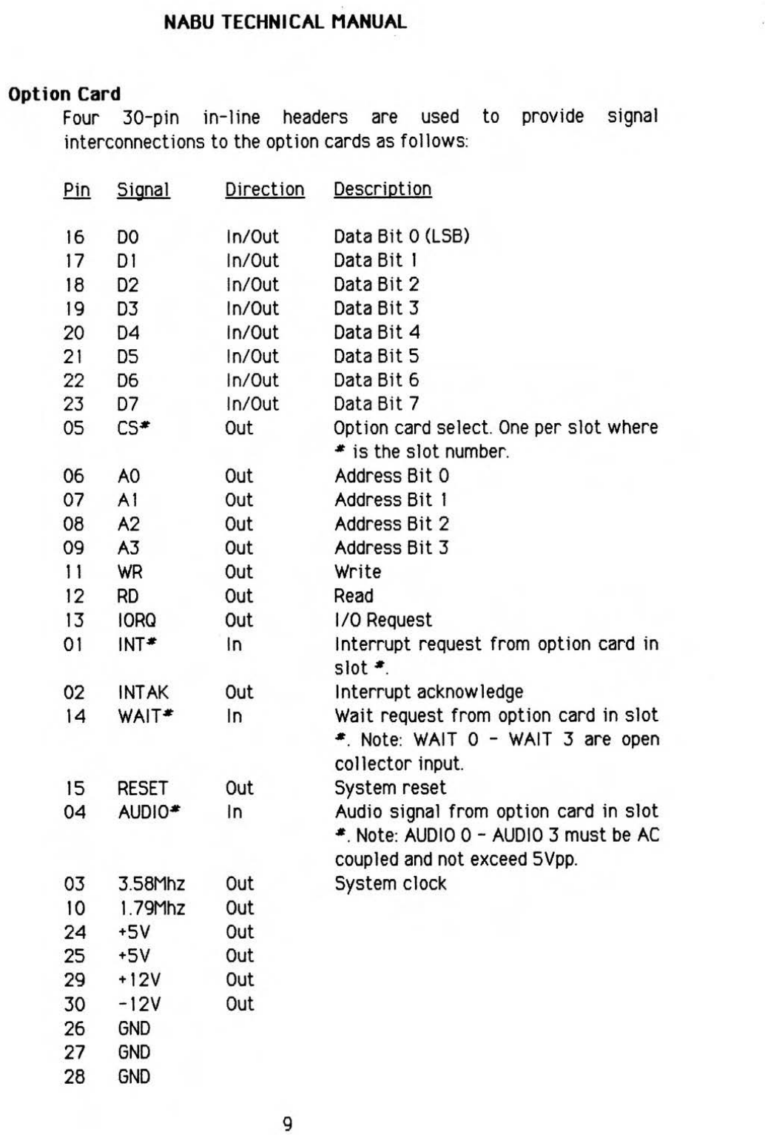
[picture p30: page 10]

Option Card
Four 30-pin in-line headers are used to provide signal interconnections to the option cards as follows:
Pin | Signal | Direction
16 | DO
17 | Dl
18 | D2
19 | D3
20 | D4
21 | D5
22 | D6
23 | D7

## o5 cs•

06 | AO
07 | AI
08 | A2
09 | A3
11 | WR
12 | RD
13 | IORQ
01 | INT•
02 | INTAK
14 | WAIT•
15 | RESET
04 | AUDIO•
03 | 3.58Mhz
I 0 | l.79Mhz

In/Out
In/Out
In/Out
In/Out
In/Out
In/Out
In/Out
In/Out
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
24 | +5V | Out
25 | +5V | Out
29 | + 12V | Out
30 | -12V | Out
26 | GND
27 | GND
28 | GND

Description

Data Bit 0 (LSB)
Data Bit I
Data Bit 2
Data Bit 3
Data Bit 4
Data Bit 5
Data Bit 6
Data Bit 7
Option card select. One per slot where
- is the slot number.
Address Bit 0
Address Bit 1
Address Bit 2
Address Bit 3
Write
Read
1/0 Request
Interrupt request from option card in slot •.
Interrupt acknowledge
Wait request from option card in slot •. Note: WAIT 0 - WAIT 3 are open collector input.
System reset
Audio signal from option card in slot
- . Note: AUDIO 0 - AUDIO 3 must be AC coupled and not exceed 5Vpp.
System clock

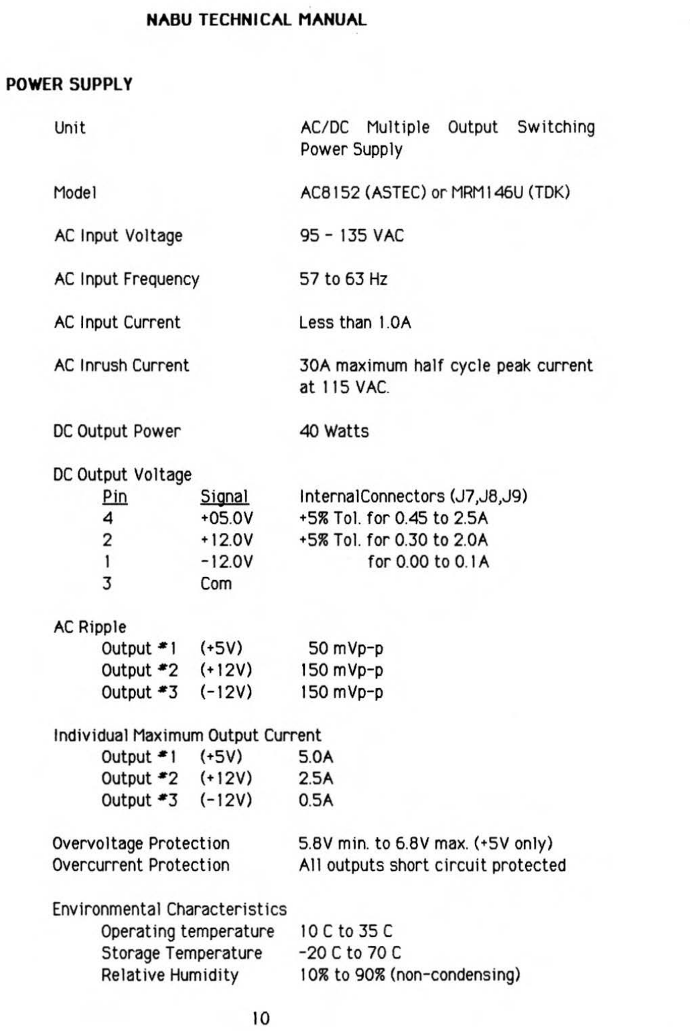
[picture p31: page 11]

NABU TECHNICAl MANUAl

POWER SUPPLY

Unit

Model

AC Input Voltage

AC Input Frequency

AC Input Current

AC Inrush Current

DC Output Power

DC Output Voltage
£in | Signal
4 | +05.0V
2 | + 12.0V
1 | -12.0V
3 | Com

AC Ripple
Output •1 Output •2 Output •3 | (+5V)
| (+ 12V)
| (-12V)

AC/DC Multiple Output Switching Power Supply

AC8152(ASTEC)orMRM146U(TDK)

95- 135 VAC

57 to 63Hz

Less than I.OA

30A maximum half cycle peak current at 115 VAC.

40 Watts

I nterna 1 Connectors (J7,J8,J9) +5~ To1. for 0.45 to 2.5A
+5~ To1. for 0.30 to 2.0A
for 0.00 to 0.1 A

50 mVp-p
150 mVp-p
150 mVp-p

Individual Maximum Output Current
Output •1 | (+5V) | 5.0A
Output •2 ( + 12V) | 2.5A
Output •3 ( -12V) | 0.5A

Overvoltage Protection
Overcurrent Protection

Environmental Characteristics Operating temperature
Storage Temperature
Relative Humidity
| | 5.8V min. to 6.8V max. (+5V only) All outputs short circuit protected
| | 10 C to 35 C
- 20 C to 70 c
| | 1 0~ to 90~ (non-condensing)

NABU TECHNICAl MANUAl

KEYBOARD INFORMATION

General Description
The HCC keyboard is a peripheral device connected to the HCC by a 4 wire shielded cable. The cable provides power to the keyboard and transmits the serial output signal to the HCC. The keyboard assembly is housed in a two piece plastic housing containing I logic board.

Microprocessor
MC680 1 -2048 bytes ROM/ 128 bytes RAM
- 29 parallel 1/0 & 2 control lines
-3 function 16-bit programmable timer -full duplex serial communications interface -3 fundamental operating modes (uses mode 1) -internal clock generator
-enhanced 8-bit MC6800 MPU

Filter
The joysticks are remote from the keyboard enclosure by approximately 1.5 meters of cable. A filter must be added to protect the MPU from static discharge and also to prevent RF radiation from emitting from the joystick cables.

Software Interface
The internal operating software in the HCC reads a byte-wide read-only data register to obtain data from the keyboard passed on the serial link. This implies all data/commands from the keyboard are sent as 8-bit bytes.

Hardware Interface
Output from the remote keyboard will be via a two wire differential signal method similar to that described in EIA RS-422. Cable type will be a two pair 22 AWG overall shielded jacketed cable with a maximum length of 20 feet. The 6-pin DIN connector also supplies power to the keyboard from the HCC (+9 volts unregulated @200 mA).
Pin | Function
1 | unused | (Shield= GND)
2 | +9 vo 1 ts return
3 | +9 volts
4 | TX +
5 | TX-
6 | unused

I 1

NABU TECHNICAl MANUAl

Game Controller Interface
Game control connectors are 9-pin sub-miniature "D" type right angle mounted plug (male pin) connectors.
Pin | Function
I | Up Contact
2 | Down Contact
3 | Left Contact
4 | Right Contact
5 | Unused
6 | Fire Control Contact
7 | Unused
8 | GND
9 | Unused

Keyboard/HCC Communication Protocol
All information is transmitted as 8-bit bytes. The Keyboard Encoding Chart shows the encoding of data transmitted from the keyboard. Note that special function keys are always encoded with their high bit set. The keyboard only transmits information when a data value changes. Also, in the case of the key switches and game controller digital contacts, the keyboard only transmits debounced data. That is to say, the keyboard indication of an event guarantees that the event did indeed occur.

Game Controller Command Byte Format
The following 1llustrates the HCC/KBD protocol. Game controller information is transmitted by proceeding the actual data with a command byte which indicates which device the data come from. Currently defined device command bytes are:

80H JSI
81H JS2
- following byte is digital data from game controller port I
| -following byte is digital data from game controller port 2

Digital Contact (Joystick) Byte Format
Digital contact information (one 8-bit byte) is transmitted immediately after the relevant device command byte. All digital contacts on a game controller are transmitted if the state of a single contact changes. It is assumed that the digital contacts are all zero when not being used. Whenever a contact is made the corresponding bit in the data byte is set to one. As shown in the Keyboard Encoding Chart, column "AO-BO" are saved for digital contact (joystick) 'JS' device data. In byte format shown below, bits 5-7 are fixed values (header). If fire button (F) is

NABU TECHNICAL MANU"l

clear "Ax" is transmitted. If flre button (F) is set "Bx" is transmitted. Where "x" is the digital contact position.
Digital Contact (Joystick) Data Byte Format
D7 | 1 | Fixed Header
D6 | 0 | Fixed Header
D5 | 1 | Fixed Header
D4 | F | Fire Button
D3 | u | Up Contact
02 | R | Right Contact
D1 | D | Down Contact
DO | L | Left Contact

Keyboard Encoding
The keyboard encoding is shown in the Keyboard Encoding Chart. The keyboard is scanned using the "third key lock-out algorithm", which provides automatic repeat at an exponentially increasing rate on the keys held down, up to a maximum of two keys. Keys: ESC, SHIFT, CTRL, CAPS, and all SPECIAL FUNCTION KEYS are non repeatable. There is no audio feedback in the keyboard unit. If an error condition is detected by the MPU it sends the appropriate error indication to the HCC (see Keyboard Error Message Encoding). Keyboard data is transmitted in a one 8-blt byte format without a preceding command byte.

Contro 1 Keys
The following control keys are handled by the keyboard and are defined as follows. These keys have no effect on the keyboard function keys.

SHIFT- when held down causes alphabetic keys to generate capital letters, and other keys to generate the character indication on the upper portion of the key top.

CAPS - a locking key that when held down causes the keyboard to generate capital letters only. Keys other than alphabetic characters are not affected.

CTRL -when held down masks bits 6-7 of the encoded value of any standard ASCII key which is struck.

Special Function Keys (Release Coded)
The keyboard also has a set of special function keys. These keys are not affected by the SHIFT, CAPS, or CONTROL keys, and are not auto-repeatable. These keys send codes when they are depressed as well as when they are released.

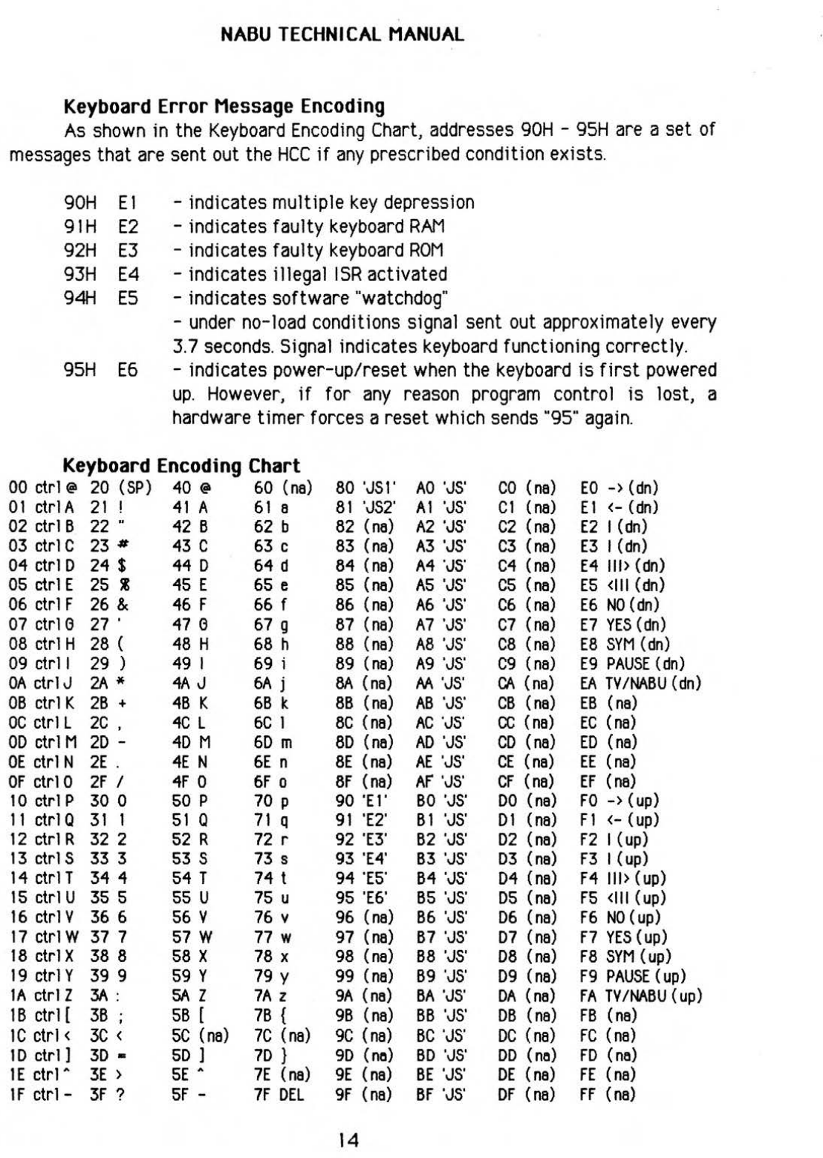
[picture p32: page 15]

Keyboard Error Message Encoding
As shown in the Keyboard Encoding Chart, addresses 90H - 95H are a set of messages that are sent out the HCC if any prescribed condition exists.
90H El | - indicates multiple key depression
91H E2 | - indicates faulty keyboard RAM
92H E3 | - indicates faulty keyboard ROM
93H E4 | -indicates illegal ISR activated
94H ES | - indicates software "watchdog"
- under no-load conditions signal sent out approximately every 3.7 seconds. Signal indicates keyboard functioning correctly. 95H E6 - indicates power-up/reset when the keyboard is first powered up. However, if for any reason program control is lost, a hardware timer forces a reset which sends "95" again.

Keyboard Encoding Chart
00 ctrl @ 20 (SP) 40 @ | 60 (na) | 80 'JS1' AO 'JS' | CO (na) | EO -> (dn)
01 ctrl A 21 ! | 41 A | 61 a | 81 'JS2' Al 'JS' | Cl ( na) | El <- (dn)
02 ctrl B 22 .. | 42 B | 62 b | 82 (na) A2 'JS' | C2 (na) | E2 I (dn)
03 ctrl C 23 # | 43 c | 63 c | 83 (na) A3 'JS' | C3 (na) | E3 I (dn)
04 ctrl D 24 $ | 44 D | 64 d | 84 (na) A4 'JS' | C4 ( na) | E4 Ill> (dn)
05 ctrl E 25 ~ | 45 E | 65 e | 85 (na) A5 'JS' | C5 (na) | E5 <Ill (dn)
06 ctrl F 26 & | 46 F | 66 f | 86 (na) A6 'JS' | C6 (na) | E6 NO (dn)
07 ctrl G 27' | 47 G | 67 g | 87 (na) A7 'JS' | C7 (na) | E7 YES (dn)
08 ctrl H 28 ( | 48 H | 68 h | 88 (na) AS 'JS' | C8 (na) | E8 SYM ( dn)
09 ctrll 29 ) | 49 I | 69 i | 89 (na) A9 'JS' | C9 ( na) | E9 PAUSE (dn)
OA ctrl J 2A* | 4A J | 6Aj | 8A (na) | AA 'JS' | CA (na) | EA TV/ NABU (dn)
OB ctrl K 2B + | 4B K | 6B !( | 8B (na) AB 'JS' | CB ( na) | EB ( na)
OC ctrl L 2C , | 4CL | 6C 1 | BC (na) | AC 'JS' | cc (na) | EC ( na)
OD ctrl M 20 - | 40 M | 60 m | 80 ( na) AD 'JS' | CD ( na) | ED (na)
OE ctrl N 2E . | 4E N | 6E n | 8E (na) | AE 'JS' | CE (na) | EE (na)
OF ctrl 0 2F I | 4F 0 | 6F o | SF (na) | Ar 'JS' | CF ( na) | EF ( na)
10 ctrl P 30 0 | 50 p | 70 p | 90 'EI' | BO 'JS' | DO (na) | FO ->(up)
11 ctrl Q 31 1 | 51 Q | 71 Q | 91 'E2' | B1 'JS' | D 1 ( na) F 1 <- (up)
12 ctrl R 32 2 | 52 R | 72 r | 92 'E3' | B2 'JS' | 02 ( na) | F2 I ( up)
13 ctrl S 33 3 | 53 s | 73 s | 93 'E4' | B3 'JS' | 03 ( na) F3 I (up)
14 ctrl T 34 4 | 54 T | 74 t | 94 'E5' | B4 'JS' | 04 (na) | F4 Ill> (up)
15 ctrl U 35 5 | 55 u | 75 u | 95 'E6' | B5 'JS' | 05 (na) | F5 <Ill (up)
16 ctrl V 36 6 | 56 v | 76 v | 96 (na) | B6 'JS' | 06 (na) | F6 NO (up)
17 ctrl W 37 7 | 57 w | 77 w | 97 (na) | B7 'JS' | 07 (na) | F7 YES (up)
18 ctrl X 38 8 | 58 X | 78 X | 98 (na) | B8 'JS' | 08 (na) | F8 SYM (up)
19 ctrl Y 39 9 | 59 y | 79 y | 99 (na) | B9 'JS' | 09 (na) | F9 PAUSE (up)
lA ctrl Z 3A : | SAZ | 7A z | 9A (na) | BA 'JS' | DA (na) | FA TV /NABU (up)
1 B ctrl[ 36 ; | 56 [ | 7B { | 9B ( na) | BB 'JS' | DB (na) | FB ( na)
IC ctrl < 3C < | SC (na) | 7C (na) | 9C ( na) | BC 'JS' | DC ( na) | FC ( na)
10 ctrl] 30 - | 50 ] | 70 } | 90 (na) | BD 'JS' | DO (na) | FD (na)
lE ctrl A | 3E > | 5E A | 7E (na) | 9E (na) | BE 'JS' | DE (na) | FE ( na)
1 F ctrl - 3F ? | 5F - | 7F DEL | 9F ( na) | BF 'JS' | OF ( na) | FF ( na)

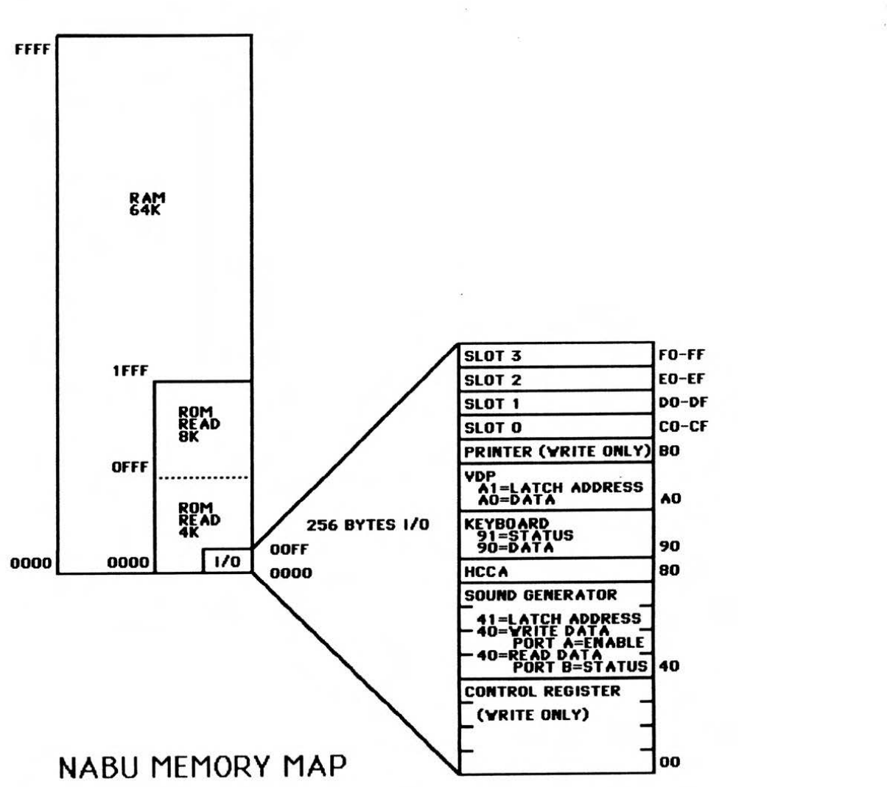
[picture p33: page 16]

FFFF

0000

RAM
64K

1FFF

OFFF

ROM
READ
OK
.•..••••.......

ROM
READ
4K
0000

256 BYTES 1/0

## NABU MEMORY MAP

PRINTER (YR ITE ONLY) 80
YDP | · A1 =LATCH ADDRESS
AO•DATA | AO
KEYBOARD
91=STATUS
90=DATA | 90
HCCA | 80
SOUND GENERATOR
41•LATCH ADDRESS
40•YRITE DATA
PORT A=ENABLE
40•READ DATA
PORT B=ST ATUS
CONTROL REGISTER
(YR ITE ONLY)

'---------------~

| 00

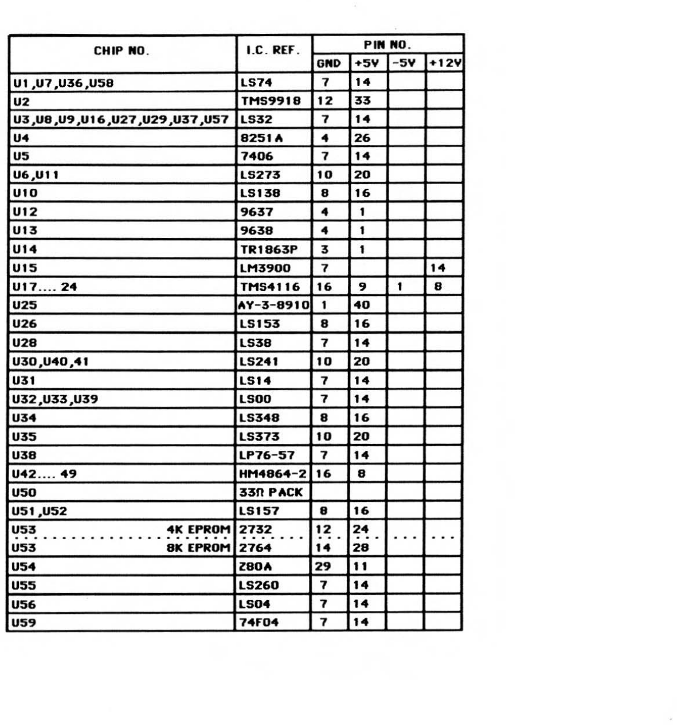
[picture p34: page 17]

CHIP NO . | I.C. REF. | PIN NO.
GND | •SY | - SY | •12Y
U 1 ,U7 ,U36 ,USB | LS74 | 1 | 14
U2 | THS9918 | 12 | 33
U3,U8,U9,U16,U27,U29,U37,U57 | LS32 | 1 | 14
U4 | 8251A | 4 | 26
U5 | 7406 | 1 | 14
U6,U11 | LS273 | 10 | 20
U10 | LS138 | 8 | 16
U12 | 9637 | 4 | 1
U13 | 9638 | 4 | 1
U14 | TR1863P | 3 | 1
U15 | LH3900 | 1 | | | 14
U17 .... 24 | THS4116 | 16 | 9 | 1 | 8
U25 | AY-3-8910 | 1 | 40
U26 | LS153 | 8 | 16
U28 | LS38 | 1 | 14
U30,U40,41 | LS241 | 10 | 20
U31 | LS14 | 1 | 14
U32 ,U33 ,U39 | LSOO | 1 | 14
U34 | LS348 | 8 | 16
U35 | LS373 | 10 | 20
U38 | LP76- S7 | 1 | 14
U42 .... 49 | HH4864- 2 | 16 | 8
uso | 33fl PACK
US1 ,U52 | LS157 | 8 | 16
US3 8K EPROH 4K EPROH | 2732 2764 | | 12 14 ... | 24 | 28 . . . | . .. | . .. US3
US4 | Z80A | 29 | 11
uss | LS260 | 1 | 14
US6 | LS04 | 1 | 14
US9 | 74F04 | 1 | 14

~ ²B

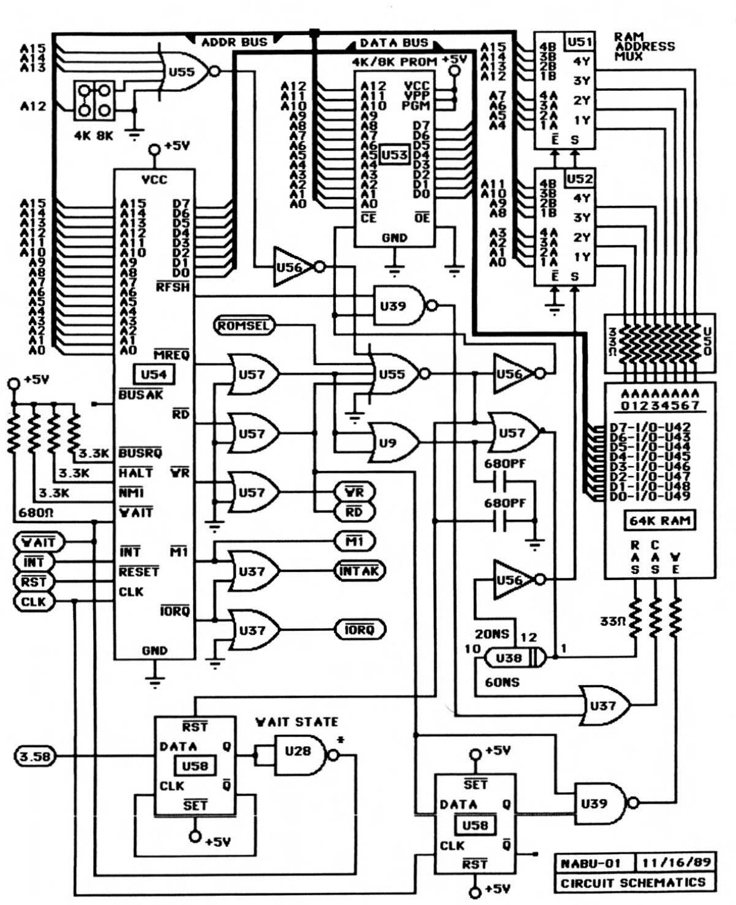
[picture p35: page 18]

I | .... ADDR BUS P' | _..DATA BUS ..
~ ⁴⁸~ | RAM
A1S | A1S | ADDRESS
A11 | 4K/8K PROM +6Y | A14 | 38 4Y | MUX
A1 | ~iii.:
U5'l-

A 3
A12 | 18 3Y
IZ ~ ~ | A12 | A12 | YCC | ~
~ I | All | All | ypp | ~ | A7 | 4A 2Y A12 | "- | 0 | ,__ | A10 | AIO PGM | ,.._ | A6 | 3A
A9 | A9 | AS

~ ²A IV AS
~' D7 | ~ | A4 | lA
41( 81( -~ | A7 | D6 | -~
?+5Y | A6 | ~ | A6~D5 | E S
A5 | A5 U53 D4 | -~
A4 | A4 | D3 | f f ,___~
vee | A3 | A3 | D2
A2 | A2 | 48~ 8& | -~
AI | AI | -~ | "'A AI | ~ 38 | 4Y Al5 | A1~ | 07 | AO | AO | ,___ | A9
~ 28
A14 | AI | B~ | ~ | CE | OE | A8 | 18 3Y A13 | A13
A12 | AJ2 | g~ | ...- | ~
A3 ~ 4A
All | A I | ~ | OND

i~ 2Y
AIO | ~iii.: | AIO | D2 | -~
~~ | -!- | ~A ~ | IY A9 | A9 | D1 | -~
~ AS | A8 | DO | ~ | - . | -~ | E S A7 | ~l RFSH A6
U39~ A5 | AS | ~~ A4 | A4
A3 | ~~ ~~ | \.ROHSELJ | 3 | u ~ | A1 | I | 3 | 5 AO | '~..: | AO --
~ HREO | n | 0
U5~ | • I U541 | )us7 o•sv | r--l
8USAK | - | AAAAAAAA
- | RD | ~· | 01234567
::: ~ 41 ~ 41 ~ | - | us7 ~--
| | | ~ D7-I~O U42
$: ~: .. : ~ | ~ Jus7 | U9 | D~ 1 O- U43 ~ 4 .. 411 ~3 3K | ~ D | I~O-U44 8USRO | - | - | 04-1 O-U45 - | ~80PF | D3- ll0- U46 3 .31( | HALT YR | - | ~ D2 I~O-U47
3 .3K | NHI | Jus7 | YR) | 6:fpf I | ~ Dl-1 O- U48
~ | D0-170-U49
680fl | YAIT | - | y RD )
-.: | - | 1641( RAMI . ~ YAIT}-- | INT | HI | ~H1) | - | R c - | A A y ~ INT
RESET | )U37 | ,.INTAK)
~~ | s s E
RST | r--l
CLK | - CLK
I ORO | - | 41 ~ | 4 ~ 41 ~
jU37 | { IORO) | 33n: >- : ~ :
20NS | 12 | 4 >-4 ~ 4 ~ OND | r~ | 10 | I
-!- | rt U38)·~
60NS . | ·-

U3Y-- '
RST | VAIT STATE
(3.58) | DATA | 0~ | U28-p- | ?+5Y
- I use I
CLK | 0 | SET
1 | SET | n | ~
DATA | 0 | U39F I o.5 Y | I | ..... | I ussl
CLK | ij ...- | f-.-
RST | NABU- 01 | I 1/16/89
6+5Y | CIRCUIT SCHEMATICS

~~· | ~~'!'! | <>i LED3 |
~· ~ ~~'!'! | 1 | LED1

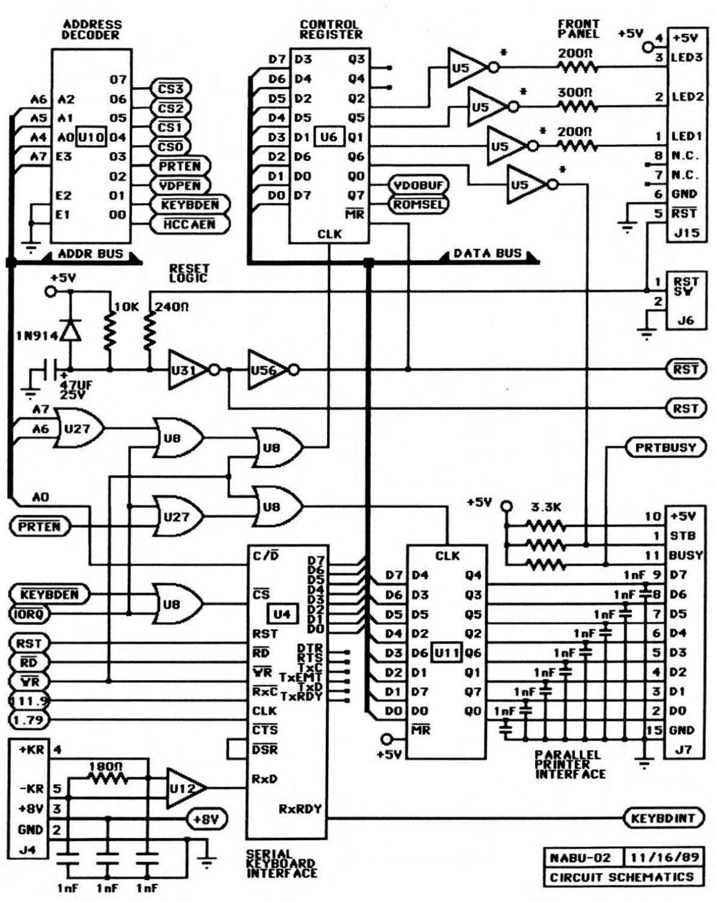
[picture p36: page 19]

ADDRESS
DECODER

07
A6 | A2 | 06 H cs³ )
A5 A1 | 05 H cs² )
A4 AOlU1 olo4 ~ ~:: ~ A7 E3 | 03 H PRTEN)

02
E2 r-- E1 ~

H YDPEN) 01 H KEVBDEN) 00 H HCCAEN ) -..:- ...._ ___ _.

- ...,. ADDR BUS ...
+5Y

~ , D6

D5
D4
D3
~2
D1
DO

CONTROL
REGISTER
D3 | 03 | ~
D4 | 04 | ~
D2 | 02
D5 | 05
D1~01
D6 | 06
DO | 00 H D7 | 07

H MR

CLK

FRONT
PANEL | +5Y 4 | +5Y
~ • | 300ft | 2 | LED2
1 us "'21""' | ........ ~........ | |
| | 8 | N.C.
~ | 7 | N.C. YDOBUF) | ;7-- | -6 | GND

ROMSEIJ

## -!-~ RST

J15
.... DATA BUS ...
1 | RST ~ | ~---------~-~--+---------~---~SY 2 -b J6

~-----+-~~-----------~---~~RST)

- A6 JU27

## - _Jus

- r{PRTBUSV)

AO
(PRTEN~ | -
- Ju27 | Ius
C/D ...._+-~-----~ | D7 | CLK
06 - | ~ D7 D4 | 04
- ( KEVBDEN ~}-+-+--\I US

(IORO.,

Ds.._....,~ ....
>---4 cs | 81 | Ill. D6 D3 | 03
~~~ | D5D5 | 05
~--~-------~RST | | ~ D4 D2 | 02
}---+---------4 RD | Bfl ~ ~ D3 D61!!:!)06

~ RST
RD

1nf 9 D7
1nf*8 D6
1nf* | 7 D5
1nf: := | 6 D4
| | | 1nF:Ir: | 5 D3
.... __ ,._ ______ -tvR Tx\~i~ | D2 D1 | 01 | 1nf~ | 4 D2
9------------4RxCTxRDY ~ | D1 D7 | 07 | 1nF:Ir: | 3 D1
l------------4 CLK | \.. DO DO | 00 1 nf: ~ | 2 DO

~ YR

'" • :j 1.79

+KR ..
J4 | - looo | - | looo | - looo

## TTT

1nf | 1nf | 1nf
CTS | Q- MR | ~ | 15 GND L DSR | L- | __.~~ J7

RxD

RxROY

+SY ....__ __ ___. | fllrlf~~E | -.:

~----------------------------~{KEYBDINT)

NABU-02 11/16/89
CIRCUIT SCHEMATICS

- | - | ...... | r-t | r-t
)U29 | .... | r-t | r-t ~

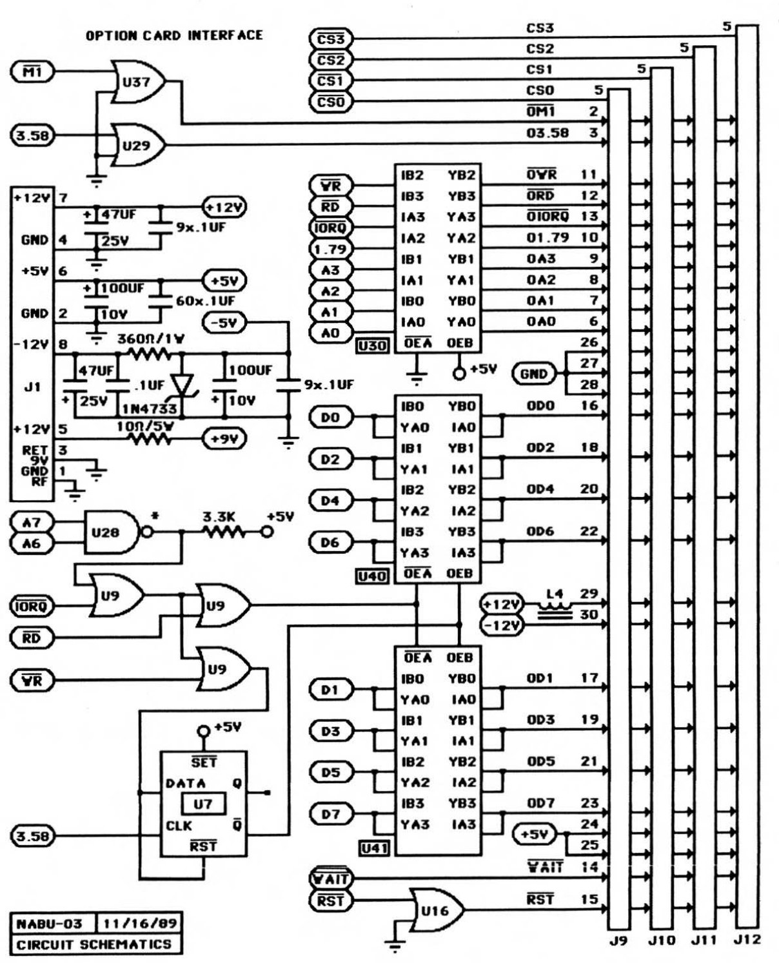
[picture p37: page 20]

OPT ION CARD INTERFACE | ~ CS3
CS3 | 5r--

~ CS2

CS2 | 5~
( 111) | CS1 | 5r--
~ CS1 ,.....)u3"9- | cso | 5r-- I..- | ~ cso
- | 0111 | 2
(3.58; | 03.58 | 3
-~ - | OYR ~ YR
IB2 | YB2 | 11 | r-t | H | ~ +12Y 7
ill7UF I | {+12Y)
183 | YB3 | ORO | 12
l RD | H | r-t | H
IA3 | YA3 | OIORO 13 T2 | ,-9x.1UF | ~IORO | H | H | r-t
GND 4 | 5Y | ~ 1 .79
IA2 | YA2 | 01 .79 10 | H | H | ~ -:!:- | IB1 | YB1 | OA3 | 9
+5Y 6 | . | ~ A3 | H | H | ~
!.l! OOUF ..l.. | ~ | ~ | IA1 | YA1 | OA2 | 8
A2 | r-t | H | H li1
T60x. 1UF | ~ | lBO | YBO | OA1 | 7
GND 2 | OY | ( - 5Y' | A1 | H | r-t | ~
~ | lAO | YAO | OAO | 6 | H | .... | H
-12Y 8 | "'*'" 3~~!1. '._1 y | __, | AO
lu3ol | OEA OEB | 26 | H | .... | ~ .h Jd_ .-,,.~~ _h, | --!- 6+5Y | 27 7UF | 100UF | (GND~ | .... | .... | H
.J1 | +[2· 11

T.

1

.1UF | ~ +Jil | =~9x 1UF | . | 28
5 | H | .... | ~ y 1N4733 | + 10Y | - | lBO | YBO | ODO | 16 (oo' | H | .... | ~ L | u +12Y 5 | 111!1~~ | , ') | ~ | YAO | lAO
TTT, | "-+~Y | -:
RET 3 | - | • | ' | IB1 | YB1 | 002 | 18 ~y | ..L | ( 02 ~ | ~ | H | ~ L | u GND 1 | - | YA1 | IA1
RF '-!- "
(04;
IB2 | YB2 | 004 | 20 . | ~ | r-t | ~
~ A7 | }- | L | u U28 \_•
3 .3K | +5Y | YA2 | IA2
- . .&.&.& | -o ~ A6 | }- | r | TTTT

(06;

183 | YB3 | 006 | 22 | H | H | H L | YA3 | IA3 | w
Lr- | lU40I | OEA OEB
)u~ | - | L4 2~
QORO~ | lu~ | ~+12Y~ | .... | H | H - | =30 | .... | H | H
(RD ~ | - | (- 12Y
lu0- | OEA OEB
-(vR; | lBO | YBO | 001 | 17
- | - | ( 01; | r-t | r-t | H L | u YAO | lAO
?+5Y | ( 03 ~ | IB1 | YB1 | 003 | 19 | r-t | r-t | r-t L - | YA1 | IA1 | u

SET

(05 ~ | IB2 | YB2 | 005 | 21 | r-t | H | ........ DATA | 0 | 1: ~
YA2 | IA2 | u [ill | ~
(07 ~ | IB3 | YB3 | 007 | 23 | H | H | ~ CLK | ij | L | YA3 | IA3 | _j (+5Y; (3.58) | - | 24 | H | .... | ~ - | RST | lU41I | 25 | .... | .... | ~
- 'WAIT 14-.,.

l'fAIT

·- | H | H | H
~ RST | RST | 15
- | U16 | H | H | H
NABU-03 | 11/16/89 | _[l- | ....._ | ...... | ...... | ....._
CIRCUIT SCHEMATICS | .J9 | ... 1 0 | ... 1 1 ... 1 2

# ----+~-~U33~~---- :~ =~ ~ ~ IK

## ~ 8~ lu3sl 8~ ~

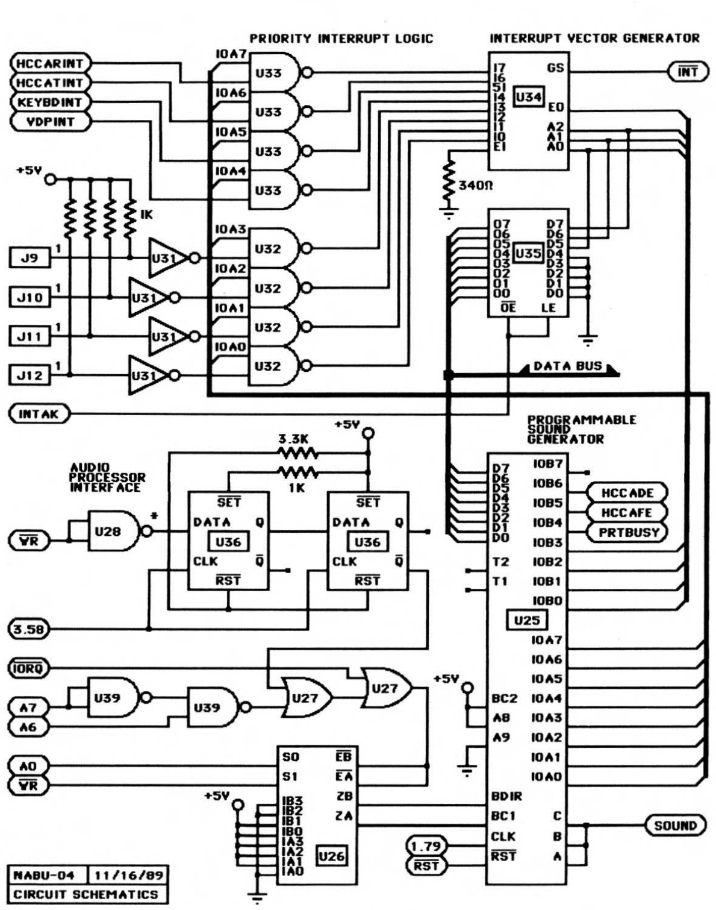
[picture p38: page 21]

PRIORITY INTERRUPT LOGIC | INTERRUPT VECTOR GENERATOR
IOA7 | "'\.
~ HCCARINT J------,~ | , | U33 \nl[).----------t17 | GS 1-------t! INT)
~ HCCATINT t-------. | F | 16 | ....
~ ..... -~, | J | ~J lu341 ~ ICEYBDINT Jo-----. | ~ | U33 h | 13 | EO t------""""'
~ YDPINT | -----tt-----4 | F | li | A2t---...-------~ IOA5 | \_ | ~~ | t~t--....... -+--~

--·~--t U33 y IOA4t---c

~=~~~ | IOA3--~ ~ ~---~ 1 | 414 | ~ ~"' - | ~2 ..J9 : | U3 :ll.-c>o.---1

IOA2t---c

J1o:

1
r....

~ IOA1 t--c:
.-----. 1 | r--....._ | U32 \lt:._:>------ JI1 :t-+-..... ---t[u~ | r-

•SY.-
\...o- | -.-

U32

41~
:· 340fl
-.: ~· ----. 07 | 07 t-+--+-....
•'·---- 06 | 06 ~ .........

"'--

"'-,_._,02 03 | 03 02 ~ ~ .,. _ _,01 | 01 ~
.,. _ _, 00 | DO ~
OE | LE
I --- ..,..... | IOAOt--c:
.-----. 1 | ........:. | 'f' | U32 \.It:._:>-____ _. | .... DATA BUS ...
Jl2:t--._--~~ L. .. ~;:::.r- | ~. .... ~ | -1 .. (INTAIC}~---------------------.--_.... ..-sv0

AUDIO
PROCESSOR
INTERFACE | I

3 .3K .&&&&

TTT'I'
.&&&&
TTT,..
IK
SET | SET
r h | DATA | 0 | DATA | 0 (vR'} | u
28 J[r_>--~.....,. I u361 t-----t I u361 | -
CLK | 0 "--- | CLK | 0 ~~ | ,- | - | - RST | RST
--... | 07 -§6
:== oi .-02

## .-01 ..._-oo

- T2
- T1

;6816 AMMABLE

GENERATOR
:::: -----
~ | .... HCCAOE ) lOBS ~ HCCAFE ) IOB4 ~ PRTBUSY) IOB3 t-------'

IOB2 t-------'1
IOB1 | ~ t-------'1
lOBO | ~
lu2sl t----------'

1 -

(3 58~~----~-------~

~fii~OiR~O~~-------------J-----, ---
- | \_ | ......,- lu20- •SYO
( A7 | r U39 J-ID---tU39 ~ | lu27 | _y- | - BC2
- | - | AS ( A6 ~----_,........__, | -
- A9
~ AO 1--------------tso
~ YR J--------------451
•SY 0 r- 183
~ II~

NABU- 04 11/16/89
CIRCUIT SCHEMATICS

t-+--1180
t-+--tiA3
t-+--tiA2
---t~IA1 ~ lAO
_._
EB | ~
ZB | BDIR t--------1 ZA | BC1

CLK
1. 79 J-----1 RST
RST J----1
IOA7 | ~ 1--------"
IOA6 | ~ t--------'1
IOAS | ~ 1--------"
IOA4 | ~ 1---------'1
IOA3 | ~ 1-------------'1

### IOA2 1----------'1

IOA1 | ~ t----------'1
IOAO | ~ t--------

c t--.----~~SOUND) B
A -

~

# I I I

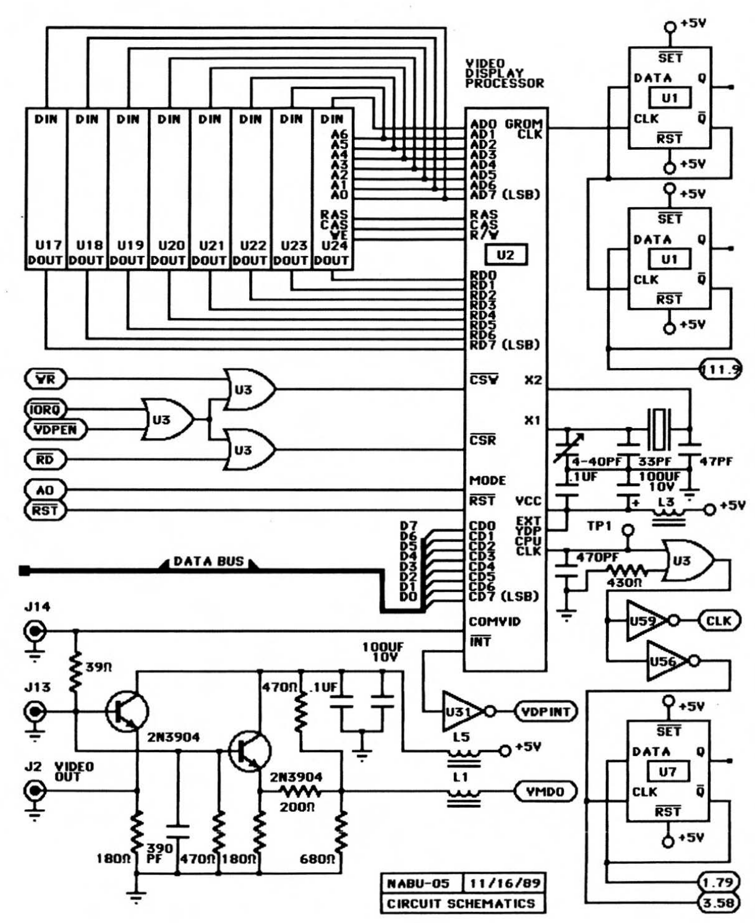
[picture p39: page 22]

?+ 5V

VIDEO | SET
DISPLAY | DATA | 0 PROCESSOR | - | [ill | ~
ADO GROM | CLK | ij
AD1 | CLK | RST

I--
AD2
DIN | DIN | DIN | DIN | DIN | DIN | DIN | DIN | I
| | | | | | | A6 A5
AD3
AD4 | 0+5V
AD5
~8, (LSB) | <j>+5V

A4
A3
A2
A1
AO
RAS | SET c?s R y | DATA | 0
~ | r-- | [ill | 1--e
IBY | | CLK | ij
IBi I | RST | - I

RD4
0+5V IB~ RD7 (LSB)
( YR ;)--------"""""' | CSY | X2

! 11.~
- - | U3 - | - | ---'l
~ YDPEN; | ~ | X 1 | ~ ~IoRee | .'""'--. -~ | O
_ | - | ...... 1
U3 | :)------------tCSR | -~ | _L | -~ ( RD }t----------1 | ,-'4- 40Pf'T33Pf -r-47Pf
---- - | --- | MODE | .1UF | I 100UF
~ AO t-----------------------1 | -- ~·10V-:!=- RST | VCC - r- | T+ L3 ~ | +5V ~RSTJ-------------------------~ | ~
- | 07 | COO | ~~~ - | TP1 ? = 06 , | CD1
05 | C02 | CPU | -
D3 1>4 C I'"_ | CD3 CD4 | CLK ~
I 470PF :A a. a. a. | IU3~
02 I'".: | CCD56 | - :J l3lJhY L- BA ~- _ c87 (LSB) II"'

~DATA BUS.._.

d14

COMYID --=- . ~-~-------------------~

d13
~

d2 YIDEO
~OUT

100UF
10V

INT
r----1

# ~~YDPINT) L5

•• _...l'\+5V
~-

NABU-05 11/16/89
CIRCUIT SCHEMATICS

'------(1. 79)
...._ ____ -4.3 .58)

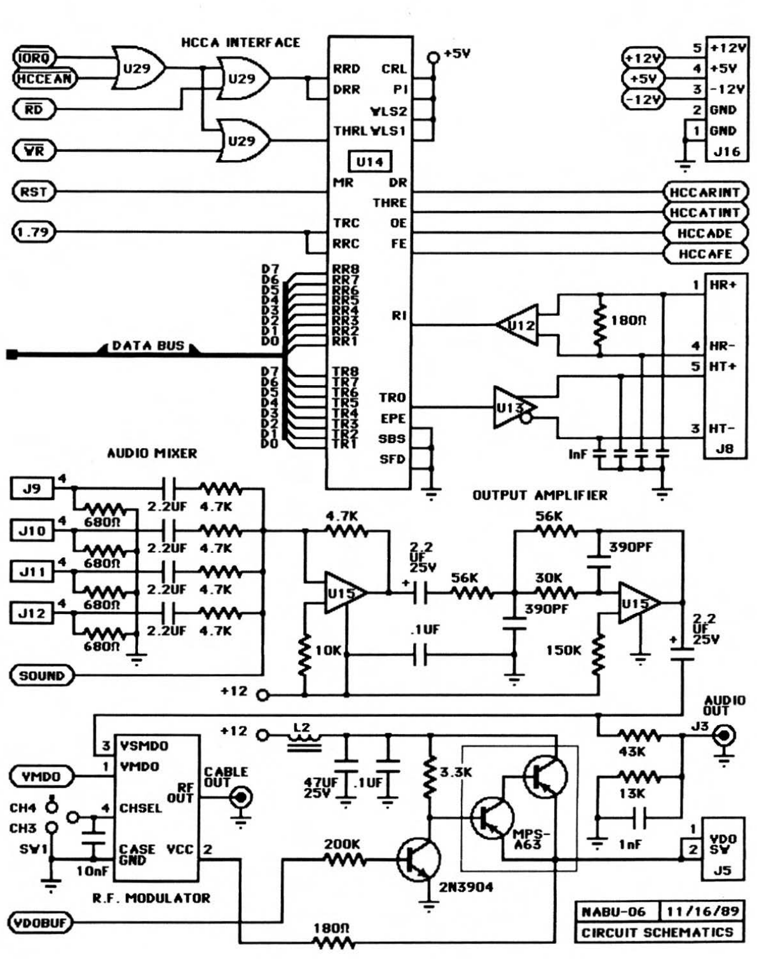
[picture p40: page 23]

- - HCC A INTERFACE
QOROL | - ~ | )U29
| | | RRD | CRL
IJtCCEAft..,
~ | I | L | DRR | PI
( RD) | - | YLS2 - | ~ - | THRLYLS1
)U29 {YRJ | - | HR
~ DR (RST~
- THRE
| | TRC | OE
(1 .79J | L | RRC | FE
07 | RR8
06 -- | RR7
B~ | II~ 03 | 113 Rl
g~ | RR
~DATA | DO | RR1 BUS•
07 | TR8
D~ | T~7 T 6 | TRO 84.- | TR5
TR4 II t | EPE

# fit SBS

AUDIO HIMER | - | SFD
I | 4 | I l | .&.&.&.&

4 .7K

- +12

+12
3 | YSHDO
1 | YHDO | CABLE
RF | OUT

## 25Y 47ui_I1u~ OUT

CHSEL | - - CH3 | - CASE YCC | 2

GND
-. R .F. HODUL ATOR

180fl

o+5Y

~
tt-

~
-..:-

.1Uf

- | 5 | ~12Y
(+12Y | 4 | +5Y ~ +5Y
3 | - 12Y 12Y
- | 2 | GND
| r--
| 1 | GND
| P-- | J16
| -.=-

HCCARINT)
HCCATINT ~
HCCADE )
HCCAFE )
| 1 | HR+
~~ ~1800
''1 > | 4 | HR-
| 5 | HT~
~ | I U1~
vv--, | 3 | HT-

# lnrf 'f Tf

OUTPUT AHPllf IER
56K

J8

I 150K
~t2 + 25Y

NABU-06 11/16/89
CIRCUIT SCHEMATICS

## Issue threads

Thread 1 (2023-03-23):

Incorrect labeling of J16 Power connector

kpishere, 2023-03-23:
The document Nabu_Computer_Technical_Manual_by_MJP-compressed.pdf on the last page appears to have incorrect labeling of the J16 connector.  With Voltmeter, I read the following.

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

Pin 4, I'd expect to be -12V but it does not appear to work.  Anybody else seeing that?

ayourk, 2023-03-23:
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

That sounds about right.  There are modifications that are typically made to the developer machines using a fat bodge wire on the bottom of the main board to fix this: https://www.youtube.com/watch?v=i-kjwh8fhdk

kpishere, 2023-03-23:
Thanks!

Closed 2023-03-23.

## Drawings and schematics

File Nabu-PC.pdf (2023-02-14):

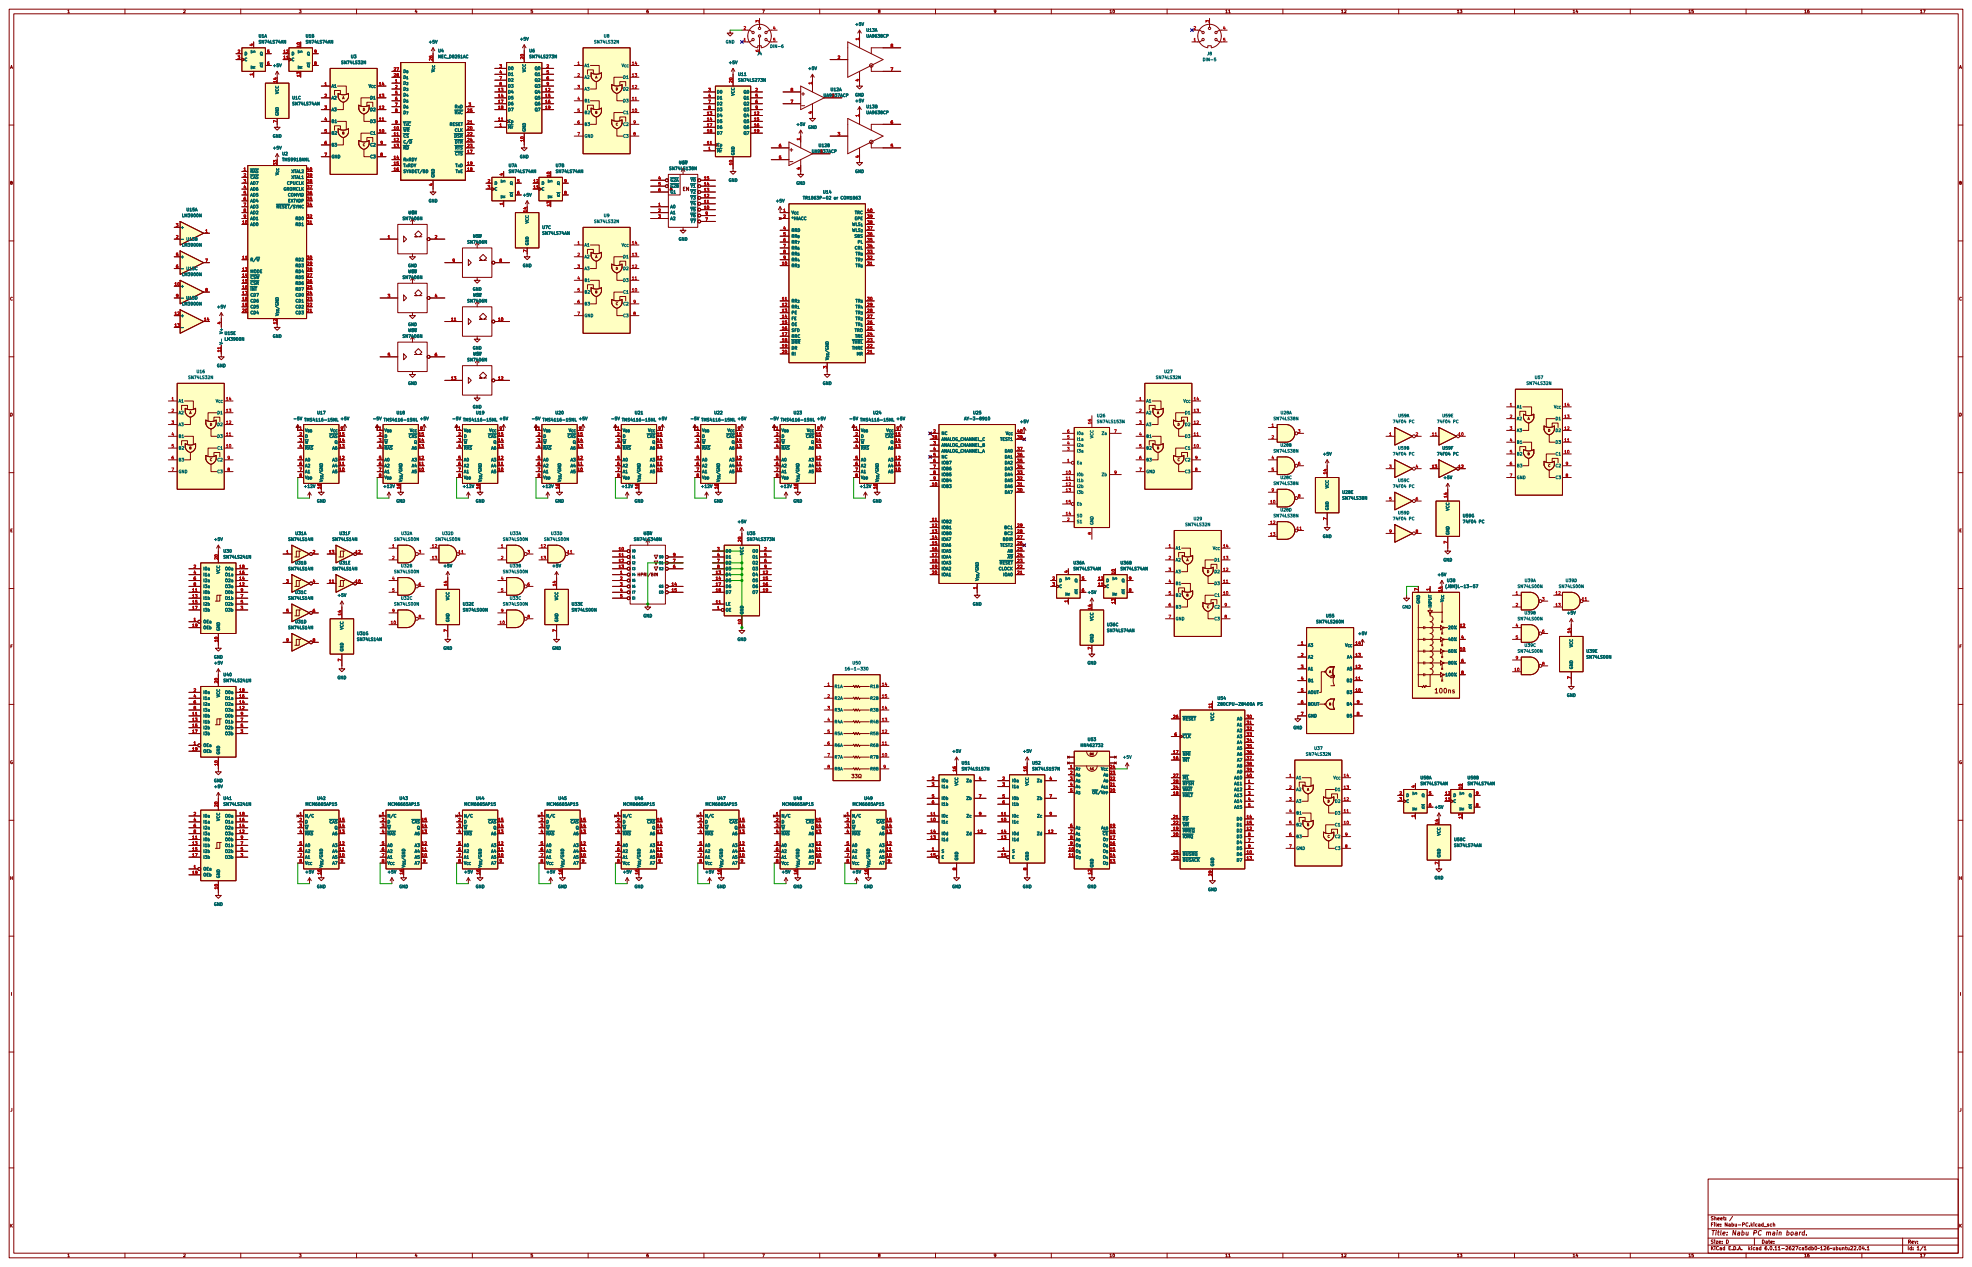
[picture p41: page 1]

Id: 1/1 Title: Nabu PC main board. File: Nabu-PC.kicad_sch Sheet: /

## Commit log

2023-02-09 Laying out the ICs in the schematic; Datasheets in Doc/*
    [Nabu-PC.kicad_pcb, Nabu-PC.kicad_sch]
2023-02-10 Added Footprints and Datasheet for both the DIN5 Adaptor connector and DIN6 Keyboard connector.
    [Nabu-PC.kicad_sch]
2023-02-14 Created new symbols, updated existing symbols to simplify the layout, Added new hard to find Datasheets. Almost done laying out all of the ICs!
    [Nabu-PC.kicad_sch]
2023-02-14 Finished laying out all of the chips; Added a few more Datasheets.
    [Nabu-PC.kicad_sch]
2023-02-18 Consolidating multi symbol chips into 1 symbol; Added a missing Datasheet.
    [Nabu-PC.kicad_sch]
2024-03-20 Updated README; Committing latest changes.
    [Nabu-PC.kicad_sch]
